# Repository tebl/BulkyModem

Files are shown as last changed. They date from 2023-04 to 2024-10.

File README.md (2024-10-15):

# BulkyModem
Back in the old days I, like many others, had a modem. Wasn't quite as old that it used an acoustic coupler, but certainly old enough that it still made exciting clicks when connecting up to things. It also made a lot of horrible shrieking noises when it finally got to talk to an actual computer, if someone else was to pick up the phone while you were using it - you'd usually get to hear a bit of swearing before enjoying the task of doing it all over again. The *BulkyModem* doesn't even hope to do all of those things, but it does allow me to have a go at dialing into a *BBS* from the comforts of my old PCs again. It doesn't do any of that over an analog phone line, because: A) Those no longer exist, and B) We're living in the far distant future, and we now have Wi-Fi!

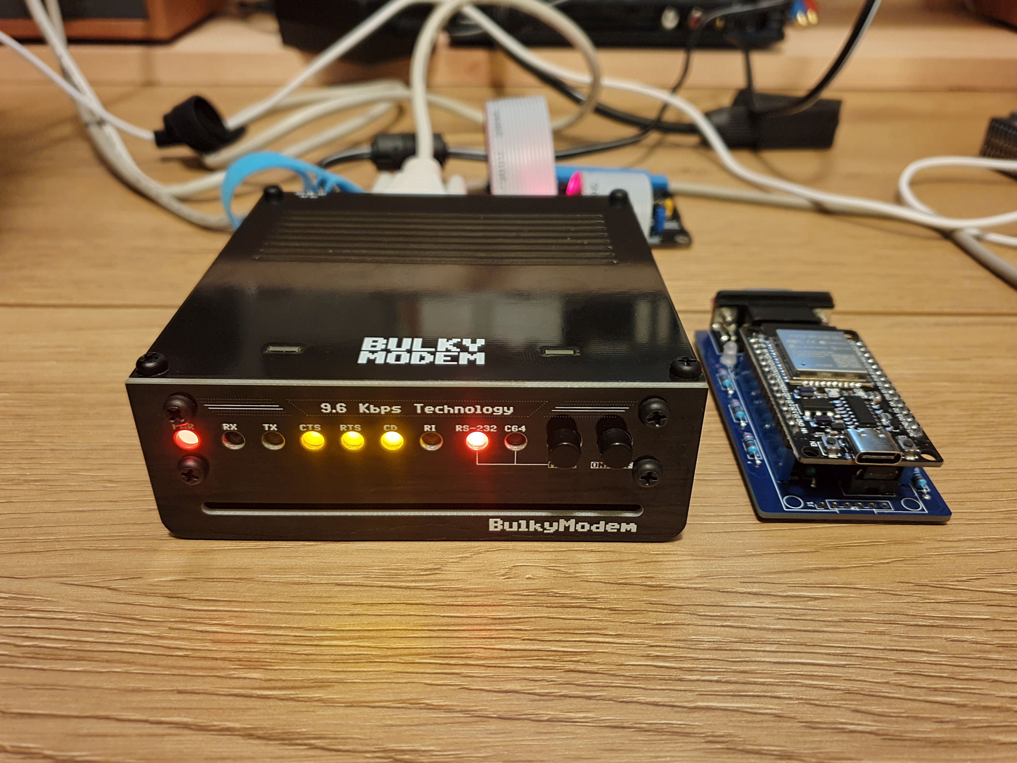
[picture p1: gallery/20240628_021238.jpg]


While there are many options for modems out there that already do the same thing, even quite cool ones that are still being hand-assembled and sold as *Retro WiFi modems* in just about every corner of the world. Or, so I assume anyway. The reason being that if you can find a suitably aged *nerd* tinkering away on their old computer, then they might have been part of the golden age of communication. The other earlier golden age, the one we were talking about before the World Wide Web was unleashed upon the world. Anyway, if you find one of those then there's probably a modem already in their workshop, or possibly in the mail somewhere. So where does my little project fit into all of this? Not sure, but I sure wanted to build one. And the solution I came up with, temporarily fits a very specific spot on my desk.

Where does this one differentiate from the rest of the options then? For that I need to say a bit about my goals when developing it. First off, I wanted to merge old technology with the new - that's not a shocker to anyone who has seen any of my other projects. The second is where this might start becoming of interesting to you, it's the part where I didn't want to build a modem that would only ever work over either *RS-232* - or - attached to a *Commodore 64/128 User Port*. Instead of forcing you to choose, I put a *mode*-button on the front that rewires things between the two modes. Technically that still requires a choice, but did I mention that it was a button? And it's implemented in *hardware*! 

'That's madness', I clearly hear you shouting at the screen. Possibly scaring a cat while you were doing so. Well, it certainly is!

Which is probably the reason for why I started this project all the way back when these retro modems were  still considered a *new* thing, it just took me a while. Mostly because I couldn't get all of it working at the same time. It was never really supposed to work while connected to two different systems at the same time, that would be a whole different bag of crazy - I just wanted the *mode*-button to work as previously advertised. And two years later it mostly does. Turns out that juggling chronic fatigue, *RS-232* signal names and a screaming toddler at the same time, also means that you're bound to strike out quite a few times. My last stumbling block was that I had one ESP8266 development boards that worked perfectly, and five that mostly did nothing. After three revisions I ended up with five that worked with the addition of a simple diode, it was just that without it - I couldn't get anywhere without figuring out how to actually use an oscilloscope. The twist at the end was that the final board that didn't work at the end, wasn't a twist because the working one just kept working. The sixth was just broken from the start, a fact that seems to align with my batting average for cheap development boards.

As for going all the way in order to not require any changes to the firmware, I later added some *optional*. Some of those will require an update to the firmware, if I ever get around to making them. We'll well and truly burn that bridge if I ever get around to crossing it, but for now - just pretend that those don't exist! You didn't need them anyway.

For the project background, all of this started with an article: [Build your own 9600 Baud C64 WiFi Modem For $10](https://1200baud.wordpress.com/2017/03/04/build-your-own-9600-baud-c64-wifi-modem-for-20/). It goes through all of the steps for building a simple version of this with a specially prepared version of the [Zimodem](https://github.com/bozimmerman/Zimodem)-firmware that was made available when the article was written. For a new project that sounds more outdated than retro, I'm going with the shiny new version instead.

- [1> Modules](#1-modules)
  - [1.1> BulkyModem](#11-bulkymodem)
  - [1.3> BulkyModem-32](#13-bulkymodem-32)
  - [1.4> BulkyModem-32 (Mini RS-232)](#14-bulkymodem-32-mini-rs-232)
  - [1.5> BulkyModem Terminal](#15-bulkymodem-terminal)
- [2> Adapters](#2-adapters)
- [3> Acknowledgements](#3-acknowledgements)

# 1> Modules
For the technical details as well as information regarding the devices included in this specific GitHub-project, consult the table below to jump to that particular section. Note that in order to successfully use the *BulkyModem* or *BulkyModem-32* along with a Commodore 64, you will also need the *User Port*-adapter found within the [adapters](#2-adapters)-section.

| Module | Description |
| --- | --- |
| [BulkyModem](#11-bulkymodem) | *BulkyModem*-variant based on ESP8266.
| [BulkyModem-32](#13-bulkymodem-32) | *BulkyModem*-variant based on ESP32.
| [BulkyModem-32 (Mini RS-232)](#14-bulkymodem-32-mini-rs-232) | "Mini"-version of the BulkyModem-32 with an RS-232 interface.
| [BulkyModem Terminal](#15-bulkymodem-terminal) | An instant-on video terminal based on [VersaTerm](https://github.com/dhansel/VersaTerm)

## 1.1> BulkyModem
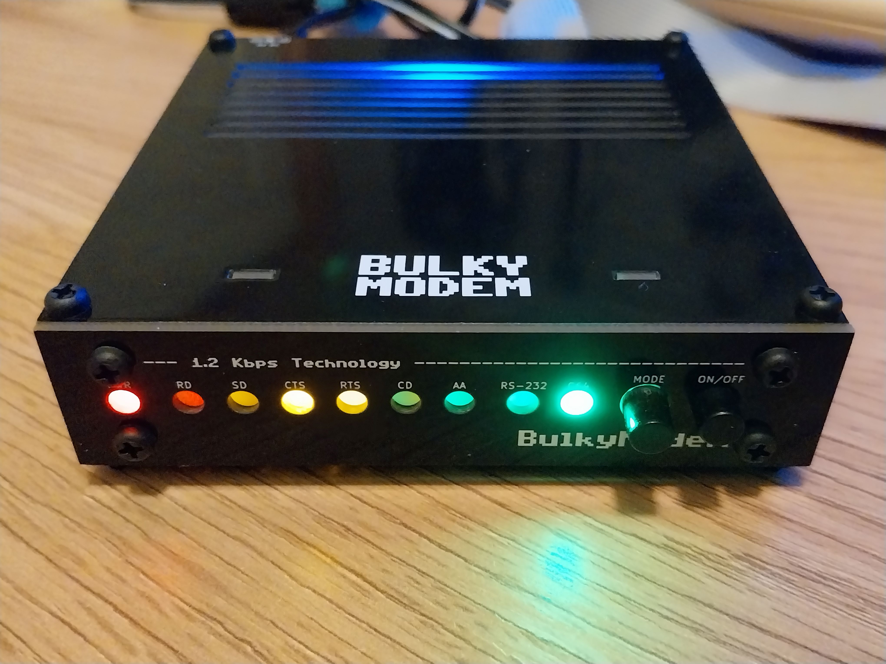
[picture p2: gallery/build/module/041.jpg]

**Status:** Completed

This is the main module of the project, if you came here looking to build an ESP8266-based retro modem then you've come to the right place. You have the option of going the cheaper route of just building things up on the basic module by itself, consisting only of the main module and nothing else. Alternatively, and this is probably the only reason to build a *BulkyModem* - and that's to build the whole thing as shown above. Note that the list below will include alternate versions of boards, so you need to decide which of them you'll need based on their description.

| Module | Required | Description | Documentation | Order |
| --- | --- | --- | --- | --- |
| [BulkyModem](https://github.com/tebl/BulkyModem/tree/main/BulkyModem%20Module) | Yes | Main module | [Documentation](https://github.com/tebl/BulkyModem/tree/main/BulkyModem%20Module), [BOM](https://github.com/tebl/BulkyModem/tree/main/BulkyModem%20Module/README.md#3-bom), [Setting it up](https://github.com/tebl/BulkyModem/blob/main/documentation/setting_it_up.md), [Getting started](https://github.com/tebl/BulkyModem/blob/main/documentation/getting_started.md) | [PCBWay](https://www.pcbway.com/project/shareproject/BulkyModem_e6d2ed59.html)
| [BulkyModem Panel](https://github.com/tebl/BulkyModem/tree/main/BulkyModem%20Module%20Panel) | Recommended | Adds a vertical surface for mounting switches and LEDs. | [Documentation](https://github.com/tebl/BulkyModem/tree/main/BulkyModem%20Module%20Panel), [BOM](https://github.com/tebl/BulkyModem/tree/main/BulkyModem%20Module%20Panel/README.md#3-bom) | [PCBWay](https://www.pcbway.com/project/shareproject/BulkyModem_Panel_a5862704.html)
| :repeat_one: [BulkyModem Panel B](https://github.com/tebl/BulkyModem/tree/main/BulkyModem%20Module%20Panel%20B) | Alternative | Similar to above, but uses an RGB LED as a power indicator. Lights up a different colour when in *standby*. | [Documentation](https://github.com/tebl/BulkyModem/tree/main/BulkyModem%20Module%20Panel%20B), [BOM](https://github.com/tebl/BulkyModem/tree/main/BulkyModem%20Module%20Panel%20B/README.md#3-bom) | PCBWay
| [BulkyModem Front faceplate (FP3)](https://github.com/tebl/BulkyModem/tree/main/faceplates/BulkyModem%20FP3) | Recommended | Decorative front panel, mounts on either of the front panels. Has a more futuristic design. | [Documentation](https://github.com/tebl/BulkyModem/tree/main/faceplates/BulkyModem%20FP3) | [PCBWay](https://www.pcbway.com/project/shareproject/BulkyModem_Faceplate_FP3_e1a3cebd.html)
| :repeat_one: [BulkyModem Front faceplate (FP2)](https://github.com/tebl/BulkyModem/tree/main/faceplates/BulkyModem%20FP2) | Alternative | Decorative front panel, mounts on either of the front panels. Has a more minimalistic design. | [Documentation](https://github.com/tebl/BulkyModem/tree/main/faceplates/BulkyModem%20FP2) | PCBWay
| :repeat_one: [BulkyModem Front faceplate (FP1)](https://github.com/tebl/BulkyModem/tree/main/faceplates/BulkyModem%20FP1) | Alternative | Decorative front panel, mounts on either of the front panels. Shorter version (same as shown above). | [Documentation](https://github.com/tebl/BulkyModem/tree/main/faceplates/BulkyModem%20FP1) | [PCBWay](https://www.pcbway.com/project/shareproject/BulkyModem_Faceplate_FP1_738ec333.html)
| [BulkyModem Top/bottom faceplate (FA1)](https://github.com/tebl/BulkyModem/tree/main/faceplates/BulkyModem%20FA1) | Recommended | Decorative faceplate used on the top of the device, can also be used on the bottom in combination with front faceplate [FP2](https://github.com/tebl/BulkyModem/tree/main/faceplates/BulkyModem%20FP2)/[FP3](https://github.com/tebl/BulkyModem/tree/main/faceplates/BulkyModem%20FP3). | [Documentation](https://github.com/tebl/BulkyModem/tree/main/faceplates/BulkyModem%20FA1) | [PCBWay](https://www.pcbway.com/project/shareproject/BulkyModem_Faceplate_FA1_2696aeda.html)

**NB!** Make sure to follow the links for each of the modules, especially when you're looking into ordering the parts needed to complete the device that you want to build. Those modules are listed with their own link to a BOM, or at least what I would call one. Also keep in mind that to use this with a Commodore 64, you need the *User Port*-adapter that's found in the [adapters](#2-adapters)-section.

## 1.3> BulkyModem-32
BulkyModem
**Status:** Working, documentation missing

The *BulkyModem-32* is a variant of the modem based on the ESP32, offering some additional features when compared to the [BulkyModem](#11-bulkymodem) that was based on the older and more limited ESP8266. More specifically you'll have access to several additional commands and protocols when using this variant, it also includes an SD-card slot so that you can transfer files between the computer and the modem.

For building one of these things you have the option of going the cheaper route of just using the main PCB, leaving you with the main module and nothing else. Alternatively, and this is probably the only reason why you'd want to build a *BulkyModem* - and that's to go for the whole thing as shown above. Note that there will be alternate versions of some of these boards, so you'll need to decide which of them you want based on their description.

| Module | Required | Description | Documentation | Order |
| --- | --- | --- | --- | --- |
| [BulkyModem-32](https://github.com/tebl/BulkyModem/tree/main/BulkyModem-32%20Module) | Yes | Main module | [Documentation](https://github.com/tebl/BulkyModem/tree/main/BulkyModem-32%20Module), [BOM](https://github.com/tebl/BulkyModem/tree/main/BulkyModem-32%20Module/README.md#3-bom), [Setting it up](https://github.com/tebl/BulkyModem/blob/main/documentation/setting_it_up.md), [Getting started](https://github.com/tebl/BulkyModem/blob/main/documentation/getting_started.md) | PCBWay
| [BulkyModem Panel](https://github.com/tebl/BulkyModem/tree/main/BulkyModem%20Module%20Panel) | Recommended | Adds a vertical surface for mounting switches and LEDs. | [Documentation](https://github.com/tebl/BulkyModem/tree/main/BulkyModem%20Module%20Panel), [BOM](https://github.com/tebl/BulkyModem/tree/main/BulkyModem%20Module%20Panel/README.md#3-bom) | [PCBWay](https://www.pcbway.com/project/shareproject/BulkyModem_Panel_a5862704.html)
| :repeat_one: [BulkyModem Panel B](https://github.com/tebl/BulkyModem/tree/main/BulkyModem%20Module%20Panel%20B) | Alternative | Similar to above, but uses an RGB LED as a power indicator. Lights up a different colour when in *standby*. | [Documentation](https://github.com/tebl/BulkyModem/tree/main/BulkyModem%20Module%20Panel%20B), [BOM](https://github.com/tebl/BulkyModem/tree/main/BulkyModem%20Module%20Panel%20B/README.md#3-bom) | PCBWay
| [BulkyModem Front faceplate (FP3)](https://github.com/tebl/BulkyModem/tree/main/faceplates/BulkyModem%20FP3) | Recommended | Decorative front panel, mounts on either of the front panels. Has a more futuristic design. | [Documentation](https://github.com/tebl/BulkyModem/tree/main/faceplates/BulkyModem%20FP3) | [PCBWay](https://www.pcbway.com/project/shareproject/BulkyModem_Faceplate_FP3_e1a3cebd.html)
| :repeat_one: [BulkyModem Front faceplate (FP2)](https://github.com/tebl/BulkyModem/tree/main/faceplates/BulkyModem%20FP2) | Alternative | Decorative front panel, mounts on either of the front panels. Has a more minimalistic design. | [Documentation](https://github.com/tebl/BulkyModem/tree/main/faceplates/BulkyModem%20FP2) | PCBWay
| [BulkyModem Top/bottom faceplate (FB1)](https://github.com/tebl/BulkyModem/tree/main/faceplates/BulkyModem%20FB1) | Recommended | Decorative faceplate used on the top of the device, can also be used on the bottom in combination with front faceplate [FP2](https://github.com/tebl/BulkyModem/tree/main/faceplates/BulkyModem%20FP2)/[FP3](https://github.com/tebl/BulkyModem/tree/main/faceplates/BulkyModem%20FP3). | [Documentation](https://github.com/tebl/BulkyModem/tree/main/faceplates/BulkyModem%20FB1) | PCBWay

**NB!** Make sure to follow the links for each of the modules, especially when you're looking into ordering the parts needed to complete the device that you want to build. Those modules are listed with their own link to a BOM, or at least what I would call one. Also keep in mind that to use this with a Commodore 64, you need the *User Port*-adapter that's found in the [adapters](#2-adapters)-section.

## 1.4> BulkyModem-32 (Mini RS-232)
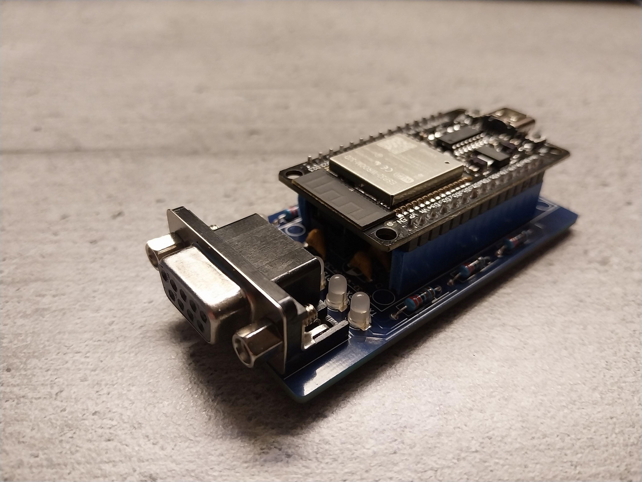
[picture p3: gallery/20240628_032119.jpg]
BulkyModem-32 (Mini RS-232)

**Status:** Completed

Working on the ESP-32 version of the BulkyModem, that's the one called BulkyModem-32, I had quite a few questions of how some of the features were meant to function. So in order to start development in a more sensible place than what I'm known for, I set out to make a smaller "Mini"-version with the core functionality before trying to add anything else to it. The ESP32-version has more functionality available to it in the Zimodem-firmware, that you'll have available to you when hooking it up to your vintage computers over RS-232. The connection is a 5-wire setup, using RTS/CTS as hardware flow control.

| Module | Required | Description | Documentation | Order |
| --- | --- | --- | --- | --- |
| [BulkyModem-32 (Mini RS-232)](https://github.com/tebl/BulkyModem/tree/main/BulkyModem-32%20Mini) | Yes | Main module | [Documentation](https://github.com/tebl/BulkyModem/tree/main/BulkyModem-32%20Mini), [BOM](https://github.com/tebl/BulkyModem/tree/main/BulkyModem-32%20Mini/README.md#3-bom), [Setting it up](https://github.com/tebl/BulkyModem/blob/main/documentation/setting_it_up_mini_rs232.md), [Getting started](https://github.com/tebl/BulkyModem/blob/main/documentation/getting_started.md) | [PCBWay](https://www.pcbway.com/project/shareproject/BulkyModem_32_Mini_RS_232_e6ccfb60.html)

## 1.5> BulkyModem Terminal
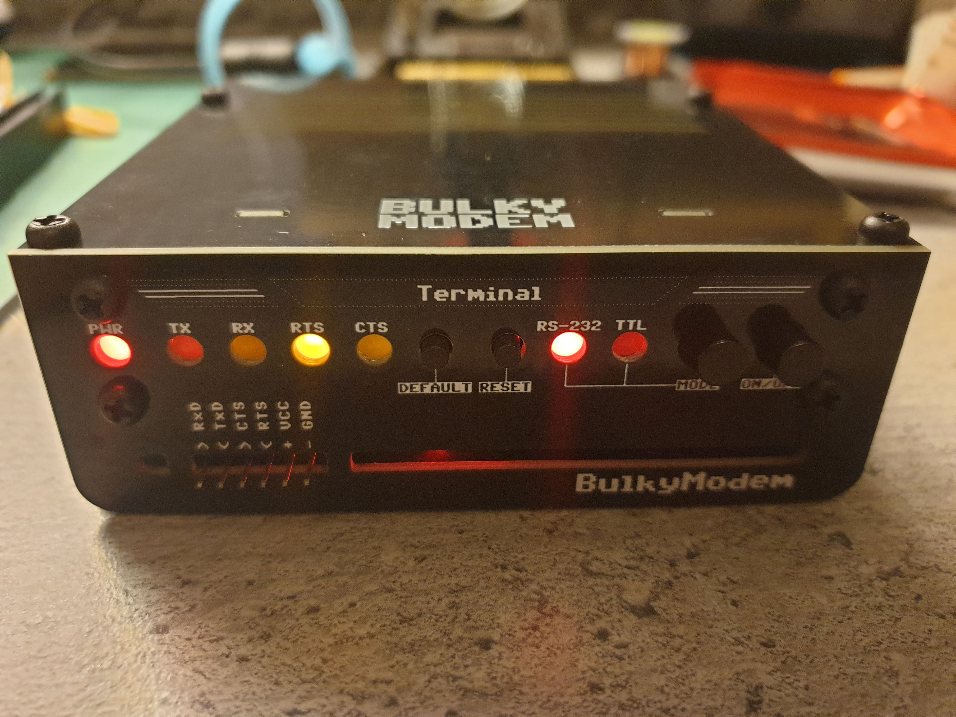
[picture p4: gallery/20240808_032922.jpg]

**Status:** Working, documentation missing

Building a modem comes with its own set of rewards, and in terms of *RS-232* these are what we will define as being *Data Communications Equipment (DCE)*. The other end, normally what we would think of as a computer, is instead labelled as *Data Terminal Equipment (DTE)*. With *RS-232* we have different wires serving different purposes, so one would have different names on each of these two ends - quite possibly being the reason why this kind of information naturally slides off my brain like water off a duck's back. So naturally I wanted to climb that mountain anyway.

So what does it do then? The idea is that instead of having your homebrew computer such as RC2014, RC6502 and similar living inside a terminal emulator program such as PuTTy or Tera Term on your regular computer, you have something that can do the same except without the distractions of the modern computer. Kind of like the original great devices such as the actual DEC VT101, used to hook up to and talk to early mainframes. For sure, I could have used better examples than what mostly amounts to a bunch of computers hooked up to each other, but I was really looking for something that wasn't just a modem. The point is that you hook up your VGA-monitor, your favorite PS/2 keyboard and then you're free to communicate over serial without notifications, updates and all that. Even if you just put a modem on the end, just so that you could chat on a *BBS*.

How did I manage to do all this? I didn't. What I did was discover that someone had already made one, they did it with everyone's favorite new microcontroller - Raspberry Pi Pico - and dubbed it [VersaTerm](https://github.com/dhansel/VersaTerm). What I did was remove a few features in order to make one that would look really pretty, as well as fit with the overall design of the *BulkyModem*. If you want the whole thing, check out the original project. You'll need to go there in order to grab the firmware to build mine anyway, so you might as well check it out before deciding.

For the build you have the option of going the cheaper route of just building things up on the basic module by itself, consisting only of the main module and nothing else. Alternatively, and this is probably the only reason to build a *BulkyModem Terminal* in the first place, and that's to build the whole thing as shown above. There will be alternate versions of some of the board designs, so you need to decide on which one of them you'll need based on their description below.

| Module | Required | Description | Documentation | Order |
| --- | --- | --- | --- | --- |
| [BulkyModem Terminal](https://github.com/tebl/BulkyModem/tree/main/BulkyModem%20Terminal) | Yes | Main module | [Documentation](https://github.com/tebl/BulkyModem/tree/main/BulkyModem%20Terminal), [BOM](https://github.com/tebl/BulkyModem/tree/main/BulkyModem%20Terminal/README.md#3-bom) | PCBWay
| [BulkyModem Terminal Panel](https://github.com/tebl/BulkyModem/tree/main/BulkyModem%20Terminal%20Panel) | Recommended | Adds a vertical surface for mounting switches and LEDs. | [Documentation](https://github.com/tebl/BulkyModem/tree/main/BulkyModem%20Terminal%20Panel), [BOM](https://github.com/tebl/BulkyModem/tree/main/BulkyModem%20Terminal%20Panel/README.md#3-bom) | PCBWay
| [BulkyModem Terminal Front faceplate (FP3)](https://github.com/tebl/BulkyModem/tree/main/faceplates/BulkyModem%20Terminal%20FP3) | Recommended | Decorative front panel, mounts on either of the front panels. Has a more futuristic design. | [Documentation](https://github.com/tebl/BulkyModem/tree/main/faceplates/BulkyModem%20Terminal%20FP3) | PCBWay
| [BulkyModem Terminal Top/bottom faceplate (FA1)](https://github.com/tebl/BulkyModem/tree/main/faceplates/BulkyModem%20Terminal%20FA1) | Recommended | Decorative faceplate used on the top of the device, can also be used on the bottom in combination with front faceplate [Terminal FP3](https://github.com/tebl/BulkyModem/tree/main/faceplates/BulkyModem%20Terminal%20FP3). | [Documentation](https://github.com/tebl/BulkyModem/tree/main/faceplates/BulkyModem%20Terminal%20FA1) | PCBWay

# 2> Adapters
Separate from the main modules are several adapters, designed for use with the *BulkyModem*, or *BulkyModem-32*, in combination with various systems. The repository also includes a folder for [schematics](https://github.com/tebl/BulkyModem/tree/main/documentation/schematic) in PDF-format, these will be needed in order to track down any faults you encounter when building up and testing any of the adapters.

| Module | Required | Description | Documentation | Order |
| --- | --- | --- | --- | --- |
| [Commodore 64/128 UserPort](https://github.com/tebl/BulkyModem/tree/main/BulkyModem%20UserPort%20Adapter) | Recommended | Used to connect with Commodore 64/128 over the User Port | [Documentation](https://github.com/tebl/BulkyModem/tree/main/BulkyModem%20UserPort%20Adapter), [BOM](https://github.com/tebl/BulkyModem/tree/main/BulkyModem%20UserPort%20Adapter#3-bom) | [PCBWay](https://www.pcbway.com/project/shareproject/BulkyModem_Commodore_64_128_UserPort_Adapter_a84c7ef6.html)

**NB!** The repository may contain pieces of modules and adapters not explicitly listed here, if they're not listed then they're a work in progress. Some might be functional, others might blow up something or I simply haven't remembered to update the documentation.

# 3> Acknowledgements
Everything comes from something, in particular when it comes to most of my electronics projects. I mainly build things I would like to own, often doing a re-spin in order to fit my own preferences for style over function. The hardest parts of the designs will already have been provided for by people more knowledgeable in things, at least at a scale that I can't hope to match. As mentioned in the introduction, all of this was originated in an article - [Build your own 9600 Baud C64 WiFi Modem For $10](https://1200baud.wordpress.com/2017/03/04/build-your-own-9600-baud-c64-wifi-modem-for-20/). 

The beating heart at the core of almost all of it, is the [Zimodem](https://github.com/bozimmerman/Zimodem)-firmware that runs on an ESP8266/ESP-32. On the C64-side it does have the ability to run at speeds up to 9600 baud which is something that could be met a bit sniggering today, while people at the time would be looking for the butterfly nets. You see, the C64 didn't have an ACIA. There was apparently supposed to be one, but it was removed in order to save on costs. The favored alternative choice then was to attempt to emulate its function, on a computer limited to running at roughly 1 Mhz. In the end your options for modems was the expensive option at 300 baud, followed up by the ridiculously expensive option running at a blistering 1200 baud. The computer actually communicating at 9600 baud in spite of all commonly accepted limitations, is mind-blowing in its execution. For all the details of what ended up being described as *UP9600*, was initially covered in the article [UP9600: How to Bit-Bang 9600 Baud RS-232 on the C64](https://www.pagetable.com/?p=1656). Even if you don't need all that in order to use it, the article is an interesting feat of engineering. Also, it is one of the only sources that I could find that actually describes how serial on the Commodore 64 actually worked, both now and back then.

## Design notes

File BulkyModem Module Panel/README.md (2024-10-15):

# BulkyModem Module Panel
This is a front-facing panel for controlling the original *BulkyModem*, alternatively the functionally similar *BulkyModem-32*. The difference between the two being the type of MCU used in its design, but as for a front panel - this is compatible with both. The installation of such a panel will be covered within the documentation for each of those two designs, but the assembly of the panel itself will be covered herein.

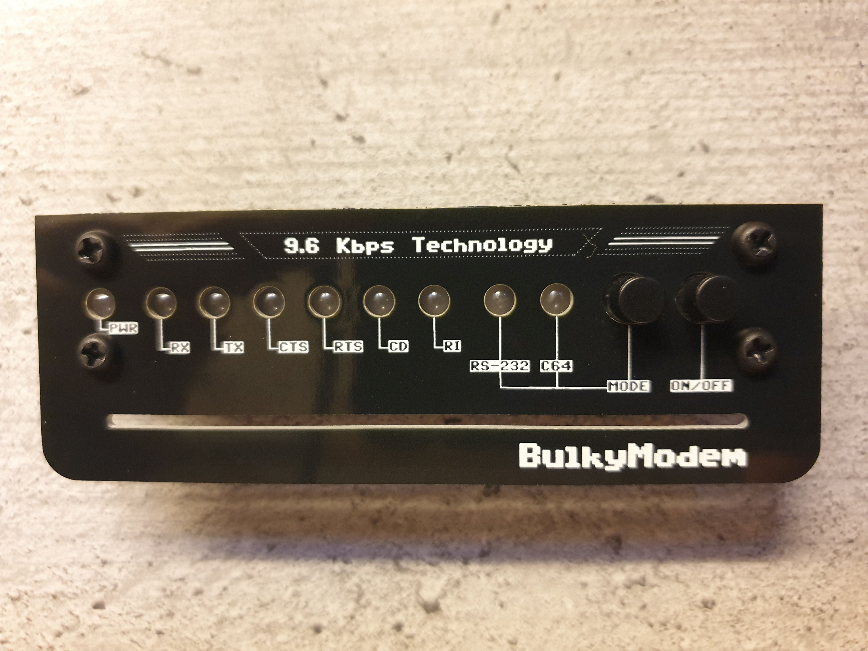
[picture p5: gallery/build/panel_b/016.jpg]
BulkyModem


A front panel is an optional feature and you could quite possibly build a functional design without it, but I feel that it makes the system a lot more enjoyable to use. Along the way I've also developed a second [B-variant](https://github.com/tebl/BulkyModem/tree/main/BulkyModem%20Module%20Panel%20B) of the panel with its primary difference being the use of an RGB LED in place of the power LED, changing the colour when it is on standby. I do, however, recommend that you stick with this version of it. 

- [1> Building the device](#1-building-the-device)
  - [1.1> Soldering it together](#11-soldering-it-together)
- [2> Schematic](#2-schematic)
- [3> BOM](#3-bom)

# 1> Building the device
Building a device such as this assumes you have at least minor experience soldering things together, recommended is that you at the very least have access to a soldering station with adjustable temperature. If currently available, you should probably start with 60/40 rosin core solder as the lead-free alternatives tends to be a bit harder to work with.

With requirements for basic equipment sorted, we need to talk a bit about what you want to achieve while building this project. The reason I ask is that while you can build a functional *BulkyModem* or *BulkyModem-32* using the main PCB by themselves, you're here because you've been looking into building a more complete version of it. That includes a front panel module as well as additional faceplates that would go on the top, bottom and the front of it. That sounds like a lot, but it's worth it. I promise! 

Now that you've arrived at *concepts of a plan* for what you want to build, we can get started on one of the more expensive step in any build process - shopping! For reference, the most expensive step is probably setting your desk and/or house on fire (don't drink and solder). Anyway, when ready to continue with the whole shopping thing that you've heard so much about - head on over to the [BOM](#3-bom)-section. There you'll find information on the kind of components that you'll need.

While I would have liked to give you specific part numbers for "reputable" electronic part suppliers, I can't afford to shop there personally. So what I do, is to make due with what I can find on sites such as eBay, AliExpress or any other future site that will inevitably seem to sell the same, and quite possibly identical set of cheap Chinese components. The downside for you is that I can't link to a part directly and expect it to stay listed tomorrow, so you'll need to consider their descriptions as *suggested search terms* and not *part numbers* in any accurate sense of the definition.

## 1.1> Soldering it together
The construction of this unit should be fairly straight-forward, just take your time in order to make sure everything goes into place - more or less straight. I usually recommend starting by having a good look at the PCBs, try to figure out where all of the listed components should go and in which orientation. All of this should be clearly marked on the silkscreen, but I'll try to cover most of the questionable bits as we get to them.

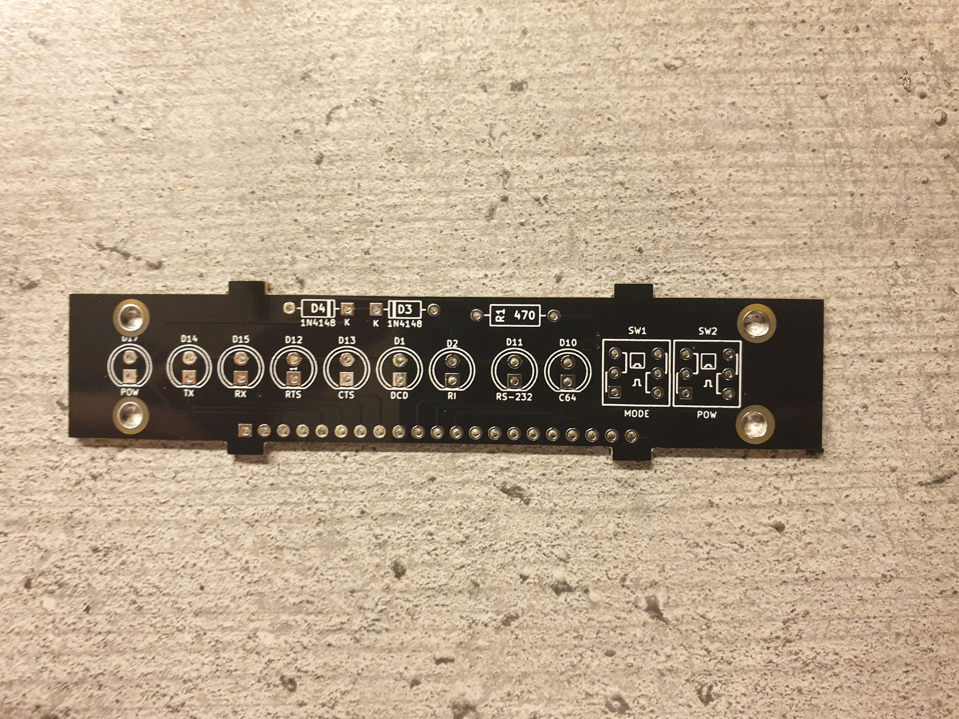
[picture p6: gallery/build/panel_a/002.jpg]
Build 001


**NB!** These pictures were taken when building an earlier revision of the PCB, revision C has the top row of components removed (which also explains why they're missing from the BOM). Sorry about that.

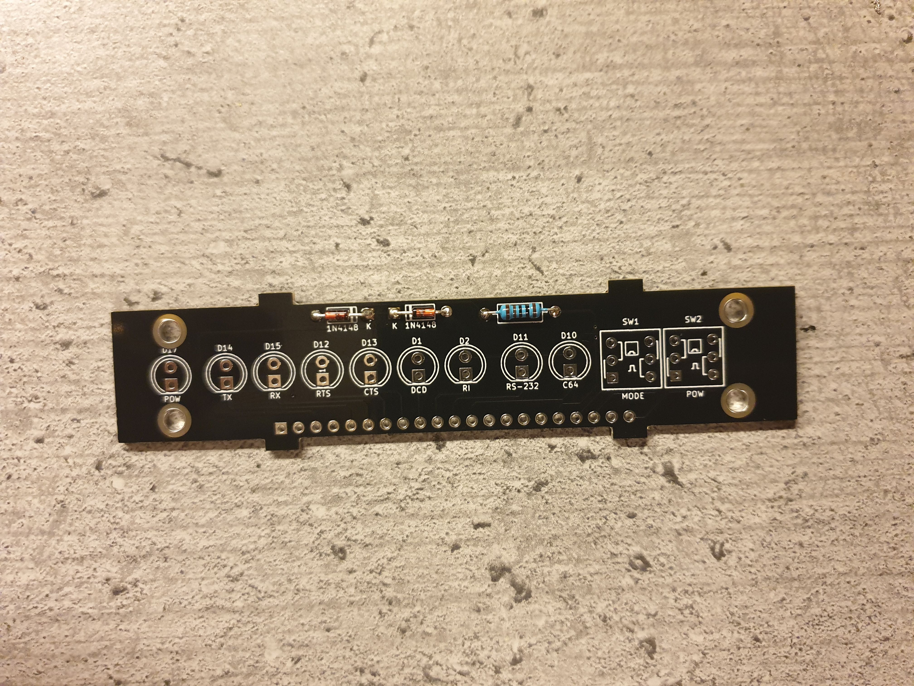
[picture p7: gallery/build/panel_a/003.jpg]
Build 003


Ignoring the two diodes and single resistor that I've already apologized to you for showing you. They're no longer on your PCB, and so you can't install them. Easiest step *ever*!

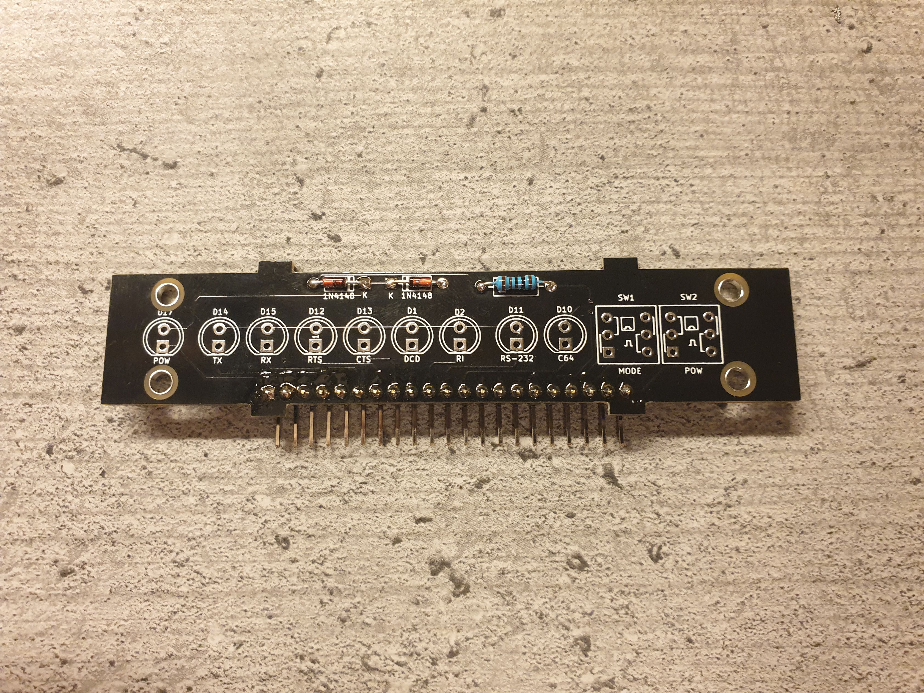
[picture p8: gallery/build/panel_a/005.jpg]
Build 005


The first thing you actually get to install is the some right-angle pin headers, and while you're probably an expert at installing such things - the important bit, is to notice is that we need install it on the reverse-side of the PCB! As for the alignment we have a need for it to sit flush against the PCB, so if possible - start by soldering in the opposing corners. Then reheat and push the plastic body of it flush against the board. Just as an FYI; maybe not touch the same piece of metal as that will heat up quite significantly.

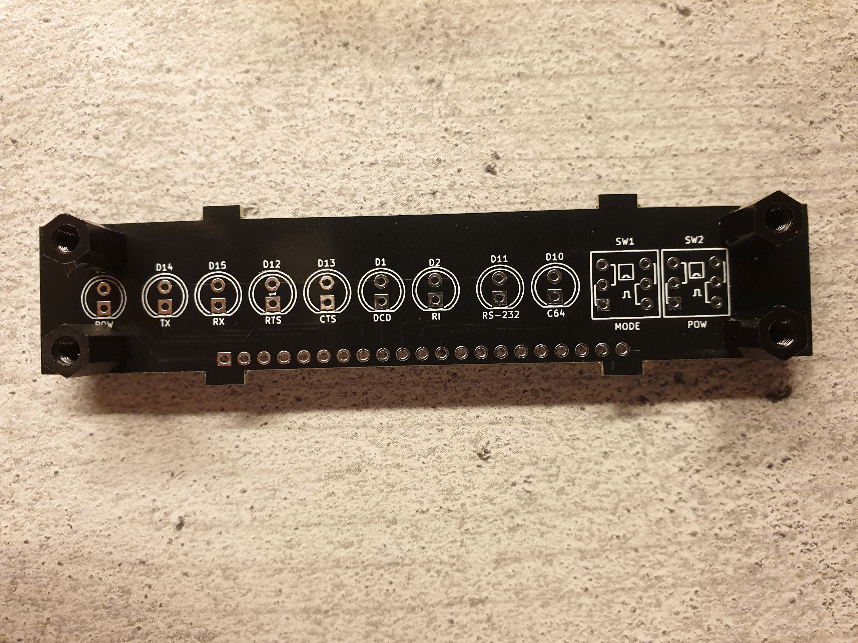
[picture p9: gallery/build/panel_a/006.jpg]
Build 006


As for my next trick, I'm showing you how to install 10mm hex standoffs to each of the four corners (illustrated using a similar, but not exactly the same PCB as shown earlier). The hex shape needs to be rotated so that a flat edge lines up with the left and right edges of the PCB, the reason for this will become evident when we finally attempt to install it onto the main module.

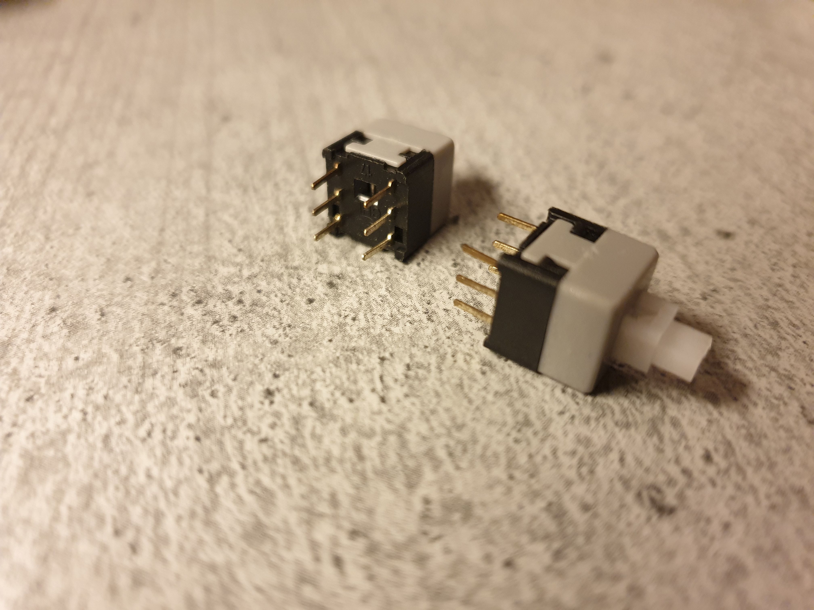
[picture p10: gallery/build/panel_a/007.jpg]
Build 007

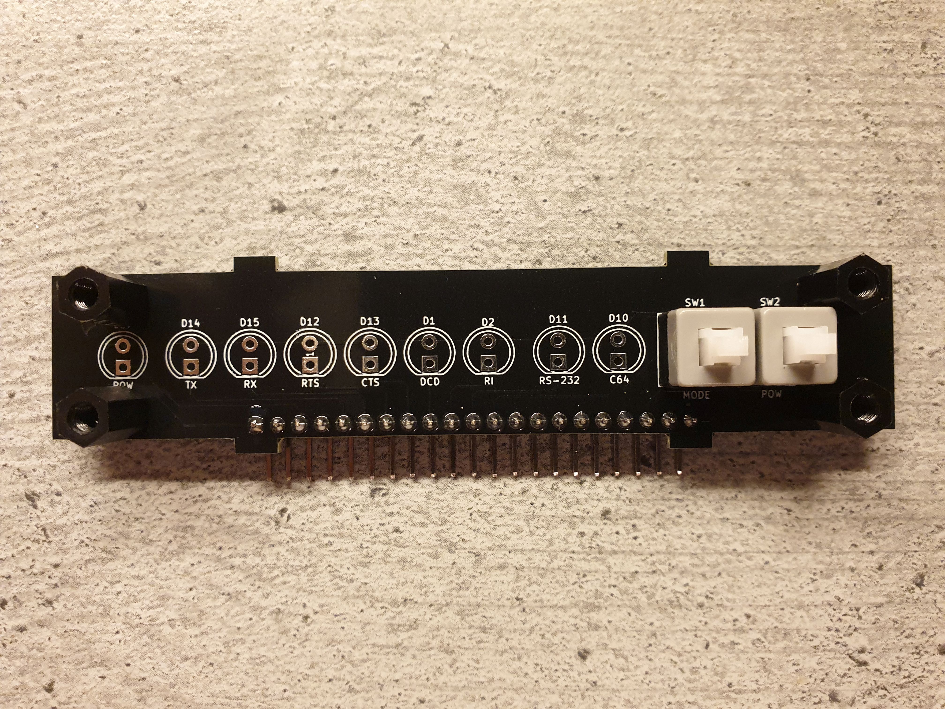
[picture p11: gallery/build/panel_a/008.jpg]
Build 008


The latching switches used should be as shown, in particular you should make sure that the colour of them match up. Seemingly identical switches with a blue base has shown up in my workshop from time to time, but they have a different pinout and won't work with this board design. Looking at the underside of it, you should notice that there's a rectangular hole that's further towards one side of it - this is the same rectangle that's marked on the PCB. While the pictures don't include it, I recommend both picking up and then installing the  black keycaps onto them. Actually doing that might take a bit of force, but they'll usually go on without too much of a fight. As for this step you shouldn't solder anything, just insert them into the correct orientation.

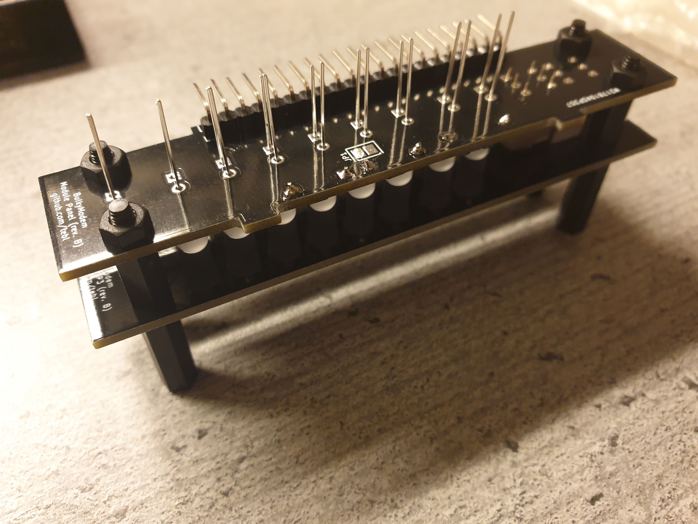
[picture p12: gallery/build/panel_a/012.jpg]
Build 012


The front panel includes a significant amount of indicator LEDs, and like the switches you should only loosely insert them into place without soldering. While each leg of an LED has a name, I always forget which is which - so I'll just tell you to push the longer one into the round pads at the top. As is evident by the markings on the PCB, one side should also have a slightly flattened edge. Said edge might be bit hard to actually see on some of the extremely cheap LEDs I've seen floating around, so don't look too hard for it if you've been shopping at the same places that I have. With everything still threatening to fall out at any given moment, add your chosen front faceplate onto the top of it all. Fix temporarily into place using some leftover standoffs.

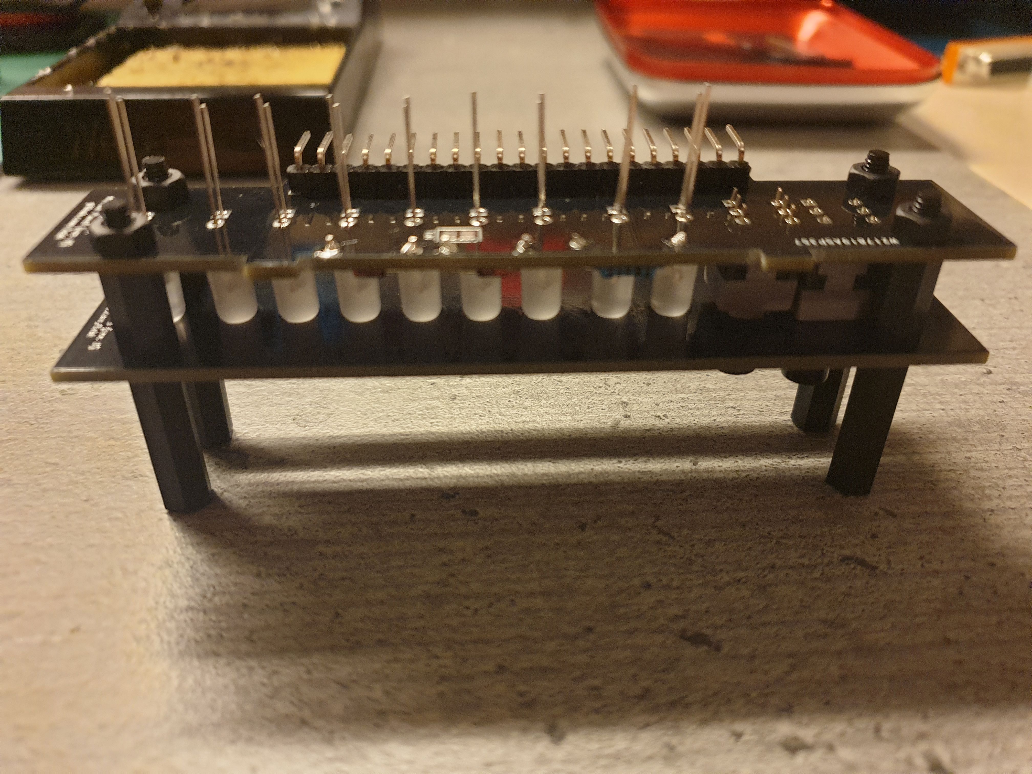
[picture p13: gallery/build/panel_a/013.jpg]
Build 013


At this point, most of the LEDs should fall into their corresponding cutouts on the front faceplate, at which point you should be able to solder in one leg of each of them at a time. I prefer to reheat them and immediately press down on the other pin, that way I'm certain that each will end up sitting flush against the cutouts before soldering the rest. As for the switches you will need to press against it from the top, or actually the bottom from this angle, so that it also stays flush. The usage of the black keycaps mentioned earlier will ensure that they end up sitting in their correct position, but if needed: solder one pin, ensure that the switch can move freely, and then soldering remaining pins.

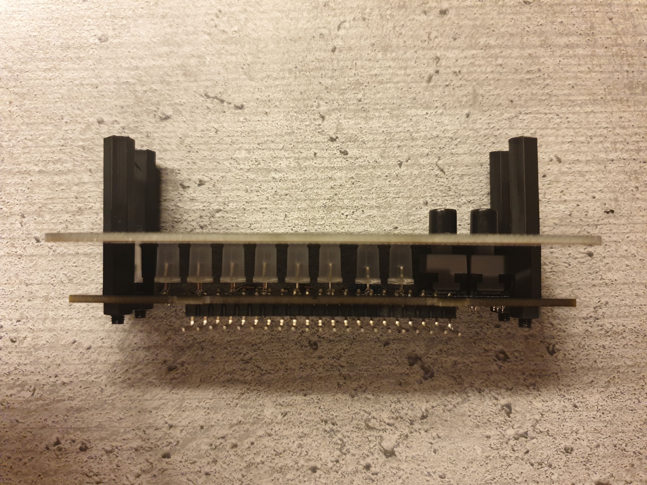
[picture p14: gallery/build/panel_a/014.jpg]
Build 014

Build 016

As for the remaining tasks, I've just cut off the excess from the LED pins before replacing all temporary standoffs with screws. As for this part of the assembly, I think that just about wraps it up. The actual installation of the module will be covered in the relevant part of the document for assembling either the [BulkyModem](https://github.com/tebl/BulkyModem/tree/main/BulkyModem%20Module), or alternatively the [BulkyModem-32](https://github.com/tebl/BulkyModem/tree/main/BulkyModem-32%20Module).

# 2> Schematic
The supplied KiCad files should be sufficient as both a schematic and as a  starting point for ordering PCBs. Most if not all fabrication companies will expect Gerber-files, these are generated from KiCAD though you will be able to bypass this step by using PCBway shared projects. As for the schematic, one has been provided for you in [PDF-format](https://github.com/tebl/BulkyModem/tree/main/documentation/schematic) - an important source of information when things inevitably fail to work as advertised.

# 3> BOM
Most parts should be easy to get a hold of from your favourite local electronic component shop, but given that I don't have access to such shops where I live so everything was based on whatever I could get cheapest from eBay/AliExpress (free shipping, but plan on waiting 3-4 weeks for delivery).

| Reference | Item | Count | Order  |
| --- | --- | ----- | --- |
| Panel PCB | Fabricate using Gerber files | 1 | [PCBWay](https://www.pcbway.com/project/shareproject/BulkyModem_Panel_a5862704.html)
| D1,D2,D10-D15,D17 *1  | 5mm LEDs | 9 |
| J1 | Breakable right-angle pin header | 1 |
| SW1,SW2 | 6pin 8.5mm x 8.5mm latching switch (including keycap) | 2 |
| Mounting *2 | Nylon M3 hex standoffs 10mm (M-F) | 4 |
| Mounting *2 | Nylon M3x6mm nylon screws | 4 |
| Mounting *2 | Nylon M3x6mm nylon nuts | 4 |

1) I highly recommend using frosted LEDs, but if you can only find clear ones then you could always frost them a bit yourself using sandpaper or some sort of polishing tool. Personally I prefer using two sets of colours, one for POW/RS-232/C64 and another for the rest. Do note that the corresponding resistor on the main unit must be sized accordingly to differences in colour, or just plain preferences.
2) These are available in the form of kits usually advertised *M3 nylon standoff kit* which should contain most of what you'd need. I do however recommend that you pick up extra M-F standoffs of lengths 10mm and 20mm, as quite a lot of them will be used when building more than one complete module.

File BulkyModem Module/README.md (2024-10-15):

# BulkyModem Module
This it it! This is the project that defined this repository! Confusingly having the same name, in a repository that to this date includes several other devices that do the same thing subtly different ways. As all of them, it's a modem for vintage computers. And if you want more details about what this is really about, check out the [root of this repository](https://github.com/tebl/BulkyModem) before continuing.

BulkyModem
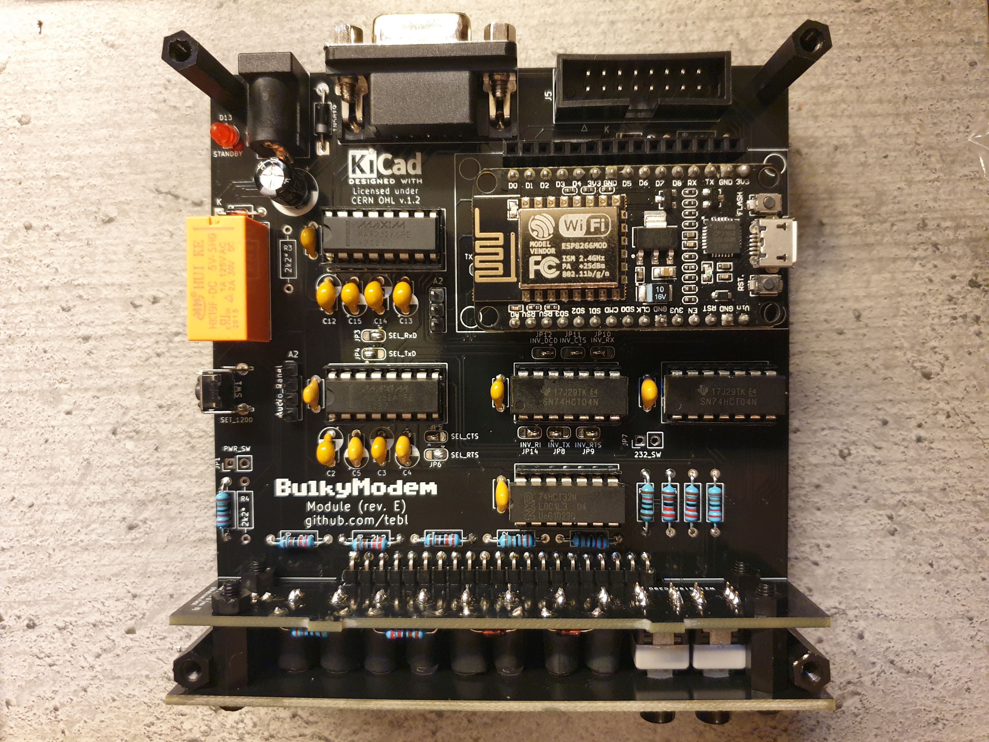
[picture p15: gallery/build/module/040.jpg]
Naked BulkyModem


The *BulkyModem* is based on [Zimodem](https://github.com/bozimmerman/Zimodem), a device that is commonly built in one of two variants: one more general communications device that communicates over RS-232, the second one is a device that connects directly to the *User Port* on a Commodore 64. I don't know about you, but if you were to take a hard look at the things in my basement then you'd find more vintage computers than what my wife probably think that I have (fiercely protected by a rabid dog, claymores etc). Long story short; I have several that fit into either category. So I didn't want to choose one, when I could simply ~~walk into Mordor~~ make one that would be able to work with either. In the hardest way possible by doing it in hardware, at least compared to just forking my own version of the firmware (that would never be able to keep up to date). At its core is your local garden-variety of ESP8266 development boards, sold in all the regular affordable prices as the NodeMCU version 2 or 3.

**NB!** There is also such a thing as the *BulkyModem-32*, where the "32" indicates that it is instead based on common ESP-32 development boards. It has the same features as this one, including a few *extra* ones though nothing that you'd miss if you weren't already aware of their existence. That variant comes with its own set of [documentation](https://github.com/tebl/BulkyModem/tree/main/BulkyModem-32%20Module), and while you're welcome to keep reading below this point - you'll need to read those when building it instead.

- [1> Building the device](#1-building-the-device)
  - [1.1> Soldering it together](#11-soldering-it-together)
  - [1.2> Putting up a front](#12-putting-up-a-front)
  - [1.3> Integrating circuitry](#13-integrating-circuitry)
  - [1.4> Keeping up with the Commodore](#14-keeping-up-with-the-commodore)
  - [1.5> Finishing touches](#15-finishing-touches)
- [2> Schematic](#2-schematic)
- [3> BOM](#3-bom)

# 1> Building the device
Building a device such as this assumes you have at least minor experience soldering things together, my recommendation is that you at the very least have access to a soldering station with a digital temperature adjustment. If such a thing can be considered commercially available where you live, then you should consider starting with 60/40 rosin core solder as the lead-free alternatives tends to be a bit harder to work with.

With requirements for basic equipment sorted, we need to talk a bit about what you want to achieve while building this project. The reason I ask is that while you can build a functional *BulkyModem* using this single PCB by itself, you can also choose to build the complete version of it - including front panels, faceplates and a whole lot of components intended to make it work and look the way I wanted it to. I won't be covering the task of building cheaper or custom versions of it in any great detail, mostly because the concept of the *BulkyModem* is that it shouldn't end up looking like a science experiment. Look into the ["Mini"-variants](https://github.com/tebl/BulkyModem/blob/main/README.md#1-modules) if you just want something that is smaller, or significantly cheaper.

Now that you know have *concepts of a plan* for what you want to build, we can get started on one of the more expensive steps in any build process - shopping! For reference, the most expensive step is probably setting your desk and/or house on fire. Don't be one of those guys! Anyway, when ready to perform the whole shopping thing - head on over to the [BOM](#3-bom)-section for some information on what kind of components that you'll need. While I would have liked to give you specific part numbers for "reputable" electronic part suppliers, I can't afford to shop there. So what I do is to make due with what I can find on sites such as eBay, AliExpress or any other similar sites that seem to sell the same, and quite possibly identical, set of cheap Chinese components. The downside is that I can't link to a part directly and expect it to stay listed tomorrow, so you'll need to consider the description listed more in the category of *suggested search terms* and not *part numbers* in any accurate sense of the definition.

**NB!** Note, however, that the component list found on this page only lists the components required for assembling the main PCB by itself. Those required by the [front panel](https://github.com/tebl/BulkyModem/blob/main/BulkyModem%20Module%20Panel/README.md#3-bom) and [Commodore 64 User Port Adapter](https://github.com/tebl/BulkyModem/blob/main/BulkyModem%20UserPort%20Adapter/README.md#3-bom) are not included in this list, so make sure to browse around.

## 1.1> Soldering it together
Soldering the device together should be a fairly straight-forward affair, just take your time and work your way through the described process before actually attempting to do so. There are some important components that absolutely need to be installed in their correct orientation, and from experience I can tell you that it is significantly easier to do it right in the first place, than it is to desolder and try again.

As mentioned in not so many words, there are options for living without a front panel by skipping out on components components that could be installed on this PCB for the cheaper option. Contrary to what one might first come to assume is that when you want to build the complete version of the *BulkyModem*, then you will want to leave out the positions for 3mm LEDs found at the bottom of your PCB.

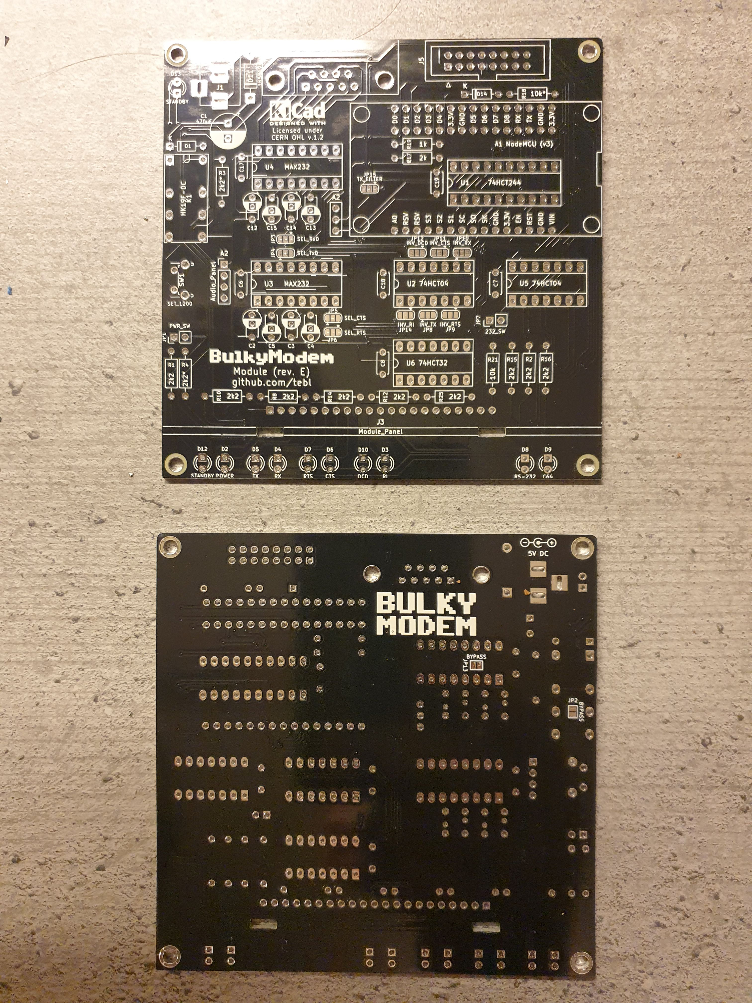
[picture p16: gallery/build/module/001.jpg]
Build 001


I usually recommend starting by having a good look at the PCBs, try to figure out where all of the listed components go and in which orientation they go in (all of this should be clearly marked on the silkscreen). I will usually try to install components in the order of their physical size, meaning that you'll have an easier time trying to keep everything from looking somewhat *wonky*. This is ultimately your board, your build and you want it perfect, don't you? If you said no, then go sit in the corner because I worked hard on creating this for myself and whoever wants to build one.

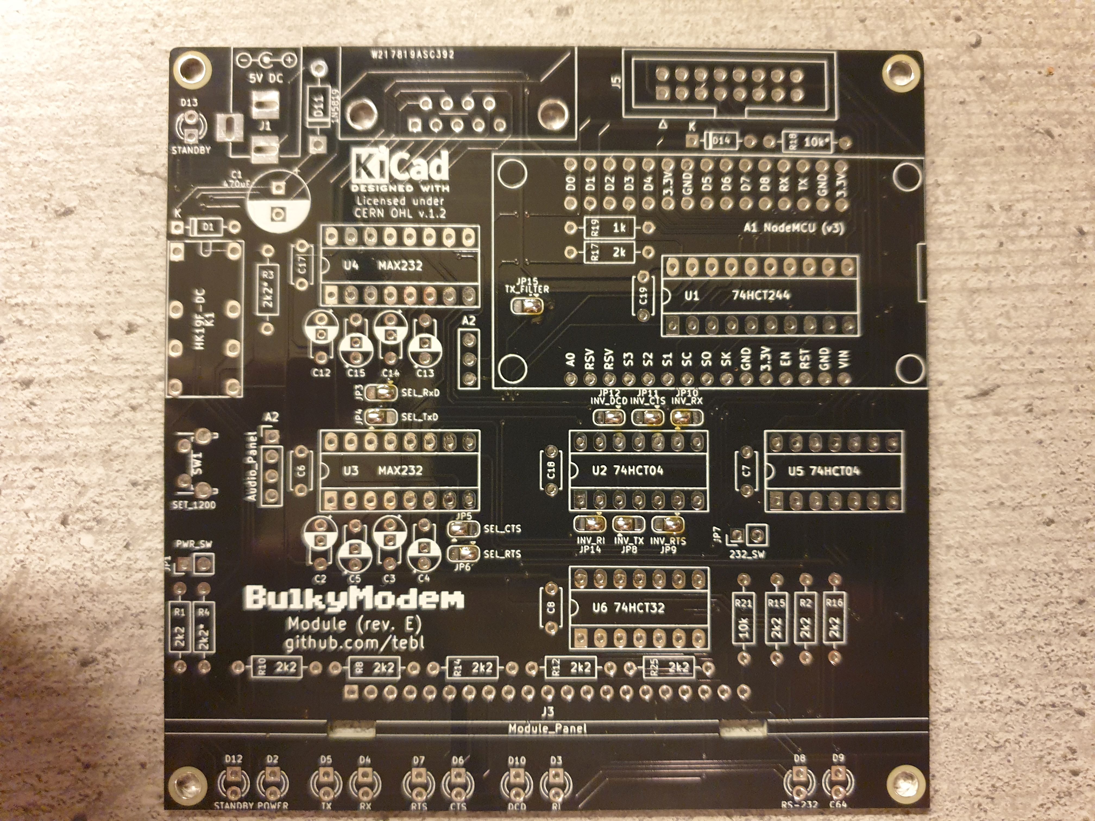
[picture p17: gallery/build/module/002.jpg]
Build 002


As for the first step we've actually not installed any components, we've simply taken the step of soldering all of the little solder bridges that are required in order to make it work. While there may be an actual reason for why they're still here, but I didn't want to do a whole revision of the design just to have them hardwired into place. Check out the schematic for what could be considered significantly more informative (the little triangle denotes pin 1), at least beyond explicitly telling you to set them **exactly** like the picture above. While the pads themselves are quite small, they're usually harder to short than you might expect. Just add solder to it then keep dabbing it with your iron until they look right. Measure with a multimeter if you're unsure about the quality of your handiwork.

**NB!** There's a solder bridge on the reverse-side of the PCB, directly below U4. This need to be linked, **only** if you don't intend on installing a chip into the socket. Likewise, a similar solder bridge for bypassing the relay at *K1* also exists though I couldn't possibly imagine not taking the opportunity to install a relay. Because relays are cool!

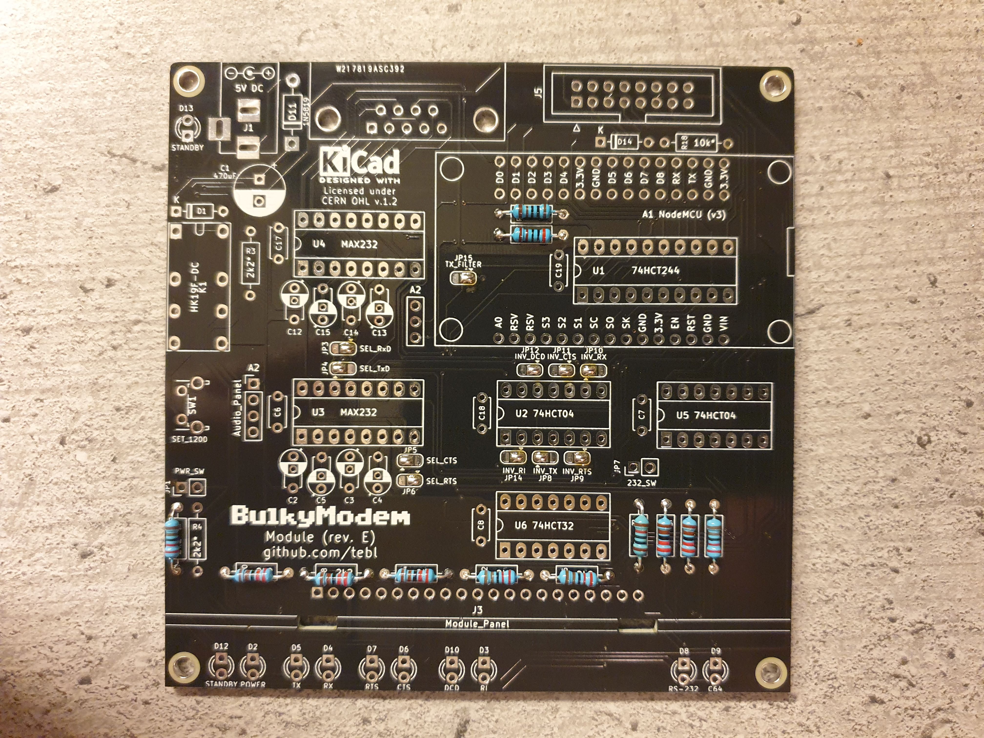
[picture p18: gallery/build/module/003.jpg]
Build 003


Here we've started by soldering all of the resistors, ensuring that we're using the correct values in each position. I also forgot one of them, just mentioning that in case you're confused by the apparent cognitive dissonance. R18 isn't an accident, and should not be installed. Considering that you will need to size the value of the resistor going to each of the LEDs, installed either here or on a front panel - then you'll need to do a bit of [math](https://ledcalculator.net/). This is mostly due to the colour and design of the LEDs, but to keep things manageable - all of them will be marked 2k2 and later revisions of the PCB also includes a description of what they are used for. If it just has a value, then install that value. 

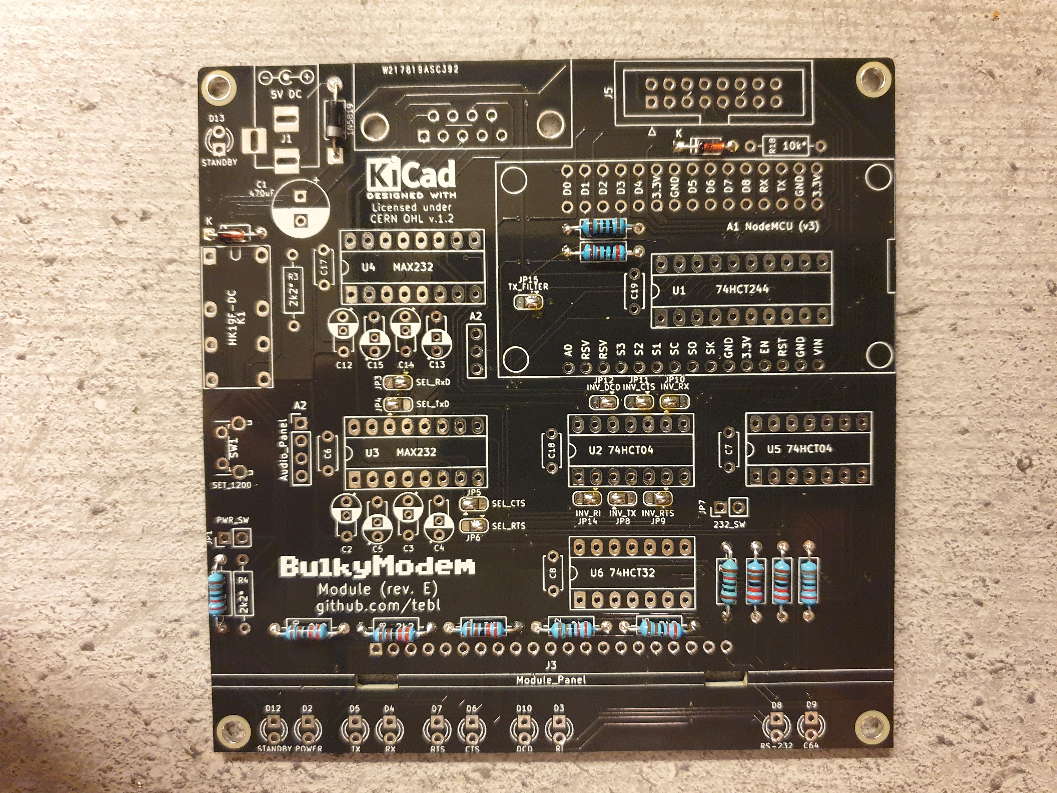
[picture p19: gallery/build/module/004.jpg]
Build 004


Next step is to add a couple of 1N4148 small signal diodes, making sure that the black band of the components matches up with the corresponding markings on your PCB. In the power section there's also a 1N5819 Schottky diode, it looks a bit different though the installation method is the same except that the band on this one is silver or grey. None of it will work if you put those in the wrong way.

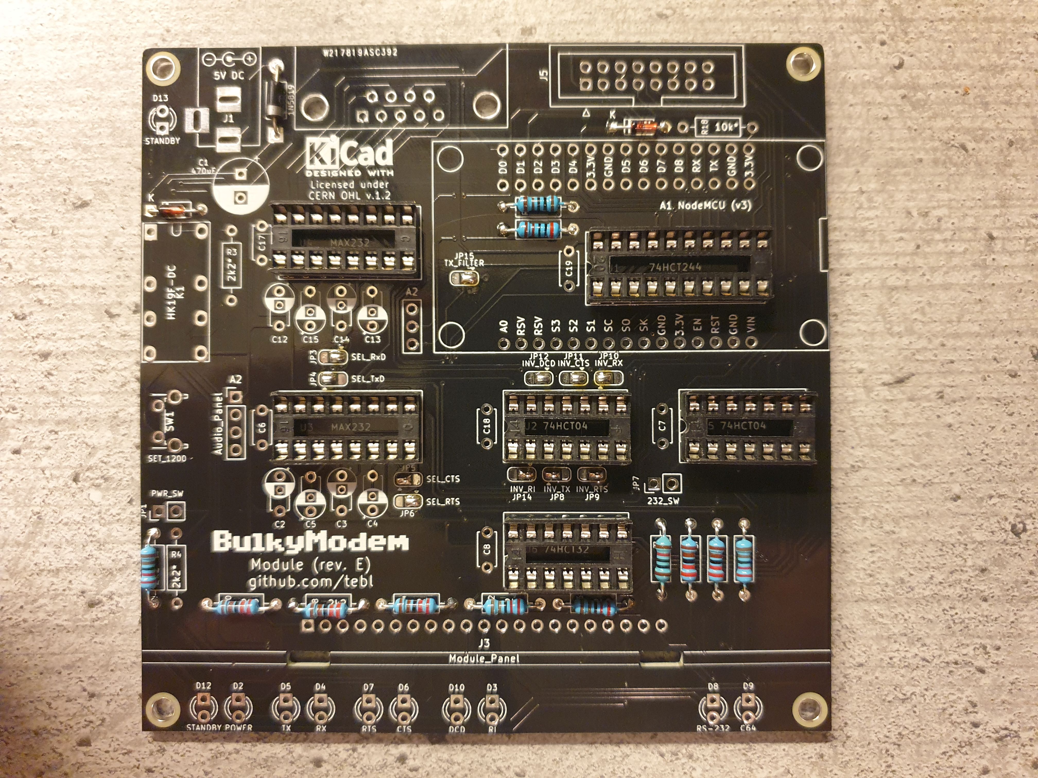
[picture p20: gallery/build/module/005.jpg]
Build 005


Sockets should be installed for the ICs needed for the completed unit. While you could possibly manage without them, they're cheap and you could probably afford to not be quite as *cheap*.  To install I usually solder opposing corners into place, then reheat and push flush against the board before soldering the remaining pins. Note the indent that would indicate *pin 1*, the silkscreen on your PCB should have something similar on that you need to match it up to.

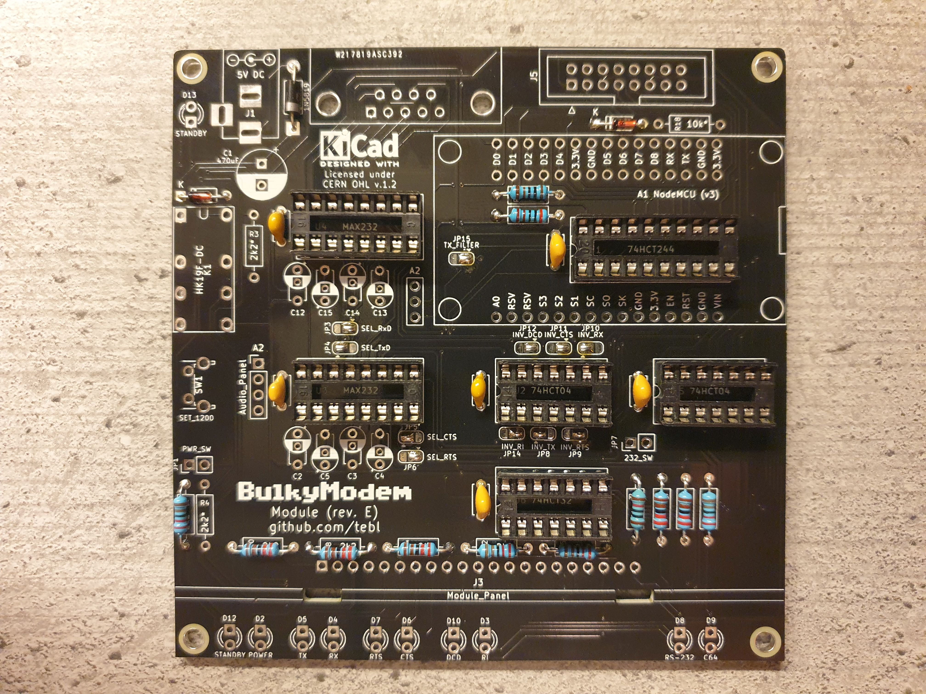
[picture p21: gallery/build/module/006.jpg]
Build 006


We've also gone ahead and installed our non-polarized capacitors, these have a 5mm pin spacing and could be the old type of ceramic disc capacitors. Or the funky yellow monolithic capacitors as shown, mostly because I prefer the way they look - and the blue ones are on the more expensive side of things (not that I know of any relevant difference between them).

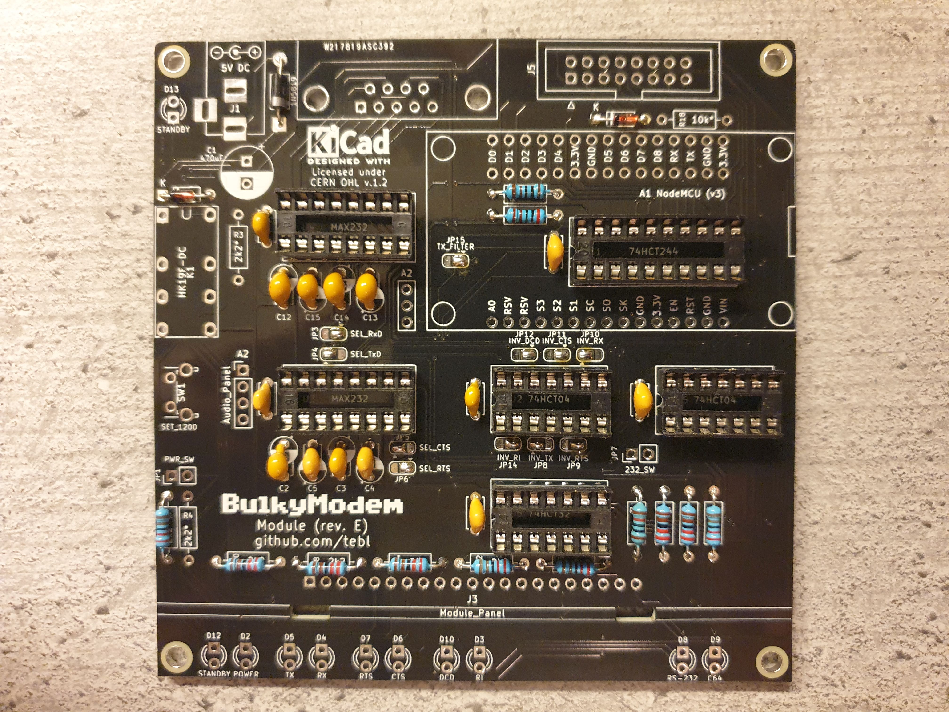
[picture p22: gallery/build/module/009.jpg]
Build 009


The next step *might* involve a whole lot of the same, populating the four spots below both U3 and U4. If the chips that you've bought to populate those sockets, is the recommended MAX232**A** variant of the chips then these are the same components. If on the other hand, you've received the older *MAX232* (no letter behind name) or the cheaper MAX232**C** variants then you will need to install polarized electrolytic capacitors. There are provisions for both options, but the combination **need** to match up with one another. Polarized means that it should only be installed in the correct orientation, the standard is that you need to match up the stripe on the casing with that of the filled-in white area of your PCB.

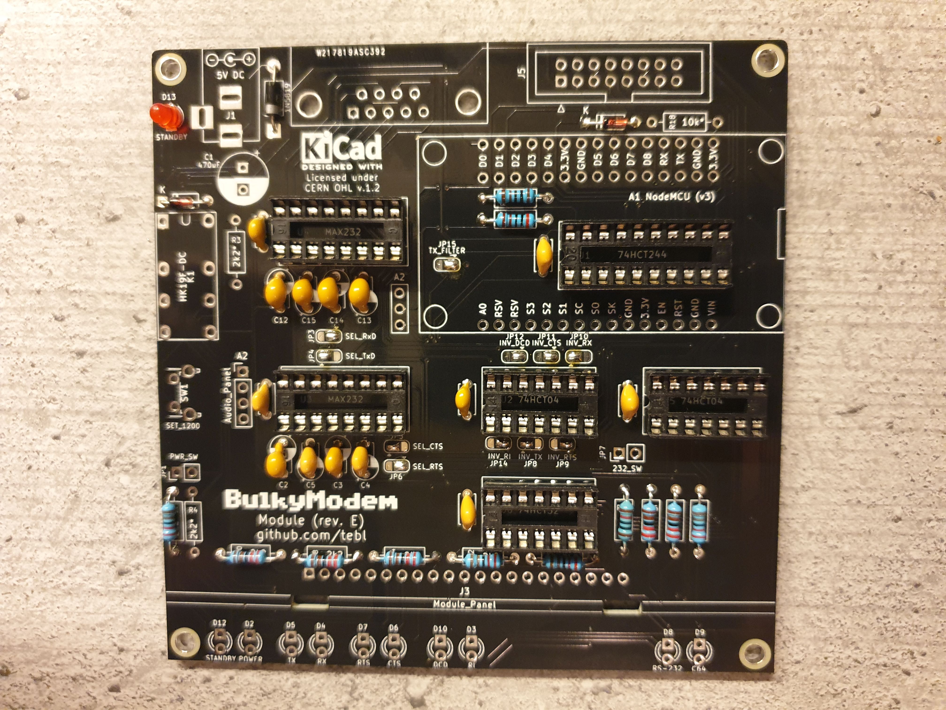
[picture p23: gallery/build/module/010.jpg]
Build 010


At this point I've gone ahead and installed the single LED that I want on the completed unit, as for how it is installed - the longer component lead goes into the round hole and not the square one. If you just had a flashback to some time ago, you either have small kids or an impressive memory! Speaking of memory, I've mentioned earlier that when installing a front panel you don't want to install any LEDs towards the bottom of your PCB.

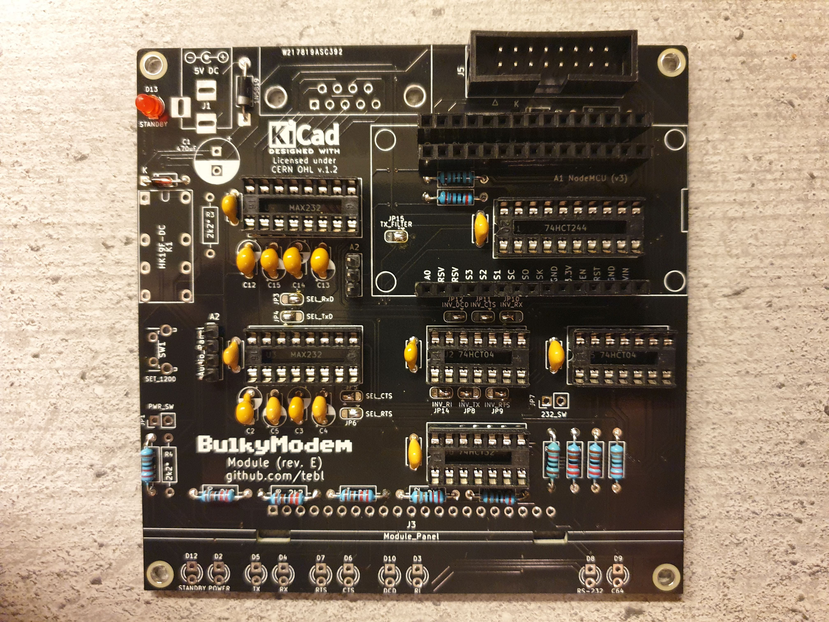
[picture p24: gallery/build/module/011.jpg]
Build 011

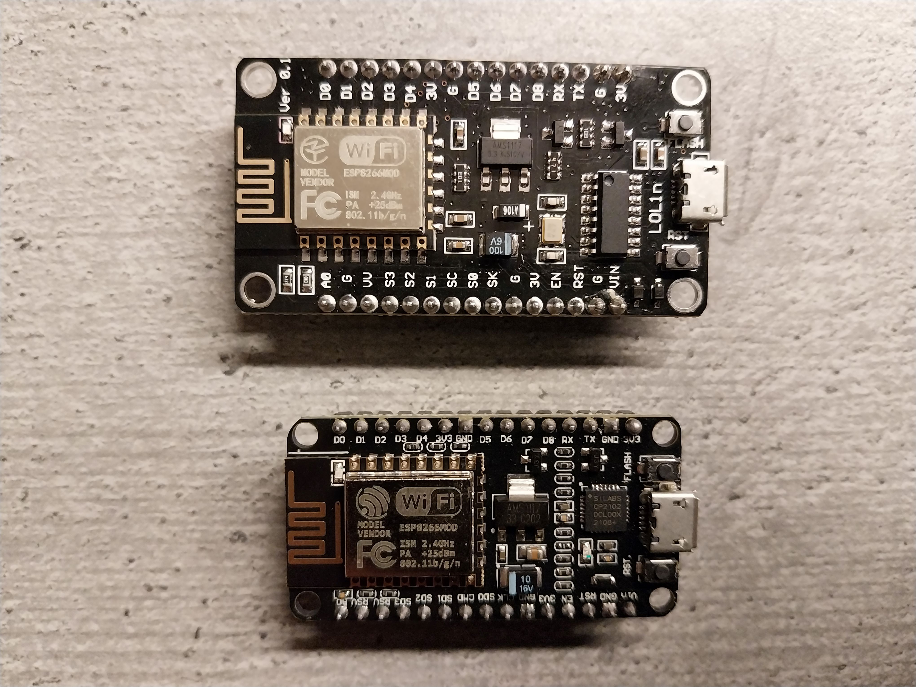
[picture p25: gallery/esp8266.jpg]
NodeMCU-versions


Then we just need to add some pin headers, mainly those in the upper-right quadrant. As for the female pin headers used for the NodeMCU footprint, we're installing three rows of them to account for the physical differences between commonly available versions of it. While they're somewhat unofficially being referenced to as version 2 and 3, one is physically larger than the other. If you can't find 15-pin female header pins, just find some longer ones and cut them down to size with some judicial application of your pliers. Might look a bit rough, but noone will know unless you explicitly tell people that you're *doing* it. The IDC-socket at the top could be replaced by using standard pin-headers, but it it's there to make it harder for someone to insert the cable the wrong way around.

**NB!** If your development boards don't come with male pin-headers already soldered onto them, use a sacrificial extra PCB to hold the pins straight when soldering them into place. A cheap breadboard is also an option that people seem to recommend, but doing it my way ensures that they're always aligned perfectly!

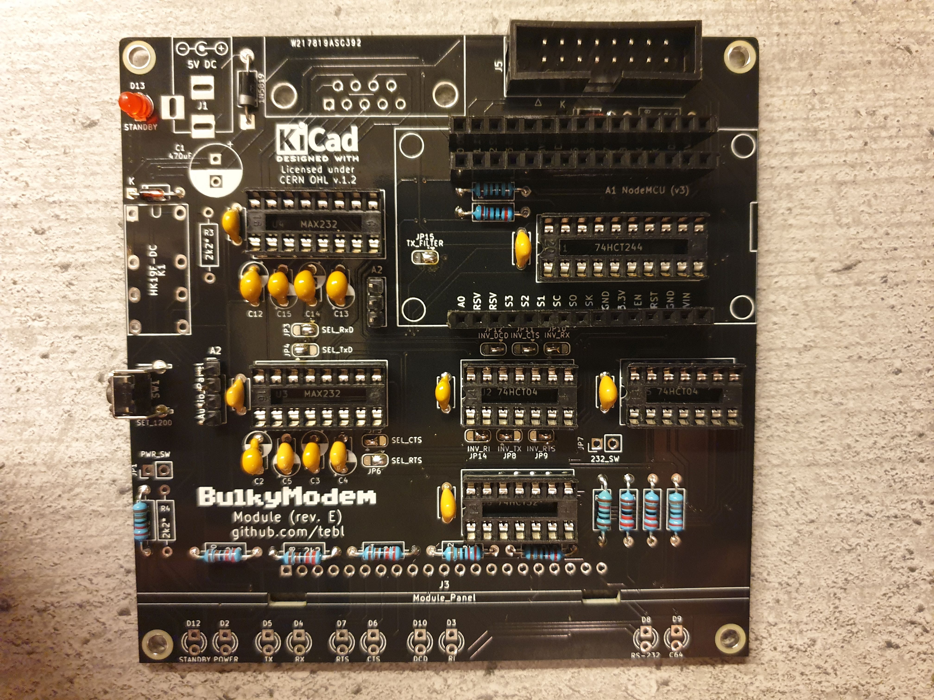
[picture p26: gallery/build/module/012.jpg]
Build 012


The right-angle switch added is mostly just duplicating one of the switches found on your development board, so feel free to skip it until I've found out what I was supposed to use it for. For the most part though, it's just a button that's easier to access once the top cover has been installed.

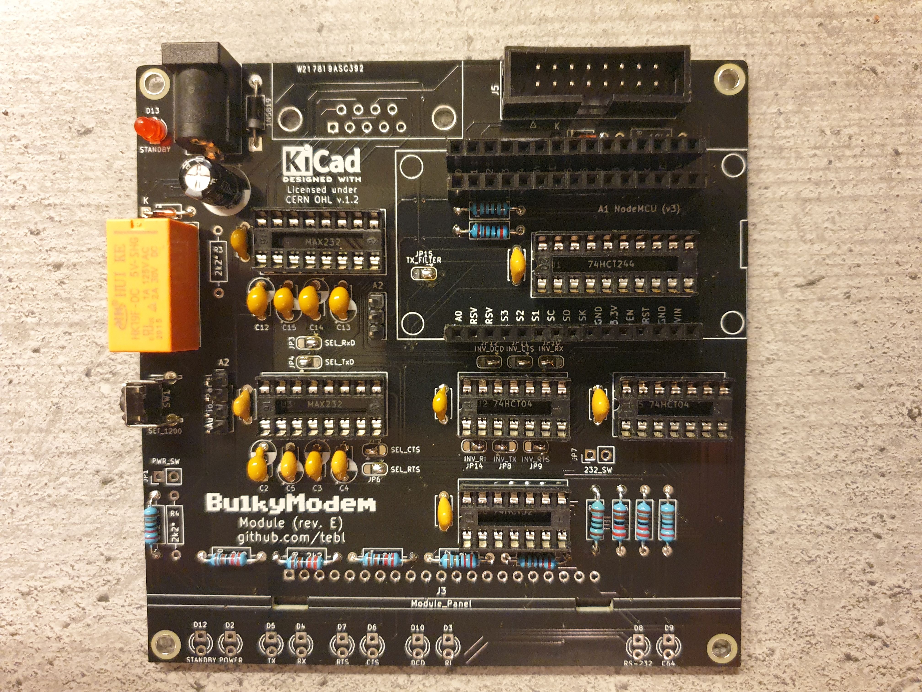
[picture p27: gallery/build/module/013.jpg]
Build 013


Skipping ahead we've started tinkering with the power section again, mostly by adding the common DC barrel connector (5.5mm x 2.1mm). These are quite notorious for going in crooked so make sure to only solder one pin to get started, then reheat and adjust until perfectly satisfied with your results before soldering in the remaining pins. We've already discussed installing a polarized capacitor, but: white stripe, white area, for mostly no boom! The HK19F-relay (5v variant should be used) has roughly the same indentation as found on the ICs, so you should easily identify the correct orientation. These are notorious for being stuffed into a plastic bag, jammed into an envelope, and then finally being stomped upon with a steel-toed boot - so expect to spend just a little bit of time straightening its legs. 

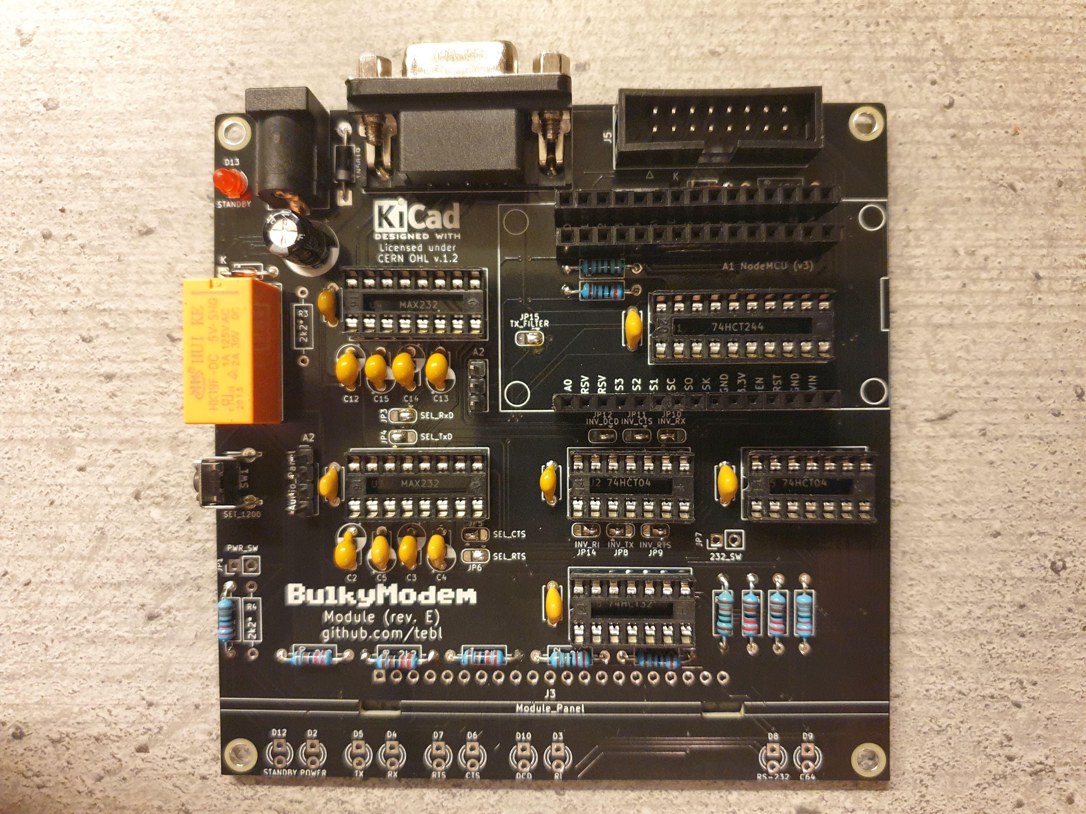
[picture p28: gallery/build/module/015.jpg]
Build 015


The *RS-232* side of things requires what's usually labelled as a female right-angle DB9-connector. Say that three times in front of the bathroom mirror in order to have anyone currently living with you, start questioning your sanity. As for the connector itself, this board was designed to fit the component found on sale from Chinese component vendors (most likely a cloned or rebadged version of the RND-branded connectors). As this is specifically the *DCE*-side of a RS-232 communication setup, then the connector should be the female variety for compatibility with *most* vintage computers.

## 1.2> Putting up a front
While actually constructing a suitable front panel is covered in its own entirely separate set of [documentation](https://github.com/tebl/BulkyModem/tree/main/BulkyModem%20Module%20Panel), we should probably cover the process of actually installing it here. However, before we can do all that we need to introduce one of my most used components over the previous decade. Probably resistors now that I actually think about it, but this is the decade of not letting alternative *facts* get in the way of good old-fashioned lies; the component I'm supposed to say something about, is the nylon "hex" standoffs found in each of the corners as shown below. 

Build 016

For such an innocuous component that should be easy to plop into place, just inserting some nuts on the bottom and be done with it - right? Not so fast there, buddy! You see, I engineered it so that the two at the front needs to be carefully aligned in order to allow the installation of the front panel somewhere beyond this point. It has six sides, and we need to ensure that it is oriented so that it is flush with the left and right outside edges of the PCB. It'll make sense later, I promise!

Build 020

And through the magic of a text-based time-jump we've skipped the [assembly of the front panel](https://github.com/tebl/BulkyModem/tree/main/BulkyModem%20Module%20Panel). What's currently available on our desk at this point in time, should for the most part appear as can be seen above (ignore faceplate differences as those are mainly just styling). As for the trick with the alignment of the "hex" standoffs as described, both here and when assembling the front panel means that the front panel can slide into place without anything getting in our way. If this still don't make sense, look at the picture below in order to observe how the two should - **eventually** - manage to fit together.

Build 021

**NB!** While I've just told you to look at this completed assembly, don't forge ahead by soldering anything into place. Not just yet at least!

Build 022

With the front panel slid into place, the PCBs should slot together quite nicely, and there shouldn't be much of a gap between the two. If you do however find that there's a significant gap, then the likely culprit might be in the production of the PCBs themselves. Not that they're poor, because the fact that we can get a set of PCBs for as low as $2 is simply awe-inspiring - there's simply a limit on how sharp a 90 degree angle can be created when the thing creating the angle is a spinning drill-bit. If this is something you're encountering, then take use a metal file on the corners of the little tabs on the front panel PCB. There are no tracks there so you won't mess anything up, but maybe leave the power tools out of the equation. With that covered, just plop the top cover into place with some temporary standoffs (because they're easy to add and remove by hand). 

Build 023

Flipping the whole thing over onto its back, we can finally start soldering again. If you've had your soldering iron on for the entire time that you've spent reading my meanderings, then I'm sorry... please accept this free repository full of retro goodness as a way to make it up to you for the apparent loss of power efficiency! With all of my recent ramblings about alignment and so on, you might be worried when doing all of this, but that's exactly the reason why we've already taken precautions to ensure that this won't be an issue by temporarily installing the top faceplate.

Build 024

And with that, the last of the soldering have been concluded! Any accidental shorts will only show up once you've turned it off, that's just how *The Matrix* has been coded (that's a joke for anyone old/young enough to remember the 90s).

## 1.3> Integrating circuitry
As for adding integrated circuits, mainly just chips of the non-starchy kind, its just a matter of matching up the indentation with that of the sockets that we've hopefully installed sometime earlier. Probably yesterday, but that's just guesswork. A pin straightener will make things easier though a pair of pliers will help you achieve the same thing, just without the same level of visual flair.

Build 025

And that's all of them installed in their current place. While the chips should be easy to get hold of, the plague of our current no-consequence shopping experience is that a lot of it will be reclaimed or counterfeit chips that will have had a new label printed onto the top of it. Giving inadequately paid people the benefit of doubt, is that the parts will have been roughly sorted into seemingly identical buckets before applying said label. Sometimes that means that completely incompatible technologies have been labelled identically, and we're left to guess why a circuit doesn't work as advertised. If you received a bag of 10, then half of those are more than likely trash. The rest are still a good deal, you just need to swap between them until you find a combination that works (nothing that's considered working should get more than luke-warm to the touch).

Build 026

As for the brains of the operation, who knows what kind of software have previously been written to it? Probably what we insufferable Arduino-addicts refer to as a "blink"-sketch, but you never know until you actually plug it in. So before you plug it in, make sure to get the applicable [Zimodem](https://github.com/bozimmerman/Zimodem)-firmware onto it before actually plugging it in like shown above. As doing that is a whole other adventure by itself, I've put together my own guide on how anyone with a very particular set of interests can go about actually [setting it up](https://github.com/tebl/BulkyModem/blob/main/documentation/setting_it_up.md). Do that. Then plug it in. Just *don't* do it with any kind of accidental pin-offsets.

## 1.4> Keeping up with the Commodore
Keeping up with the Commodore 64, albeit dragging it kicking and screaming into requirements of the current century requires a suitable adapter. Specifically the one included with this project, helpfully documented with its own entirely different set of [documentation](https://github.com/tebl/BulkyModem/tree/main/BulkyModem%20UserPort%20Adapter) describing its assembly process. It connects to the main body of the *BulkyModem* using commonly available cables, usually labelled as a *16-pin IDC cable* - quite possibly with the word *JTAG* there as well (for some reason). This is what it looks like when in use:

User Port Adapter

Why is this needed? As the modem is an independently powered device from that of the Commodore 64, we effectively have what can electrically be considered as separate power domains with a cable connecting the two. Except... any connected signal is also a source of power. Leading to somewhat scary issues, such as when a data signal from your C64s crusty old CIA-chip starts attempting to power up the modem - or vice versa. The classic solution to this problem is to only enable communications when both sides can be considered suitably alive, so that's what we're doing here in what's probably a very 1970s way.

## 1.5> Finishing touches
BulkyModem

As for finishing touches, it's can be summed up as taking steps towards attaching the top faceplate. Again. But this time you're using *proper* screws. As for where you should go from here, the exciting world of the BBSes is probably one of them. For something more specific, see:

- [Setting it up](https://github.com/tebl/BulkyModem/blob/main/documentation/setting_it_up.md)
- [Getting started](https://github.com/tebl/BulkyModem/blob/main/documentation/getting_started.md)

# 2> Schematic
The supplied KiCad files should be sufficient as both a schematic and as a  starting point for ordering PCBs. Most if not all fabrication companies will expect Gerber-files, these are generated from KiCAD though you will be able to bypass this step by using PCBway shared projects. As for the schematic, one has been provided for you in [PDF-format](https://github.com/tebl/BulkyModem/tree/main/documentation/schematic) - an important source of information when things inevitably fail to work as advertised.

# 3> BOM
Most parts should be easy to get a hold of from your favourite local electronic component shop, but given that I don't have access to such shops where I live so everything used is whatever I could get cheapest from eBay/AliExpress ( sometimes free shipping, but plan on waiting 3-4 weeks for delivery). While there are options for building a slightly cheaper version of the *BulkyModem* by forgoing some parts as you see fit based on analyzing the relevant circuit, I'm mostly going to assume that you're looking at this page in order to build the complete version of the *BulkyModem* - because that's the point of it in the first place. Components listed in parenthesis can be considered duplicates of those found on the front panel, but when in doubt I've added descriptions where relevant.

**NB!** Note, however, that the following table only includes components required for assembling the main PCB by itself. Those required by the [front panel](https://github.com/tebl/BulkyModem/blob/main/BulkyModem%20Module%20Panel/README.md#3-bom) and [Commodore 64 User Port Adapter](https://github.com/tebl/BulkyModem/blob/main/BulkyModem%20UserPort%20Adapter/README.md#3-bom) are not included in this list, so make sure to browse around.  

| Reference | Item | Count | Order  |
| --- | --- | ----- | --- |
| Faceplate PCB | Fabricate using Gerber files | 1 | [PCBWay](https://www.pcbway.com/project/shareproject/BulkyModem_e6d2ed59.html)
| A1 | ESP8266 development board | 1 |
| C1 | 470uF electrolytic capacitor (3.5mm pin spacing) | 1 |
| C2-C5,C12-C15 *1 | 100nF capacitor (5mm pin spacing, or 1uF electrolytic (2mm pin spacing) | 8 |
| C6-C8,C17-C19	 | 100nF capacitor (5mm pin spacing) | 6 |
| D1,D14 | 1N4148N small signal diode (DO-35) | 2 |
| D3-D10 *2 | 3mm LED | (8)|
| D11			 | 1N5819 Schottky diode (DO-41) | 1 |
| J1 | 2.1mm x 5.5mm barrel plug | 1 |
| J2 | Right-angle female DB9 connector (PCB mount) | 1 |
| J5 | 2x8 pin, 2.54mm IDC male box header connector | 1 |
| JP1,JP7 *3 | 1x2 straight pin header, with jumper cap | (2)|
| K1 | HK19F-DC 5V-relay | 1 |
| R1-R4,R8,R10-R12,R14-R16,R25 *4  | 2k2 (2200) ohm resistor | 11 |
| R17 | 2k ohm resistor | 1 |
| R19 | 1k ohm resistor | 1 |
| R21 | 10k ohm resistor | 1 |
| SW1 | 6x6x5mm right-angle momentary button | (1)|
| U1 | 74HCT244 (DIP-20) | 1 |
| U2,U5 | 74HCT04 (DIP-14) | 2 |
| U3 | MAX232 (DIP-16), preferably MAX232A | 1 |
| U4 *5 | MAX232 (DIP-16), preferably MAX232A | (1)|
| U6 | 74HCT32 (DIP-14) | 1 |
| Mounting *6 | Nylon M3 hex standoffs 20mm (M-F) | 4 |
| Mounting *6 | Nylon M3x6mm nylon screws | 4 |
| Mounting *6 | Nylon M3x6mm nylon nuts | 4 |

1) You need to install 1uF electrolytic capacitors in these positions if you're using one of the cheaper MAX232-variants, most likely marked MAX232**C** or without any letters at all. If you have one that's marked MAX232**A**, then you need to install 100nF capacitors here instead. If there are more letters listed in the name, just look at the first one and ignore the rest.
2) These are indicator LEDs, you can skip the installation of these if either don't want them - or - you're building the BulkyModem with a front panel. Also see *4 for correct sizing of associated resistors.
3) These are mostly only needed when you're not installing a front panel, if you were planning on installing the board into some other case then this is also a reasonable place to connect latching switches.
4) Indicator LEDs, regardless of whether you're installed them here or on the front panel, you'll need a suitably sized resistor in order to avoid blinding yourself and/or causing the LED itself to quickly burn out. Different types, in particular the colour it produces greatly affects the value required. If you're somehow feeling lucky by this point, go for a 1k for a dyed LED (you can tell the colour by looking at it in the bag) or the 2k2 suggested for anything else. Then swap out until you feel happy with your life choices.
5) The second MAX232-chip at U4 can be skipped if you do not need the signals provided by it - DCD (Data Carrier Detect) and RI (Ring Indicator). This is simply a cost-cutting measure as the chips themselves are now considered obsolete, doing so will require that you link the *BYPASS* pads on the back of the PCB.
6) These are available in the form of kits usually advertised *M3 nylon standoff kit* which should contain most of what you'd need. I do however recommend that you pick up extra M-F standoffs of lengths 10mm and 20mm, as quite a lot of them will be used when building more than one module. Add some screws and nuts while you're at it.

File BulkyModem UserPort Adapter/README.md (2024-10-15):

# BulkyModem C64/128 UserPort Adapter
This is an adapter for connecting up the *BulkyModem*, alternatively the functionally similar *BulkyModem-32*, up to everyone's favorite 8-bit system that's not the NES. Commodore 64! The answer is Commodore 64! Got that? Yes, it's also compatible with the Commodore 128 if that's what you were thinking about. It currently looks like this:

BulkyModem Adapter

You plug the adapter into the *User Port* on your computer, then it hooks up to your *BulkyModem* using commonly available *2x8 pin IDC cable* that's regularly sold on the regular sites. As for why you need an adapter, it started out as a straight up adapter with no active components on it though I soon discovered that you generally don't want independently powered devices connected in this way. It'll work like it should, but the second you power off either of the devices, then the other will start backfeeding power to it through the data lines. Ouch! So I did the a 70s fix by adding line buffers, and then only enabling them once both sides have been properly powered up.

**NB!** Note, however, that with a Commodore 128 you will not be able to utilize UP9600-wiring for speeds above 1200 baud. That's a limitation of the machine in combination with this specific communication method, and not the adapter itself. See [Getting started](https://github.com/tebl/BulkyModem/blob/main/documentation/getting_started_c64.md#21-up9600) guide for the Commodore 64/128, in particular, for more information. 

- [1> Building the adapter](#1-building-the-adapter)
  - [1.1> Soldering it together](#11-soldering-it-together)
  - [1.2> Testing it out](#12-testing-it-out)
- [2> Schematic](#2-schematic)
- [3> BOM](#3-bom)

# 1> Building the adapter
Building an adapter such as this assumes you have at least minor experience soldering things together, but it is recommended that you at the very least have access to a soldering station with adjustable temperature. If it's legally available where you live, consider using 60/40 rosin core solder as the lead-free alternatives tends to be a bit harder to work with.

Now that you've arrived at *concepts of a plan* for what you want to build, we can get started on one of the more expensive steps in any build process - shopping! For reference, the most expensive step is probably setting your desk and/or house on fire so don't drink and solder. Anyway, when ready to continue with the whole shopping thing that you've heard so much about - head on over to the [BOM](#3-bom)-section. There you'll find *mostly* accurate information on the kind of components that you'll need.

While I would have liked to give you specific part numbers for "reputable" electronic part suppliers, I can't afford to shop there personally. So what I do, is to make due with what I can find on sites such as eBay, AliExpress or any other future site that will inevitably seem to sell the same, and quite possibly identical set of cheap Chinese components. It keeps cost to a minimum, but the downside is that I can't link to a part directly and expect it to stay listed tomorrow. For that reason you'll need to consider their descriptions as mere *suggested search terms* and not *part numbers* in any accurate sense of the definition.

## 1.1> Soldering it together
Soldering the device together should be a fairly straight-forward affair, just take your time and work your way through the described process before actually attempting to do so. There are some important components that absolutely need to be installed in their correct orientation, and from experience I can tell you that it is significantly easier to do it right in the first place, than it is to try and desolder something before trying again.

Build 002

I usually recommend starting the process by having a good look at the PCBs, try to figure out where all of the listed components should go and in which orientation they go in. I will usually try to install components in the order of their physical size, meaning that you'll have an easier time in order to keep everything from looking somewhat *wonky*. Anyway, this is ultimately your board, your build and you want it perfect, don't you? If you said no, then go sit in the corner because I worked hard on creating this. Mainly for myself, but it's also here for whoever wants to build one later.

Build 003

First step though, is to install resistors. While most of them should be installed with the values as specified, the ones marked 2k2 (2200) Ohm may need some adjustment based on the type of LEDs that you'll be installing later. If you have a modern clear LED you'll want a higher value, if you have the cheaper dyed ones then you want something lower. There are [online calculators](https://ledcalculator.net/#p=3&v=1.8&c=20&n=1&o=w) that will tell you what you need, or you can *roll that dice* and hope for a comfortable result.

Build 004

The next step is diodes, and there are a couple of types that have been installed at this point. The first type to deal with is the two *1N5819 Schottky* diodes at the far right, these have a black body and a silver stripe that needs to be matched up in the orientation as indicated by the white band on the illustration (these "point" towards each other).

The others are *1N4731A Zener* (alternatively *1N4730A*) diodes, these work a bit different from how we mortal Arduino-tinkerers think of diodes - they were defined to "break" down beyond a certain voltage. Not *"break down"* as in broken, it means that they will start conducting in the other direction above it. This effect is used by the circuit so that we can reliably detect the presence of power from the *BulkyModem* as well as ensuring that the Commodore 64/128 is sufficiently powered on. Is that a good way of doing things? I don't know, it's my first time trying to use the component in a circuit.

Build 005

Sockets should be installed for the single IC needed to build the adapter. While you could possibly manage without using a socket, they're cheap and you could probably afford not to be quite as cheap. To install I usually solder opposing corners into place, then reheat and push flush against the board before soldering the remaining pins. Note the indent that would indicate pin 1, the silkscreen on your PCB should have something similar on it that you will need to match it up to.

Build 006

As for my next component of choice, I went with the 100nF capacitor next to the IC. While I did add some provision for an electrolytic at *C2*, in the end I chose not to install it. As for the LEDs that we've in part discussed at some point in the past, mostly in relation to the resistors limiting their brightness. As for their installation, one of their legs will be longer than the other - and that's the one to put into the round pad. I know that the function of each leg implies a more exact name for them, I'm not going to put something I can't even remember myself. Cathode? Anode? One of those two. Just pick the longer one.

Build 007
Build 008

Two transistors are needed, both are *2N3904 NPN transistors*. The kind I'm using has straight legs. but my PCB takes the wider kind with bent legs because those are easier to install. I could try and buy those from somewhere that sells them, or I could keep buying the significantly cheaper ones and just bend the outer legs slightly outwards before showing them into place. They tend to rotate slightly, but should work nonetheless. What you do, however, need to make sure is that they go in the right way. For that you need to observe that it has a flat side with the label printed on it, that needs to be matched with the flat side on the PCB. Put them in the wrong around for a tiny one-time-use smoke machine that will never do any of the things that you want them to.

Build 009

I've gone ahead and added the straight pin headers for the *UP9600-enable* jumpers. Use some blu-tac to avoid burning your fingers, but if you don't have some around you *could* try to hold onto the pin you're not soldering and get that in straight. The latter method is mostly guaranteed to burn your fingers, but at least you were "sufficiently" warned. The IDC-socket at the top could be substituted by standard pin headers if you need to, but I like using them in order to avoid accidentally plugging in the cable the wrong way around.

Build 010

The next one is a standard 805 card edge-connector, they come in a couple of variants - one that has a thin pin intended for inserting into a PCB, the other has wider pins suitable for soldering onto wires. Both will work though I prefer the latter as the pins seem somewhat stronger. What we need to do in order to install it, however, is to not start soldering things right away - instead we need to break out that secret stash of M3 screws and nuts that you've been hiding. Preferably I'd tell you to use those made out of nylon as you can easily cut a screw down to size, at least without digging out a hacksaw and quite possibly look in the garage for a table vice.

Anyway, what we need to do is to cut two screws down to size so that they fit through the blue connector  without bottoming out in the cutouts found on your PCB. Said cutout should fit the flat edge of a nylon M3-nut, so just put one in there and start screwing things up. Somewhat tightly as it is nylon after all, try again if that's what you've just done.

With the screws mostly holding the connector into place, the pins themselves will float somewhat above the PCB-surface on both sides. What I like to do at this point, is to take a small flat-edged screwdriver and press it down on the middle of the pin so that it bends down and the end of it *mostly* touches the solder pads. I say "mostly" because it's never perfectly flat, it's just the best I can manage. Solder one of the pins, check against the alignment of the same on the other side of the PCB to see if you need to adjust things slightly. When happy with your choice of hobbies, do the opposing edge in the same manner before soldering all the remaining pins on both sides.

Build 011

The final step is just to insert the single IC, it has an indent on it shat should match the one found on the socket we've already installed at a previous point in this guide. As for the jumpers I've just put them on there so that I don't loose them, in this position they are only sitting on a single pin.

## 1.2> Testing it out
The jumpers mentioned earlier are for using *UP9600*-mode on a Commodore 64 with software that explicitly supports it, some even require that you configure this mode without it connected at the time. As for on a Commodore 128 this mode is not supported at all, so should either remove them entirely or leave them in the horizontal position as shown earlier.  For more information about UP9600, see [Getting started](https://github.com/tebl/BulkyModem/blob/main/documentation/getting_started_c64.md#21-up9600) guide for the Commodore 64/128.

As for testing out the adapter, I advise that you first test it with only the *BulkyModem*, alternatively *BulkyModem-32*, connected to it. If something is going to blow up, better that it do so when not connected to vintage and quite possibly precious hardware. The LED marked *PWR* should light up, but without the Commodore 64 present and powered up - the *EN* LED should not turn on.

Build 015

Plugging it into a Commodore 64/128 may take some considerable force, the connector is brand new and may have been 40 years since you last encountered a new one. With the cable and everything in place you should not be able to comfortably insert it upside down, but in case you need me to paint you a picture - there's one above. If you find it hard to remove again later, don't pull on the components themselves. Instead you should either grab the sides firmly, or put a loop of cable into the holes on it - and pull on that.

**NB!** Never plug or unplug anything with power running to it, even if it is just on the other side of the cable. Vintage hardware may have survived things quite a lot of things 40 years ago, but they were new back then - now they're not.

# 2> Schematic
The supplied KiCad files should be sufficient as both a schematic and as a  starting point for ordering PCBs. Most if not all fabrication companies will expect Gerber-files, these are generated from KiCAD though you will be able to bypass this step by using PCBway shared projects. As for the schematic, one has been provided for you in [PDF-format](https://github.com/tebl/BulkyModem/tree/main/documentation/schematic) - an important source of information when things inevitably fail to work as advertised.

# 3> BOM
Most parts should be easy to get a hold of from your favorite local electronic component shop, but given that I don't have access to such shops where I live so everything was based on whatever I could get cheapest from eBay/AliExpress (free shipping, but plan on waiting 3-4 weeks for delivery).

| Reference | Item | Count | Order  |
| --- | --- | ----- | --- |
| Panel PCB | Fabricate using Gerber files | 1 | [PCBWay](https://www.pcbway.com/project/shareproject/BulkyModem_Commodore_64_128_UserPort_Adapter_a84c7ef6.html)
| C1 | 100nF capacitor (5mm pin spacing, or 1uF electrolytic (2mm pin spacing) | 1 |
| C2 | Not needed. | 0 |
| D1,D4 | 1N4731A Zener diode (DO-41) | 2 |
| D2,D3 *1 | 3mm LED | 1 |
| D5,D6			 | 1N5819 Schottky diode (DO-41) | 2 |
| J1 | 2x12 pin, 3.96mm 805 series card edge connector | 1 |
| J3 | 2x8 pin, 2.54mm IDC male box header connector | 1 |
| JP1,JP2 | 1x2 pin, 2.54mm straight pin header (with jumper cap) | 2 |
| Q1,Q2 | 2N3904 NPN transistor (TO-92) | 2 |
| R1,R4,R6 | 10k ohm resistor | 3 |
| R2,R5 | 1k ohm resistor | 2 |
| R3,R7 *1 | 2k2 (2200) ohm resistor | 2 |
| U1 | 74HCT244 (DIP-20) | 1 |
| Mounting *2 | M3x15mm nylon screws (or longer, cut to size) | 2 |
| Mounting *2 | M3 nylon nuts | 2 |

1) I highly recommend using frosted LEDs, but if you can only find clear ones then you could always frost them a bit yourself using sandpaper or some sort of polishing tool. Do note that some resistors need to be adjusted based on type of LED used. For a modern LED the suggested value may work, but you may need to adjust for the colour. For anything ancient, or extremely cheap, you may need a lower value. 
2) These are often sold in kits, but you usually also find bags of each on the usual sites. Nylon is strong enough for my purposes while easy enough to cut down to a suitable size.

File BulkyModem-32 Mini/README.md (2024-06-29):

# BulkyModem-32 (Mini RS-232)
While doing the full ESP8266-based version of BulkyModem, I did get to wondering about what I was missing out on by not using an ESP32. I tried reading the documentation, and then the source code - and in the end I just built this in order to see what it does. Somehow that seemed like the easier solution.

Mini RS-232 in use

- [1> Building the device](#1-building-the-device)
  - [1.1> SD-card](#11-sd-card)
- [2> Schematic](#2-schematic)
- [3> BOM](#3-bom)

# 1> Building the device
Building the device should be a straight-forward affair, you just solder the meager selection of components into place. Pay attention to keep the alignment of the parts somewhat straight, then you should be good. This documentation was written with a board that looks like the following in mind, but note that the github-repository may contain changes that have yet to be tested (therefore, it is recommend that PCBs are ordered using PCBWay links listed in the BOM).

Bare boards

Components should be installed in the order of their physical height, but beyond the choice of a specific variant of the MAX232-chip used there's not all that much that can go wrong beyond making things harder for yourself to put it together. While cheaper variants such as the old *MAX232* (no letter) and the MAX232**C** requires electrolytic capacitors (polarized), I recommend using a MAX232**A** as that simply uses ceramic 100nF capacitors instead. There are provisions for both options, but the combination need to match up with another. There are also two diodes, these have a stripe that needs to be matched correctly to the markings.

ESP32 development board

Most components will be hidden under the 30-pin variants of the ESP32 that we'll be using, the ones I'm using in the pictures was listed on marketing sites as *ESP32 development board / ESP32-WROOM-32D*. The module itself needs to be lifted above the rest of the components by using female pin headers, then we can insert the module on top of that. I recommend soldering a pin on each side, then check if the alignment is suitable to actually get the module in there before soldering the rest.

The LEDs can be any colour of your choice as long as you adjust the resistors used with them, for that reason each footprint will have a text describing what they are connected to. The suggested value is just a starting point for a modern bright LED, but for the older type with a coloured plastic body - you need to pick something else. Usually a value from 330 ohm up to 1k ohm may be more suitable. Check out [LED Series Resistor Calculator](https://www.digikey.com/en/resources/conversion-calculators/conversion-calculator-led-series-resistor) if you need to find the "correct" value, fill in 5v and something like 10mA as a starting point - forward voltage will normally be dictated by the LED colour used.

Completed unit

I recommend installing the sketch onto the ESP-32 while it is disconnected from the rest of the unit, but beyond that I'm not going to go into programming it here - for that information, see the [setting it up](https://github.com/tebl/BulkyModem/blob/main/documentation/setting_it_up_mini_rs232.md) guide.

## 1.1> SD-card
The ESP32-based devices such as the *BulkyModem-32 (Mini RS-232)* include some additional features not found on those based on the ESP8266, among them is the ability to use SD-cards with the modem. While I won't even attempt to pretend to understand what everything found within Zimodem should be used for, an SD-card seems to be an attractive expansion that can be added onto it via the header at the bottom (marked *J1*). The pin order was matched to a widely available module for use with *ESP32*, two of them are shown in the picture below.

SD-module
Installed module

Given that I wanted the *BulkyModem-32 (Mini RS-232)* to be somewhat "mini", at least compared to the full device, there probably isn't an ideal way of installing it. You can have it installed using wires, soldered directly above or even below the main board - you just need to ensure that the pads with the square is matched up with another. Installing it above the board requires that the ICs are installed without sockets, the module will then be pointed towards the inside of the device and we'll need to unplug the ESP32 to replace the memory card. Other options means having it pointing to the outside, or stuck to the underside with something in between to avoid shorting. Essentially, pick something you're comfortable living with.

With an SD-card installed you'll have access to another set up tools, including the ability to have the ESP32 retrieve files over http or ftp (unfortunately, no SSL support) and store them to the card. Files can be transferred between the modem and your vintage system using the XMODEM-protocol. The following commands should be all you need to get started using it:
```
at+shell
OK
/> help
```

# 2> Schematic
The supplied KiCad files should be sufficient as both a schematic and as a  starting point for ordering PCBs (basically you could just zip the contents of the export folder and upload that on a fabrication site), the schematic is also available in [PDF-format](https://github.com/tebl/BulkyModem/tree/main/documentation/schematic) and this is what you'll need to print and work your way through when things fail to work as expected.

# 3> BOM
Most parts should be easy to get a hold of from your favourite local electronic component shop, but given that I don't have access to such shops where I live so everything was based on whatever I could get cheapest from eBay/AliExpress (free shipping, but plan on waiting 3-4 weeks for delivery). As I expect that most will build this adapter solely for MIDI-output, the values required for the MIDI input have been listed in parenthesis.

| Reference | Item | Count | Order  |
| ---| --- | ----- | --- |
| Faceplate PCB  | Fabricate using Gerber files | 1 | [PCBWay](https://www.pcbway.com/project/shareproject/BulkyModem_32_Mini_RS_232_e6ccfb60.html)
| A1 | ESP32-WROOM-32D development board, 30-pin | 1 |
| | 15-pin female pin header | 2 |
| C1,C8 | 100nF (104) ceramic capacitor (5mm) | 2 |
| C2-C5 *1 | 1uF electrolytic capacitor (2mm pin spacing), or 100nF ceramic | 4 |
| D1-D5 | 3mm LED | 5 |
| D14,D15 | 1N4148N small signal diode (DO-35) | 2 |
| J1 *2 | Micro Mini SD Storage Expansion Board Mini | (1)|
| J2 | Female DB9, panel mount connector | 1 |
| R1-R4,R6 *3 | 2k2 ohm resistor | 5 |
| R5,R18 | 10k ohm resistor | 2 |
| U3 *1 | MAX232 (DIP-16), preferably MAX232A | 1 |
| U6 | 74HCT32 (DIP-14) | 1 |

1) You need to install 1uF electrolytic capacitors here if you're using one of the cheaper MAX232-variants, usually marked MAX232**C** or without any letters at all. If you have one that's marked MAX232**A**, then you should install 100nF capacitors here instead - this is also the recommended configuration. If there are more letters than those on the chip, just look at the first one.
2) This is more or less the magical search string that got what I wanted on AliExpress, check the section on [building](#11-sd-card) it for pictures of what it actually looks like. Anything else and you would probably need to figure out how to wire it correctly, see [schematic](#2-schematic) for pin names.
3) The correct values to install here depends on the specific LED you're installing on D1-D5, the suggested value is intended for the more modern kind of bright LEDs. If the plastic already has a colour you need something lower, possibly 330 to 1k depending on the colour.

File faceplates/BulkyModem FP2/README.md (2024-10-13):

# BulkyModem FP2
This is a faceplate, an inherently optional part of any build as it does not actually contain any active components. This faceplate mounts on the **front** of the device, and compared to the other options available, it is the longer version [^1]. It is compatible with the following main projects:
- [BulkyModem](https://github.com/tebl/BulkyModem/tree/main/BulkyModem%20Module)
- [BulkyModem-32](https://github.com/tebl/BulkyModem/tree/main/BulkyModem-32%20Module)

It currently looks like this:
Preview

[^1]: This means that it extends below the main PCB when installed, any faceplates installed on the **bottom** of device will be covered up by it. [Faceplate FP1](https://github.com/tebl/BulkyModem/tree/main/faceplates/BulkyModem%20FP1) is the shorter version of it.

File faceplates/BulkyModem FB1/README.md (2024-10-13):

# BulkyModem FB1
This is a faceplate, an inherently optional part of any build as it does not actually contain any active components. While it is my goal to keep these in a fairly universal format for the *BulkyModem* in general, getting everything redesigned to fit the same physical layout may not happen unless I find a fault that warrants a revisit. As for this specific design, it can **also** be used as the bottom part of the device, meaning two pieces are used when building the complete device. The following list includes a list of compatible projects, with compatible front faceplates listed directly below it:
- [BulkyModem-32](https://github.com/tebl/BulkyModem/tree/main/BulkyModem-32%20Module)
  - [BulkyModem FP2](https://github.com/tebl/BulkyModem/tree/main/faceplates/BulkyModem%20FP2)
  - [BulkyModem FP3](https://github.com/tebl/BulkyModem/tree/main/faceplates/BulkyModem%20FP3)
- [BulkyModem Terminal](https://github.com/tebl/BulkyModem/tree/main/BulkyModem%20Terminal) [^1]
  - [BulkyModem Terminal FP3](https://github.com/tebl/BulkyModem/tree/main/faceplates/BulkyModem%20Terminal%20FP3)

It currently looks like this:
Preview
Preview

[^1]: There are some markings on the underside of the PCB, but I suggest that you either put a sticker over it or erease it using a suitable marker (reverse the PCB when installing). If this is not to your liking, there's also [BulkyModem Terminal FA1](https://github.com/tebl/BulkyModem/tree/main/faceplates/BulkyModem%20Terminal%20FA1) that have been specifically designed for the terminal.

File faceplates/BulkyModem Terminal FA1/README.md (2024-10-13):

# BulkyModem Terminal FA1
This is a faceplate, an inherently optional part of any build as it does not actually contain any active components. This faceplate mounts on the **top** or **bottom** of the device, and it is compatible with the following main projects:
- [BulkyModem Terminal](https://github.com/tebl/BulkyModem/tree/main/BulkyModem%20Terminal)

It currently looks like this:
Preview
Preview


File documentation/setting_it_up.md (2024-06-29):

# 1> Setting it up
The [documentation](https://github.com/tebl/BulkyModem/tree/main/BulkyModem%20Module) that comes with the main module mostly only deals with soldering the device together, the purpose of this document is instead focused on everything related to the firmware we want running on the ESP8266.

ESP8266

While many of the options out there for purchase has been based on the article [Build your own 9600 Baud C64 WiFi Modem For $10](https://1200baud.wordpress.com/2017/03/04/build-your-own-9600-baud-c64-wifi-modem-for-20/), leading you through the steps of flashing a specific version of the firmware that was made available at the time that specific article was written. I instead wanted to use something that was slightly more *current*, which is another way of saying that I couldn't get the other one to work that one time I tried it. For that reason I'll be going through the steps needed to install the latest version of the [Zimodem](https://github.com/bozimmerman/Zimodem)-firmware instead.

- [1> Setting it up](#1-setting-it-up)
  - [1.1> Installing Zimodem](#11-installing-zimodem)
  - [1.2> Initial setup](#12-initial-setup)
  - [1.3> Plugging it in](#13-plugging-it-in)
  - [1.4> Finishing up](#14-finishing-up)

## 1.1> Installing Zimodem
If you're familiar with building and installing sketches from the *Arduino IDE*, then that should make the instructions here feel very familiar though I do **caution** you to pay attention to the *details* along the way. There are some that will cause your build not to compile, or even fail to work even though the upload would *appear* to succeed - just not actually function!

Additional Boards Manager URLs

Your first step on the way is that you will need the older version of *Arduino IDE*, meaning what [Arduino](https://www.arduino.cc/en/software) now lists as *Legacy IDE (1.8.X)*. With the software living somewhere on your hard-drive, download the latest release of [Zimodem](https://github.com/bozimmerman/Zimodem) (under releases it will be listed as *"Source code (zip)"*) and extract it somewhere that you'll be able to find, rougly ten seconds from now. Open up the sketch named zimodem.ino, found in the zimodem directory. The ESP8266 we're using isn't a product created by Arduino, so we need to install additional things in order to use it. In order to find those things, we first need to add an "Additional Boards Manager URLs" under *File* &rarr; *Preferences*.

> http://arduino.esp8266.com/stable/package_esp8266com_index.json

Boards Manager

The previous step only defined somewhere that the software could look for board definitions, it won't actually install any of them. For that we need to head on over to *Tools* &rarr; *Board <selected board name>* &rarr; *Boards Manager...*. Search for *"esp8266"* and you should find the one shown above, but note that we **NEED** to install an older version of it. There are newer versions available, but I was never able to get any of them working beyond version **2.7.4**. I have no idea as to why this is still the case, but this isn't related to Zimodem as even basic blink sketches will have these issues. So... use the *selection version* dropbox to select the correct version.

Select board
Board settings

With the definitions in place, select the specific board by going to *Tools* &rarr; *Board <selected board name>* &rarr; *ESP8266 Boards (2.7.4)* &rarr; *Generic ESP8266 Module*. The next step is to setup your board settings, and while I have no idea what most of that means - the settings above are the ones that worked for me. Just start at the top and work your way down.

Hit compile and watch everything assemble itself before your eyes. If something fails, doublecheck all of the steps covered so far. Connect up your ESP8266 to your computer via a USB-cable, ideally it should not be plugged into the *BulkyModem* during this step - mostly because you never know what kind of sketch was put on it the last time you were playing around with it. Select the relevant serial port from *Tools* &rarr; *Port*, normally you would only have one show up here (check *Device Manager* in case you have more and want to figure out which is which, alternatively just pull one and see which one disappeared).

When uploading the sketch to your ESP8266 there is an extra step you probably aren't familiar with if you've only used standard Arduino-modules, we need to put the module into a specific mode so that it knows that we're uploading something to it. The correct procedure as far as I've understood it is to press and keep holding *FLASH*, momentarily push *RST* - only then can you click upload in the *Arduino IDE*.

Keep holding that button until you see that it starts writing changes to the flash. It will take quite a bit of time, even appearing to freeze for up to 20 seconds while clearing the entire flash contents. Keeping the *Aduino IDE* open, continue on to the next section in order to start talking to the modem software.

## 1.2> Initial setup
As mentioned in the previous chapter, we now need to start communicating with the modem software. While you can probably complete these steps using the procedures listed in the getting started guide for [modern systems](https://github.com/tebl/BulkyModem/blob/main/documentation/getting_started_modern.md), just don't go plugging it into a vintage system to see *if* something that's not quite so easily replaceable blows up. Since I've already forced you to use *Arduino IDE*, might as well complete the initial setup using its *Serial Monitor*.

Serial Monitor

If you're not familiar with it, it's the top right icon that looks like a magnifying glass. The modem itself needs some very specific settings in order to work - ensure that the first dropdown is set to *newline* and baud rate is set to *1200*. Hit the *RST* button on the module and you should get some information about the modem software that we installed along with any stored network settings. Commands are entered into the box at the top, hitting *enter* to send them.

```
C64Net WiFi Firmware v3.7.1
sdk=2.2.2-dev(38a443e) chipid=1458270 cpu@80
totsize=4096k ssize=379k fsize=1907k speed=40m
INITIALIZED
READY.
```

It may take some getting used to, but it is very intuitive when you get into it. The first command you need to send is *"at+config"*, it should repeat the command sent and reply with *OK* similar to the following. If at this point the ESP8266 appears to crash and give you a stack trace instead of anything sensible, then you probably used the wrong version of the board definitions as described in the previous section.

```
at+config
OK
 
Main Menu
[HOST] name: 
[WIFI] connection: Not connected
[FLOW] control: DISABLED
[ECHO] keystrokes: ON
[BBS] host: DISABLED
[PRINT] spec: 
[PETSCII] translation: OFF
[ADD] new phonebook entry
 
Enter command or entry or ENTER to exit: wifi

WiFi Networks:
[1] WiFi AP (-84)*

Enter number to connect, or ENTER: 1

Enter your WiFi Password: Test12345
```

This gives you a listing of the relevant options, the following command is the part that is capitalized. So in order to configure *WiFi* you would send "*wifi*", then - once it responds with list of seen wireless networks you point one out using the digit in front of it. Note that the ESP8266 only supports 2.4 Ghz wireless networks, so those are the only ones that you'd see. Just follow the prompts and it should make sense.

The *BulkyModem* uses flow control, and so from the configuration menu (*at+config* in case you already forgot) we would use the command *FLOW* and set it to *"rtscts"*. Except we can't do that here because the module itself can't use those signals, and if you were to enter it you would only lock yourself out until it is reset again. So don't do that yet. Instead just hit *enter* to exit out of the menu, send *y* to save your network details. For the rest you need to connect it up using something that supports the RTS/CTS. Ideally a [modern systems](https://github.com/tebl/BulkyModem/blob/main/documentation/getting_started_modern.md) connected to the modem via a suitable *USB to RS-232*-adapter.

## 1.3> Plugging it in
Your *BulkyModem* can be powered up using any good quality 5V DC center positive PSU with a 2.1mm x 5.5mm barrel connector, but note that while a USB-cable going to the ESP8266 may work - you won't get the joy of using the ON/OFF button. 

MEAN WELL GST25B05-P1J

While I've been known to skimp on just about every component, I don't recommend going the cheap route when it comes to a good and reliable PSU - opting instead for "*reasonable*". The one I'm using is a *MEAN WELL GST25B05-P1J*, although I'm sure there are several suitable options available - it is one that I can recommend. At least as far as having worked for me.

## 1.4> Finishing up
Note however that before even considering plugging it up to any of your vintage computer equipment, you should try it out without anything else plugged into it - if it blows up, it's the only thing blowing up. If all goes well, then the next exciting step is the [getting started](https://github.com/tebl/BulkyModem/blob/main/documentation/getting_started.md) guide. While there is somewhat limited excitement to be had hooking it up to a modern system via an RS-232 adapter, it's where I recommend starting before even considering hooking things up to a vintage system. All that and more in the aforementioned [getting started](https://github.com/tebl/BulkyModem/blob/main/documentation/getting_started.md)-guide.

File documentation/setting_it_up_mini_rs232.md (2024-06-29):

# 1> Setting it up (Mini RS-232)
The [documentation](https://github.com/tebl/BulkyModem/tree/main/BulkyModem-32%20Mini) that comes with the main module, mainly only deals with the process of soldering the device together. The purpose of this document is instead to focused on everything related to the firmware we want running on our ESP-32, [Zimodem](https://github.com/bozimmerman/Zimodem).

ESP-32

- [1> Setting it up](#1-setting-it-up)
  - [1.1> Installing Zimodem](#11-installing-zimodem)
  - [1.2> Initial setup](#12-initial-setup)
  - [1.3> Plugging it in](#13-plugging-it-in)
  - [1.4> Finishing up](#14-finishing-up)

## 1.1> Installing Zimodem
If you're familiar with building and installing sketches from the *Arduino IDE*, then that should make the instructions here feel very familiar though I do **caution** you to pay attention to the *details* along the way. As the software is actively being developed there will be changes that would inevitably cause this guide to go out of date, so try to observe the thinking behind the tasks rather than expecting everything to be completely identical.

For this guide I'm using the more modern *Arduino IDE*, as opposed to the *Legacy IDE* that are still required by the ESP8266-version of the hardware. I don't believe upgrading is necessary, but while chasing down some issues I ended up upgrading and so the instructions are for the new one instead. Though everything has been shuffled around between the generations of the interface, most should still be recognizable to people familiar with either.

Boards Manager

As we'll be using an ESP-32, we need to add the board definitions that are needed for this project. To do that we need to head on over to *Tools* &rarr; *Board: <selected board name>* &rarr; *Boards Manager...*. Search for **"esp32 espressif systems"**, and the only listed is the one we need. Do however note that we **NEED** an older version of it in order to ensure that everything's working properly, use the dropbox to select the correct version - which is currently **2.0.7**.

Select board

Select the specific board by going to *Tools* &rarr; *Board <selected board name>* &rarr; *esp32* &rarr; *ESP32 Dev Module*. After selecting it you need to ensure that your board settings are correct, and while I have no idea what most of it actually means - the settings that are also shown in the previous pictures, are the ones that have worked for me. Just start at the top and work your way down the list.

The *BulkyModem-32 (Mini RS-232)* has been wired up for a 5-wire serial setup, meaning that we're using hardware-based flow control (RTS/CTS) in addition to TX, RX and a shared ground. You can configure this from the software itself using the command-line interface, but if you want to ensure that it is set up correctly from the start - you can search for the first line shown below (*"INCLUDE_PING true"*), and then add the two other lines directly below it.

```
# define INCLUDE_PING true
# undef DEFAULT_FCT
# define DEFAULT_FCT FCT_RTSCTS
```

With all of that out of the way, hit *Verify* and watch everything compile before your eyes. If something fails, doublecheck all of the steps covered so far. Connect up your ESP-32 to your computer via a USB-cable, ideally it should not be plugged into the *BulkyModem-32 (Mini RS-232)* during this step - mostly because you never know what kind of sketch was originally put on it. Usually it's a *blink*-sketch if it came fresh out of the package, but if it's something you've played around with earlier then it's always a good idea to play it safe. As far as I understand, the new *Arduino IDE* is supposed to be able to select the correct serial port for you, but if it doesn't work - then check it from *Tools* &rarr; *Port*.

If the process succeeded, hit upload and you should be good to go. At this point the Zimodem-firmware should be installed on your ESP-32, and you can insert it into the *BulkyModem-32 (Mini RS-232)*.

## 1.2> Initial setup
One key difference between Zimodem running on an ESP8266, and that of an ESP-32 is that the latter has two separate UARTS. While you can get some debugging information on the serial interface available, everything we would associate with using the Zimodem will only be available over RS-232.

Most of the steps needed will be covered in the *getting started*-guide for [modern systems](https://github.com/tebl/BulkyModem/blob/main/documentation/getting_started_modern.md). Mostly because I can't recommend simply plugging it into a vintage system to see *if* something that's *not-quite-so-easily-replaceable* blows up in your face. Going forward I'll be using [Tera Term](https://teratermproject.github.io/index-en.html) software, as well as an *RS-232 to USB*-adapter from a somewhat recognizable brand.

Startup screen

Starting it up, it will default to *TCP/IP* so change it over to *Serial* and ensure that your adapter is plugged in (not the ESP-32, in case you're powering it from the same computer). We won't be able to change any of the settings here for baud rate and flow control, for that we need to carry on with the defaults - for now.

Startup screen

Once into the main program, select *Setup* &rarr; *Serial port...* and you should get the screen shown above. The software will be running at **1200** baud by default, we'll also need to set up **RTS/CTS** if you've gone to step of altering the code as described earlier (use **none** if you didn't).

Startup screen

If you hit the physical *EN*-button on the ESP32-module, it should reboot and offer up a startup message such as the one shown above. You should now be able to type in commands and have it respond back to you, but before going through the initial setup we won't be doing very much with it. The first command you need to send is *"at+config"*, it should repeat the command sent and reply with *OK* similar to the following. 

```
at+config
OK
 
Main Menu
[HOST] name: 
[WIFI] connection: Not connected
[FLOW] control: DISABLED
[ECHO] keystrokes: ON
[BBS] host: DISABLED
[PRINT] spec: 
[PETSCII] translation: OFF
[ADD] new phonebook entry
 
Enter command or entry or ENTER to exit: wifi

WiFi Networks:
[1] WiFi AP (-84)*

Enter number to connect, or ENTER: 1

Enter your WiFi Password: Test12345
```

This gives you a listing of the relevant options, the following command is the part that is capitalized. So in order to configure *WiFi* you would send **wifi**, then - once it responds with list of seen wireless networks you point one out using the digit in front of it. Note that the ESP8266 only supports 2.4 Ghz wireless networks, so those are the only ones that you'd see. Just follow the prompts and it should start to make sense.

The *BulkyModem-32 (Mini RS-232)* uses hardware flow control, and so from the configuration menu (*at+config* in case you already forgot) - we can use the command **flow** in order and enter the response **rtscts** to set it correctly. After doing that we just need to hit *enter* to exit out of the menu, sending *y* to save your network details when prompted. Remember to set *Tera Term* to also use the same value for flow control.

## 1.3> Plugging it in

Your *BulkyModem-32 (Mini RS-232)* will be powered using a USB-cable connected up to your ESP32. Actual power draw should be quite low, so just about any reasonable quality USB-based power supply will work. For the *RS-232*-side of it, you'll most likely be using a standard serial cable (DB9-male to female).

**NB!** Dealing with vintage computers, don't go plugging and unplugging things while either of them is powered. It should be *OK*, in the same way it was *OK* back in the days any of the equipment were considered current. Except that all of these things are now ancient, and not quite as easily replaced...

## 1.4> Finishing up
If all goes well, and you're ready to [re]start exploring BBS-es you can follow along with the [getting started](https://github.com/tebl/BulkyModem/blob/main/documentation/getting_started.md) guide. While there is somewhat limited excitement to be had hooking it up to a modern system via an *RS-232 to USB*-adapter, it's where I recommend starting before moving onto vintage systems. All that and more in the aforementioned [getting started](https://github.com/tebl/BulkyModem/blob/main/documentation/getting_started.md)-guide.

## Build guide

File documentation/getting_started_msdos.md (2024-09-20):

# 1> Introduction
This section of the documentation deals with how to get started with a specific system or program related to the use of the *BulkyModem*. While it may in many cases be relevant for use with any similar modem, there may be differences encountered. This document assumes that you have already read the main document on [getting started](https://github.com/tebl/BulkyModem/blob/main/documentation/getting_started.md) as some terms may previously have been defined there.

- [1> Getting started](https://github.com/tebl/BulkyModem/blob/main/documentation/getting_started.md)
- [2> MS-DOS](#2-ms-dos)
  - [2.1> Kermit](#21-kermit)
    - [2.1.1> Higher baud rates](#211-higher-baud-rates)
    - [2.1.2> Terminal type](#212-terminal-type)

# 2> MS-DOS
OK, so technically MS-DOS isn't a vintage system by itself, it's an operating system. The vintage system we're talking about, is mostly those that were advertised as *IBM PCs and compatibles*. While many - including me - would simply refer to it as *DOS* (*Disk Operating System*), that's inherently a bit messy in a project that touches on vintage systems that have systems that would also be described as a *DOS*. Most of them will have similarities as most of them were created at a time when *CP/M* had already defined what would have been expected from the system, including *MS-DOS* - just know that they're not the same. Did you need to know that? Probably not. 

I'm not going to go into great detail here as there are plenty of resources available online, but not all programs are necessarily easy to get started with so I'll at least try to offer some hints for some of them.

[Kermit](#21-kermit) for MS-DOS is supported on computers running versions all the way down to 2.0, meaning that it should even be able to run on original XT-class computers. If you want a definite answer instead of "should", send me an *IBM 5150* and I'll find out for you. As an original IBM-product, no expenses were spared on your behalf - so you should have a proper *ACIA* on at least one of your expansion cards. The smaller DE-9 connector that we're familiar with on more modern systems, relatively speaking, didn't exist at that point in time - so expect to use a DB-25 to DE-9 adapter if you're going that far back in time.

**NB!** DE-9 connectors are more commonly known as DB-9 connectors, because if a DB-25 has 25 pins, then surely one with 9 pins would be called a DB-9? Apparently not.

## 2.1> Kermit
[Kermit](https://www.kermitproject.org/mskermit.html) for MS-DOS is a well-known communications package that supports a **lot** of options, and by a "lot" - I mean a metric ton of them. You don't need to know a great deal to get started using it, just know that it seems to be more geared towards being a professional terminal emulation suite as opposed to being something that you'd use to connect up to a *BBS* (*Bulletin Board System*). So why am I recommending it then? Well... It's available, and it's been open-sourced so it seemed a likely candidate to get started with. The one I've been using on my vintage systems is version 3.14, simply because I had originally assumed that the newest version would be listed at the top.

The first step is to set some starting details regarding how it is connected to the system, as is common with the *BulkyModem* we'll set it up with 1200 baud, 8n1 and hardware flow control (RTS/CTS). I have it connected to COM2, so change that if you're using something else. The easiest way to ensure that all of this is set up when starting the software, is by editing the file *MSCUSTOM.INI* and changing the relevant sections. Note that these are commands as recognized by *kermit*, so these can be used interactively as well.

```
set modem hayes
set port 2
set speed 1200
set flow rts/cts
```

Start the program using the *kermit* command, and you'll encounter the *kermit* command-line that closely resembles does so don't be confused by its appearance. We're not actually connected to anything yet, for that you need to enter the command *connect* in order to switch over to the terminal view.

```
connect
```

At this point forward you're communicating over RS-232, so turn on the modem if you've not already done so. As long as the settings are correct, you should see the Zimodem-firmware print its own welcome text to the terminal. If you find that you need to get back to change any of the settings, hit ALT+X to get back to the command-mode for *kermit*. If you need to change to a speed that's a bit faster than this, see [higher baud rates](#211-higher-baud-rates) before continuing.

At this point you should be talking to the modem, and the *AT* command should result in an *OK* response on your terminal:
```
AT
```

To end with something more specific, here's the command for dialling a specific BBS (replace address details as needed):

```
ATD"cottonwoodbbs.dyndns.org:6502"
```

### 2.1.1> Higher baud rates
As mentioned initially, the recommended baud rate setting for *BulkyModem* should be kept to the default setting of *1200*. That doesn't necessarily mean that you are limited to this. First off we need to tell the modem to switch to something else, I'm using 9600 baud as an example going forward. First off we need to ensure that we are connected to the modem, and not still in *kermit*s command-line mode. Issuing the following command should be returned by an *OK*-message from the modem:

```
AT
```

Well aware that we're talking to the modem, we can tell *it* to switch speeds to 9600 using the following command:

```
ATB9600
```

At this point the modem switches speeds, but our terminal software doesn't know this - and neither does it understand the *OK* message that it received in return. This might be displayed as garbage on the screen, or nothing at all - that's a limitation of serial as it was back then, and as it is now. To update the terminal, hit ALT+X to get back to *kermit*s command-line and these commands to change speeds and return to talking to the modem:

```
set speed 9600

connect
```

At this point, both ends should be communicating as 9600 baud. Both the modem and computer should be able to talk at even faster rates than that, but it's a place to start.

### 2.1.2> Terminal type
Kermit is a powerful package, but it wasn't created with BBSes in mind - instead it was intended to replace hardware terminals such as the VT102 and so on. Generally the way you would interface with mainframes. That doesn't mean that it doesn't work, it just means that it might not be running in a mode that'd be able to display BBS graphics the way it was intended. While this certainly would vary depending on the places that you tell the modem to connect to, but the one that I've had the most luck with is named *ANSI*. You can switch to it while in command mode.

```
set term type ansi
```

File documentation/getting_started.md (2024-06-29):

# 1> Getting started
This documentation deals with how to get started with a specific system or program related to the use of the *BulkyModem*, but will in many cases also be relevant for just about any [Zimodem](https://github.com/bozimmerman/Zimodem)-based modems that you may already have. Many of the options out there will either be based on [Build your own 9600 Baud C64 WiFi Modem For $10](https://1200baud.wordpress.com/2017/03/04/build-your-own-9600-baud-c64-wifi-modem-for-20/), running an older version of the software that can be flashed onto the ESP8266 that it is based on. I did however want something that was slightly more current, and so I'm using the latest version of the previously mentioned Zimodem-firmware instead.

BulkyModem

However this isn't a history about the *BulkyModem*, it was supposed to be a guide on how to *get started* using it. For that we need to know a little bit about the ways it is different from other modems like it? The main difference you need to know about is that I didn't want to choose between building a modem for either a Commodore 64, or one that communicates over RS-232. For that reason it has a *mode*-button on the front of it, toggling it enables you to choose between the two interfaces. While you shouldn't go around trying to hook it up to two different machines at the same time, I wanted a modem that was capable of being moved from one computer to the next without needing to reprogram it or change the hardware itself in any way.

Which brings me to the modem itself, and while it is perfectly capable of supporting higher baud rates than the default of 1200 baud - I recommend that you keep it at that setting so that every system is able to talk to it after it starts up. Call it the *least common denominator* between the different systems if you will. When setting up your terminal we first set that up at 1200 baud as well, you can then choose to tell the modem to switch over to a higher baud rate and reconfigure your terminal to match. This way a fresh power-on will always start with something everybody understands.

This is by no means meant to be an exhaustive source of information for all things related to using modems on any vintage computer, the purpose is simply to provide you with some form of a starting point. I always recommend starting with the guide for a modern system on a newly built modem, mainly so that you don't blow up something that can't be replaced, at least not as easily as swiping a credit card. When you're suitably sure that everything works as it was supposed to, only then should you consider connecting it to a vintage system of your own choosing.

- 1> Getting started
    - [1.1> Modern system](https://github.com/tebl/BulkyModem/blob/main/documentation/getting_started_modern.md)
    - [1.2> Commodore 64](https://github.com/tebl/BulkyModem/blob/main/documentation/getting_started_c64.md)
    - [1.3> MS-DOS](https://github.com/tebl/BulkyModem/blob/main/documentation/getting_started_msdos.md)

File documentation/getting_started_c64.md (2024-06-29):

# 1> Introduction
This section of the documentation deals with how to get started with a specific system or program related to the use of the *BulkyModem*. While it may in many cases be relevant for use with any similar modem, there may be differences encountered. This document assumes that you have already read the main document on [getting started](https://github.com/tebl/BulkyModem/blob/main/documentation/getting_started.md) as some terms may have been defined there.

- [1> Getting started](https://github.com/tebl/BulkyModem/blob/main/documentation/getting_started.md)
- [2> Commodore 64](#2-commodore-64)
  - [2.1> UP9600](#21-up9600) 

# 2> Commodore 64
I'm not very familiar with using modems on the C64, mainly as I've never owned one while phone lines were still hooked up to regular houses. So instead of bragging about how I surfed BBS-es back in the day good old days, my experiences on this front are limited to having used them from the comfort of a standard beige IBM-clone. Until putting together the *BulkyModem*, so what follows is more a description of the steps I took in order to have fun with it on a *Commodore 64* in *the year of our lord 2024*!

> I wrote that last part in order to make things sound *ancient*, please replace any offending part - mentally, while reading or in your own github branch in order to fit with your own belief, and/or lack thereof.

For that reason alone I can't really provide you with a list of suitable software for every use-case, I instead only recommend that you start with loading up a copy of [CCGMS Future](https://github.com/mist64/ccgmsterm) - it is one that I've been able to successfully use. If you're unsure about the various commands, check out the online [Documentation](https://github.com/mist64/ccgmsterm/blob/main/Documentation.md) for it.

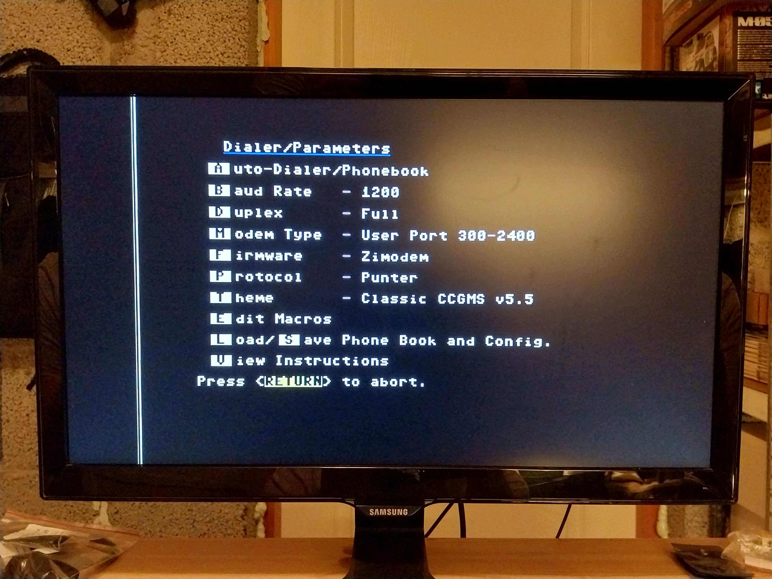
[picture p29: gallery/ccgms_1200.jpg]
CCGMS 1200 baud


Once the software loads hit the *F7*-key and ensure that modem type is set to *User Port 300-1200*, change baud rate option to 1200, set duplex to full and you should be good to go. Setting firmware to *Zimodem* is also an option though either setting seems to work from what I've tested. Hit *S* to save the configuration, then return to the main terminal screen. If you require more raw speed than what 1200 baud can provide, then see the next section on [UP9600](#21-up9600) for a way to increase it further.

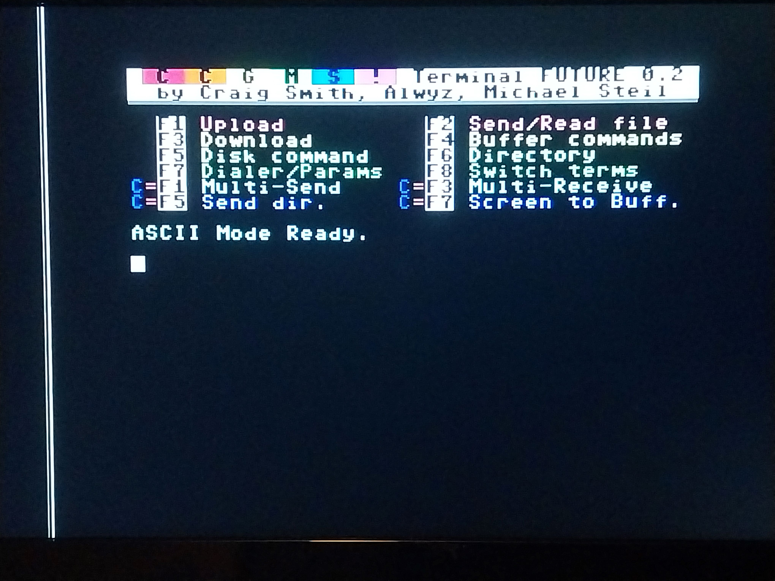
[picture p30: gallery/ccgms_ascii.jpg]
CCGMS ASCII


If for some reason you haven't completed the initial setup of your *BulkyModem*, mainly to configure your network settings as well as set flow control to match *BulkyModem* hardware - hit *F8*-key to toggle terminal type over to ASCII. This last bit is to avoid any confusion that would cause issues when attempting to enter your WiFi password, assuming that your password doesn't require any keys that your *Commodore 64* doesn't have. When finished, hit *F8* until you arrive back at the standard PETSCII-terminal. 

At this point you should be up and running with CCGMS Future, and from that point on I expect you'll want to dial your first BBS. I won't go into much more detail about the program as most other details will be shared between all systems, because after all; you're talking to a Hayes-modem (in an emulated *fashion* at least). For information about which commands the Zimodem understands, check out its main [README](https://github.com/bozimmerman/Zimodem) for that information.

To end with something specific, here's the command to dial a specific BBS (replace address details as needed):

```
ATD"cottonwoodbbs.dyndns.org:6502"
```

## 2.1> UP9600
Sometime in 1997, someone found out how to communicate with serial-attached devices at devices exceeding 1200-baud - all the way up to a blistering 9600 baud! This requires some changes to the way your *Commodore 64* communicates over serial, in fact it does so using some timers that had not previously been used on the machine - for all of the exciting details on how this is done, set the article [UP9600: How to Bit-Bang 9600 Baud RS-232 on the C64](https://www.pagetable.com/?p=1656).

> Note that this specific - albeit faster - mode of communication simply isn't possible on the Commodore 128. This is because of the timers that were previously unused on the Commodore 64, have now been put to use in order to implement "burst"-mode on the 128. While the hardware is only explicitly used when communicating with 1571 disk drives, it is there in the firmware and you will encounter problems due to it. As far as I know, even connecting a UP9600-enabled device to the computer will cause it to not start up properly. So if you have a 128, don't enable UP9600 - the modem itself will still work, just at the original 1200 baud. 

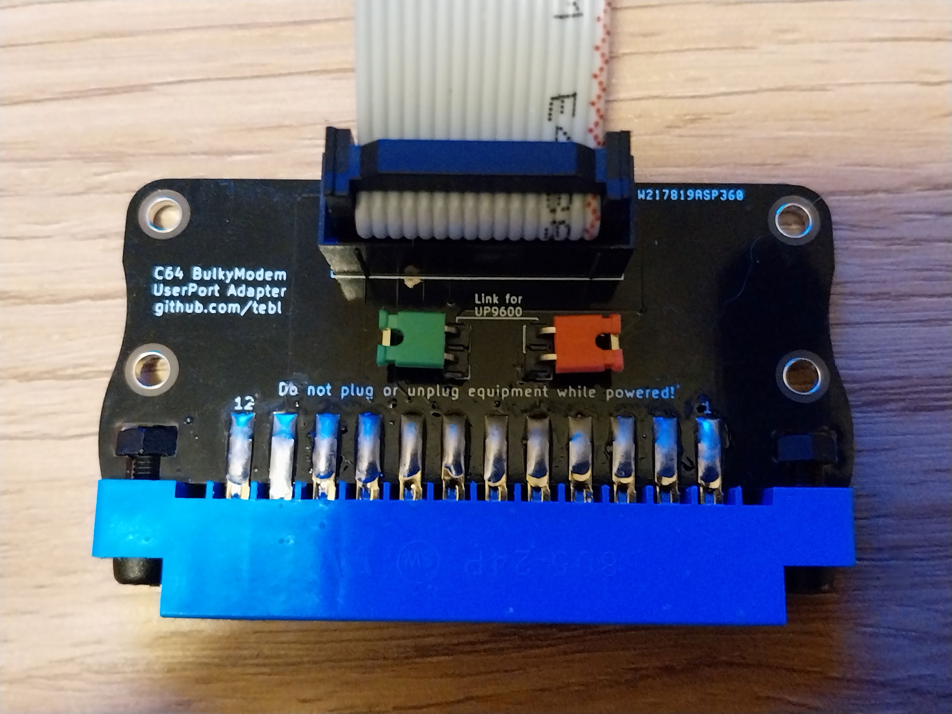
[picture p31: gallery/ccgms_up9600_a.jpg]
UP9600-jumpers


In order to enable this mode for use with on a *Commodore 64*, you first need to add the two jumpers on your *UserPort*-adapter (the jumpers are in a different place from what is shown). Note that this should only ever be attempted while your system is turned off, ideally you shouldn't be poking at it with your bare fingers either - especially if you've ever found yourself building up a charge while shuffling around in your house (static electricity and all that). This won't make the software magically update to match the changes you've made, for that you need to update your settings to match.

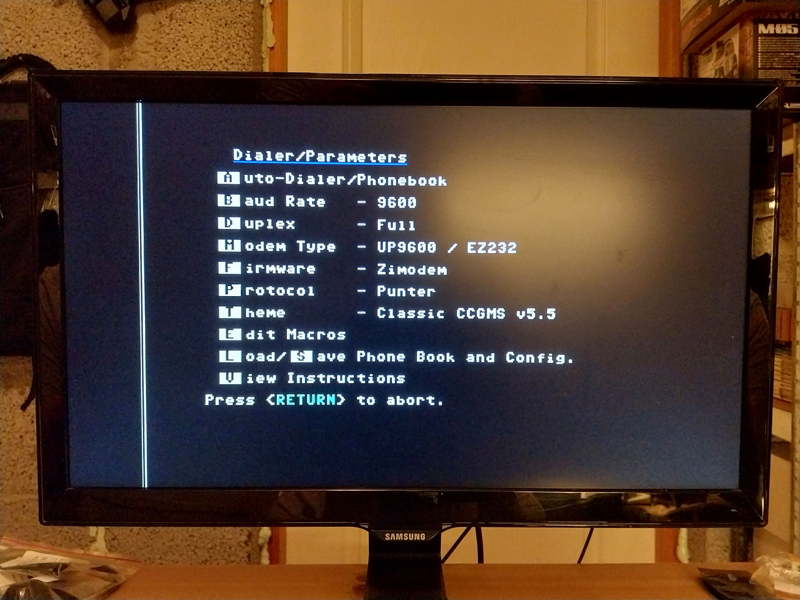
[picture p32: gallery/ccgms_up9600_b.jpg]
UP9600-settings


Which means that back in CCGMS you should still see it connected at 1200 baud, in order to increase the rate of transfer you can issue the command *atb9600* in order to tell your modem to switch over to 9600 baud. There'll be some weird characters in response on your terminal when doing so, this is because your terminal is no longer matches that of the new modem setting. To fix that you only have to press *F7*, and from there you set modem type to *UP9600 / EZ232*, set baud rate to 9600 and exit out again to have everything talking together again. This does sound quite a bit convoluted, but please consider that while you can issue commands to have a modem temporarily switch to a faster speed - you won't be able to send a command to a modem running at speeds faster that your computer can transmit!

```
ATB9600
```

One thing I would recommend is that you do **not** save changes on your modem after changing baud rate, that's the *at&w* command by the way. It might sound like a painful way to do things, especially since you'd need to do this every step the modem is powered on. That is however the way it was done back in the day. The reason for this requirement is that while you can happily issue new commands to have a modem temporarily switch to a faster speed, the other direction might not be quite as easy. It's surprisingly hard to tell a device to slow down, especially if it's already running at speeds faster than what your vintage computer is capable of communicating at.

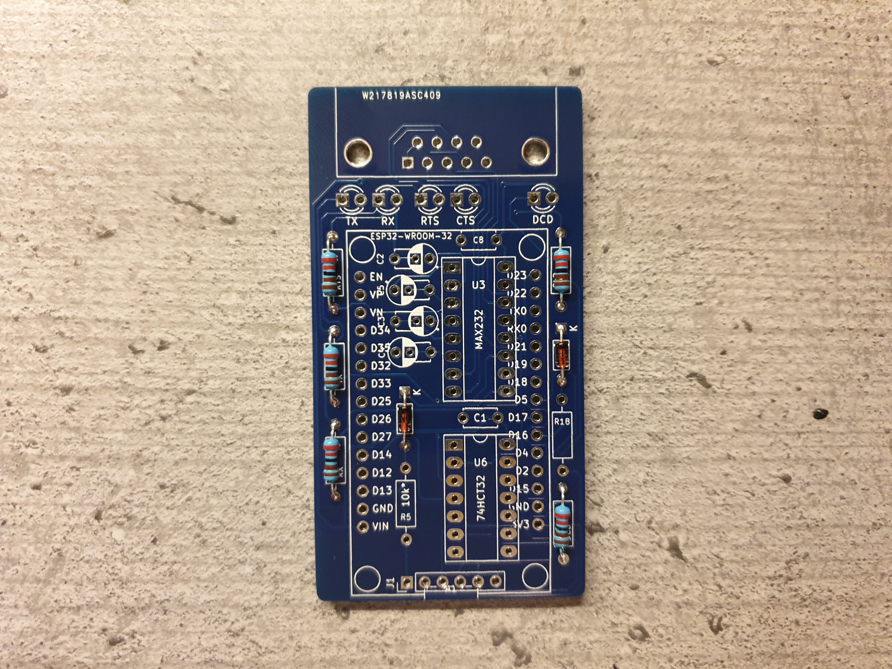
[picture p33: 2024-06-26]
gallery/build/mini32_rs232/004.jpg

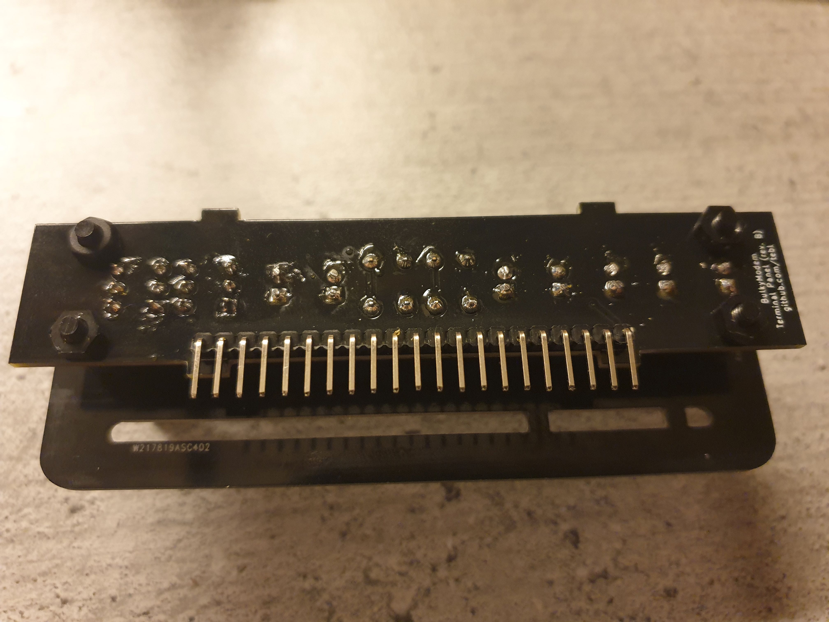
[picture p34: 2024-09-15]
gallery/build/terminal/panel_007.jpg

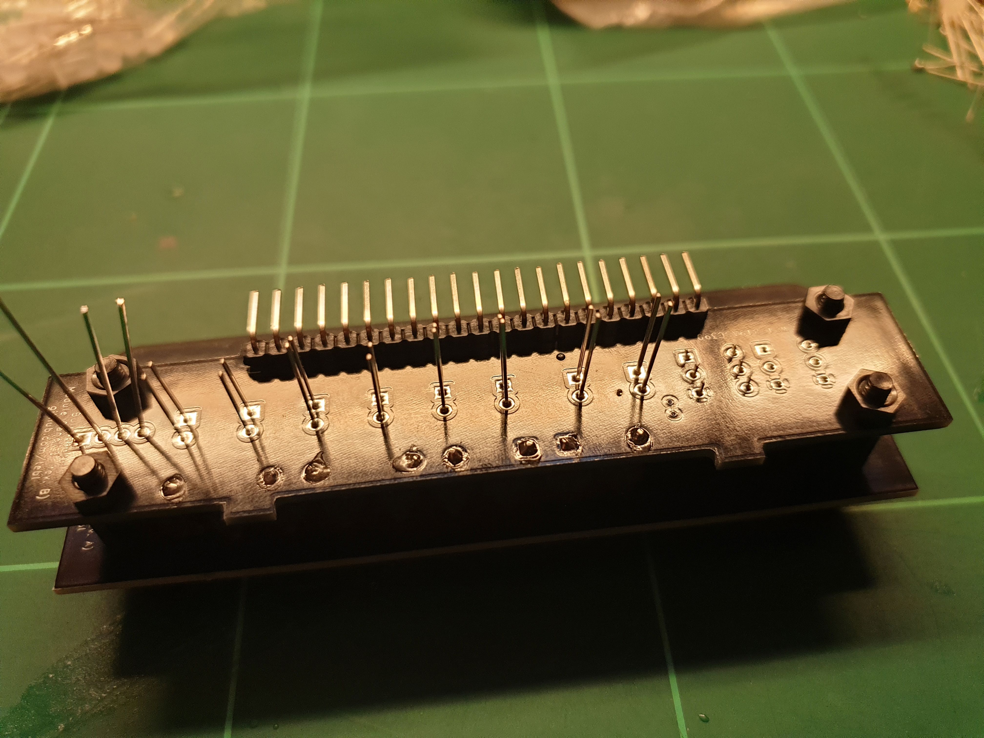
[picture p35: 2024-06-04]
gallery/build/panel_b/013.jpg

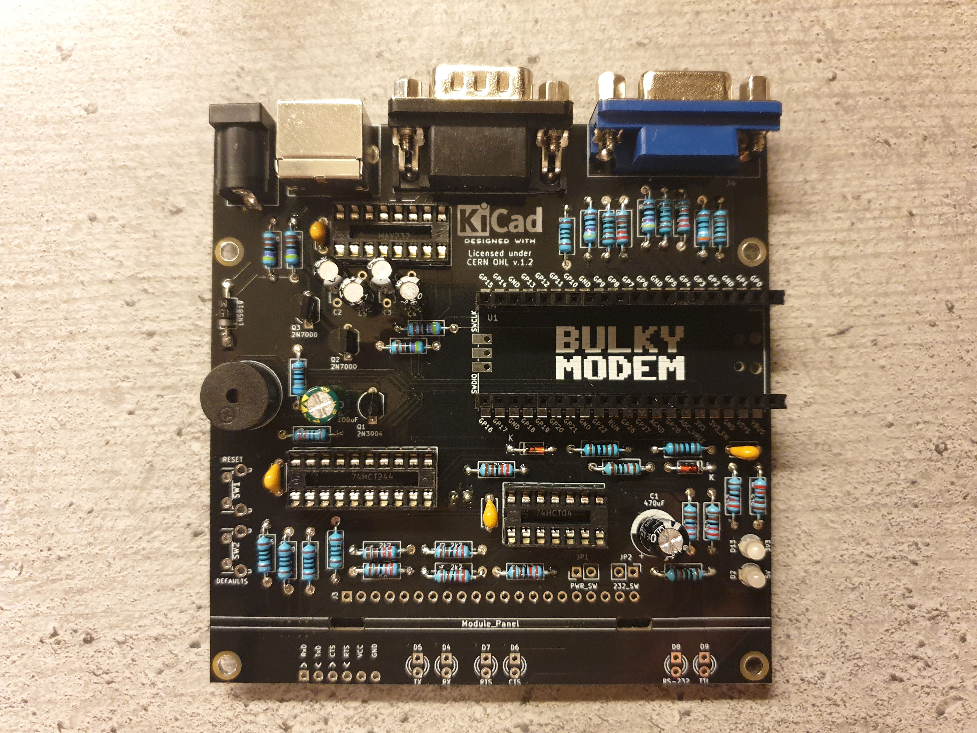
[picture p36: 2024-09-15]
gallery/build/terminal/025.jpg

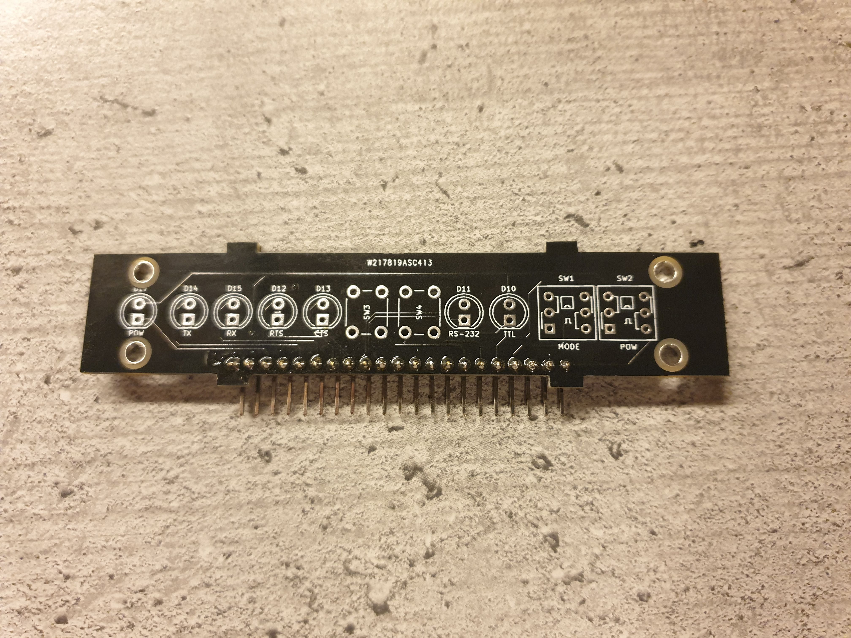
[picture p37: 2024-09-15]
gallery/build/terminal/panel_003.jpg

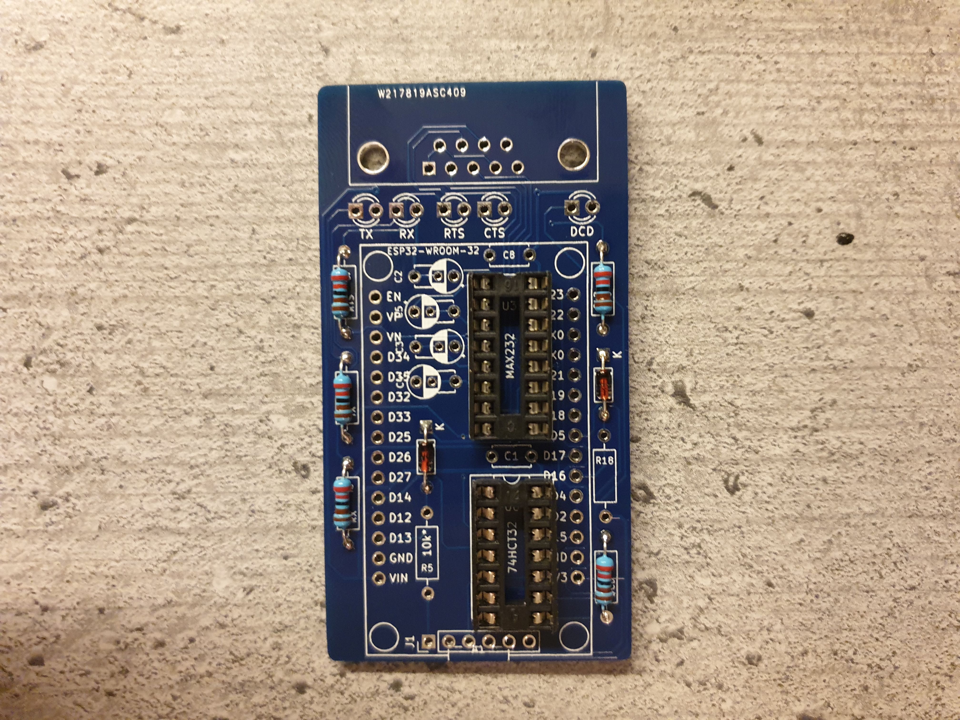
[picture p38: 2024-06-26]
gallery/build/mini32_rs232/005.jpg

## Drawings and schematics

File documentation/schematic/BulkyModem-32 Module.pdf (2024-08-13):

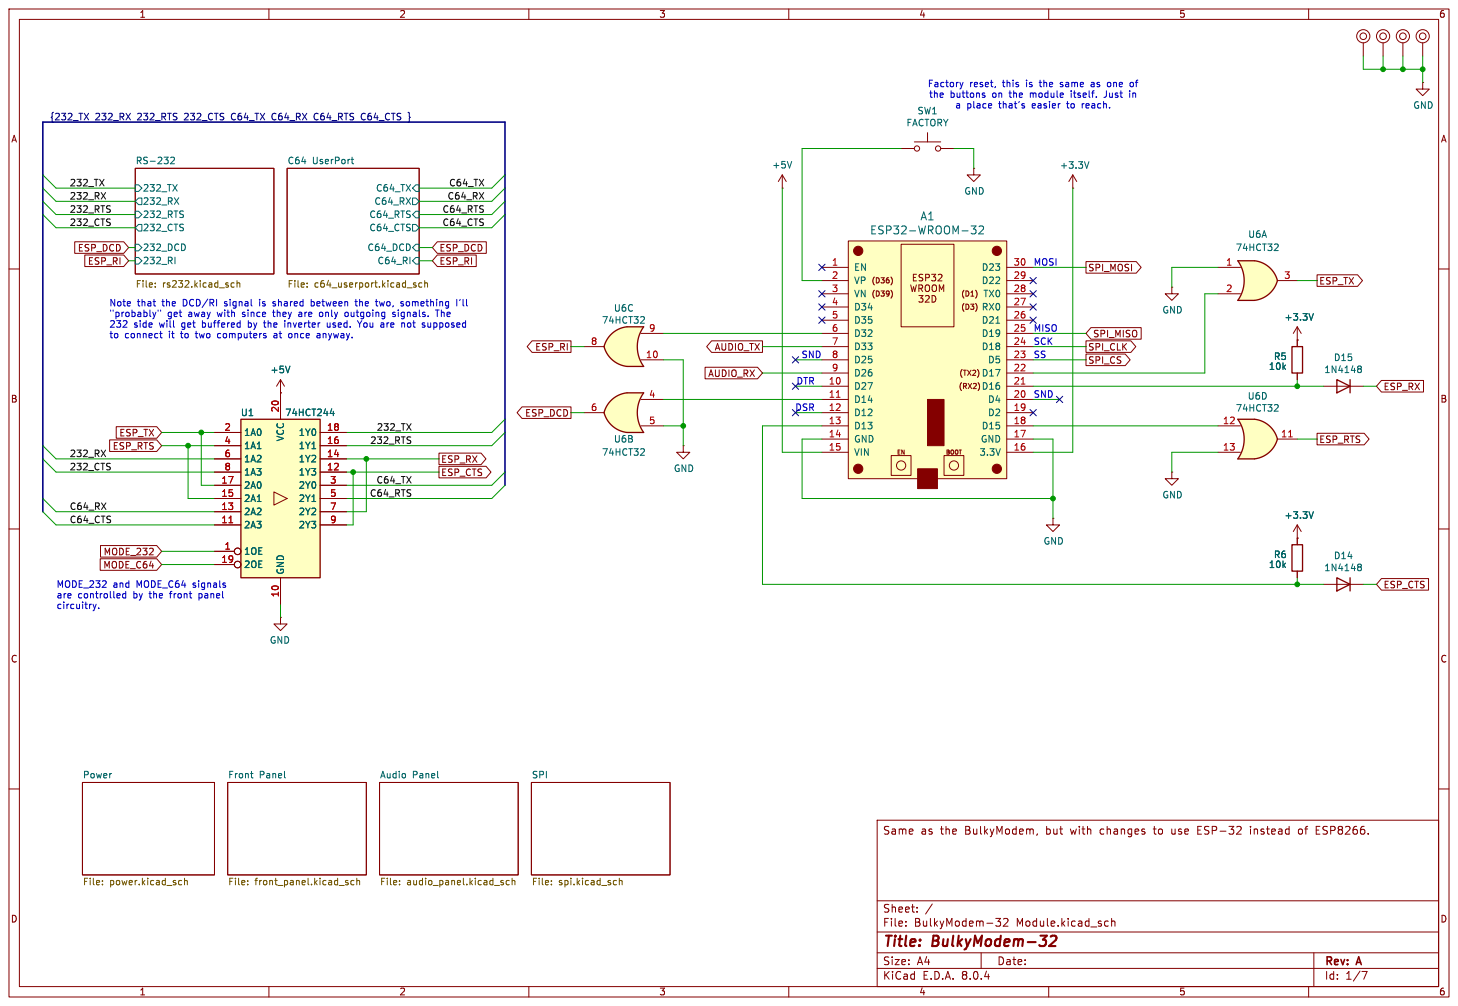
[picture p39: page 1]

Factory reset, this is the same as one of
a place that's easier to reach. SSMISO

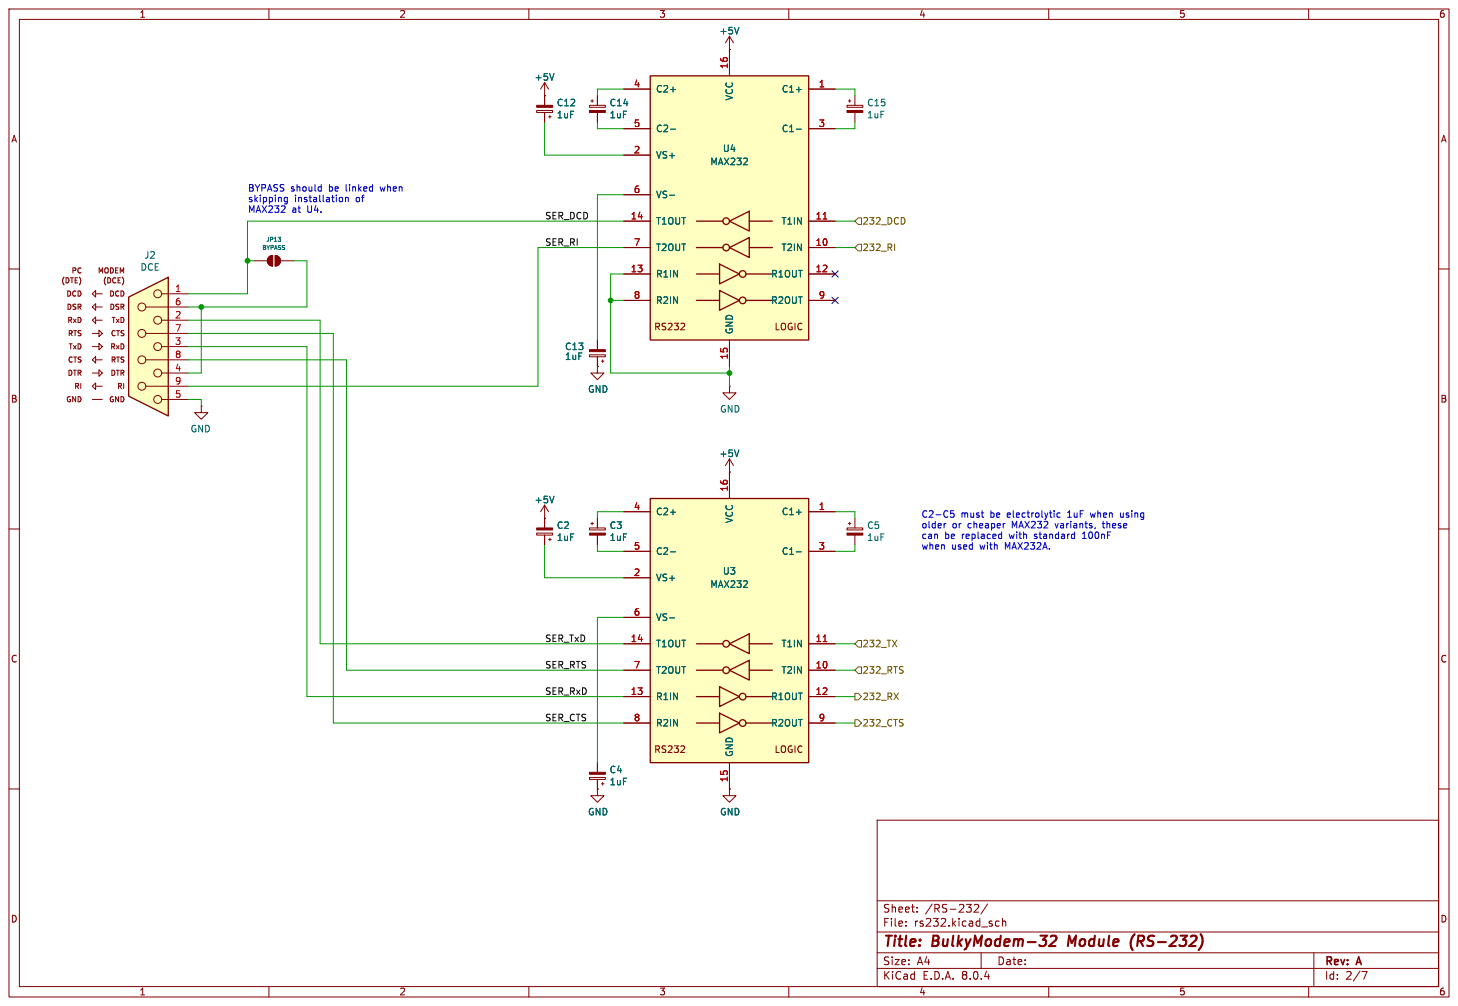
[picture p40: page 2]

BYPASS should be linked when

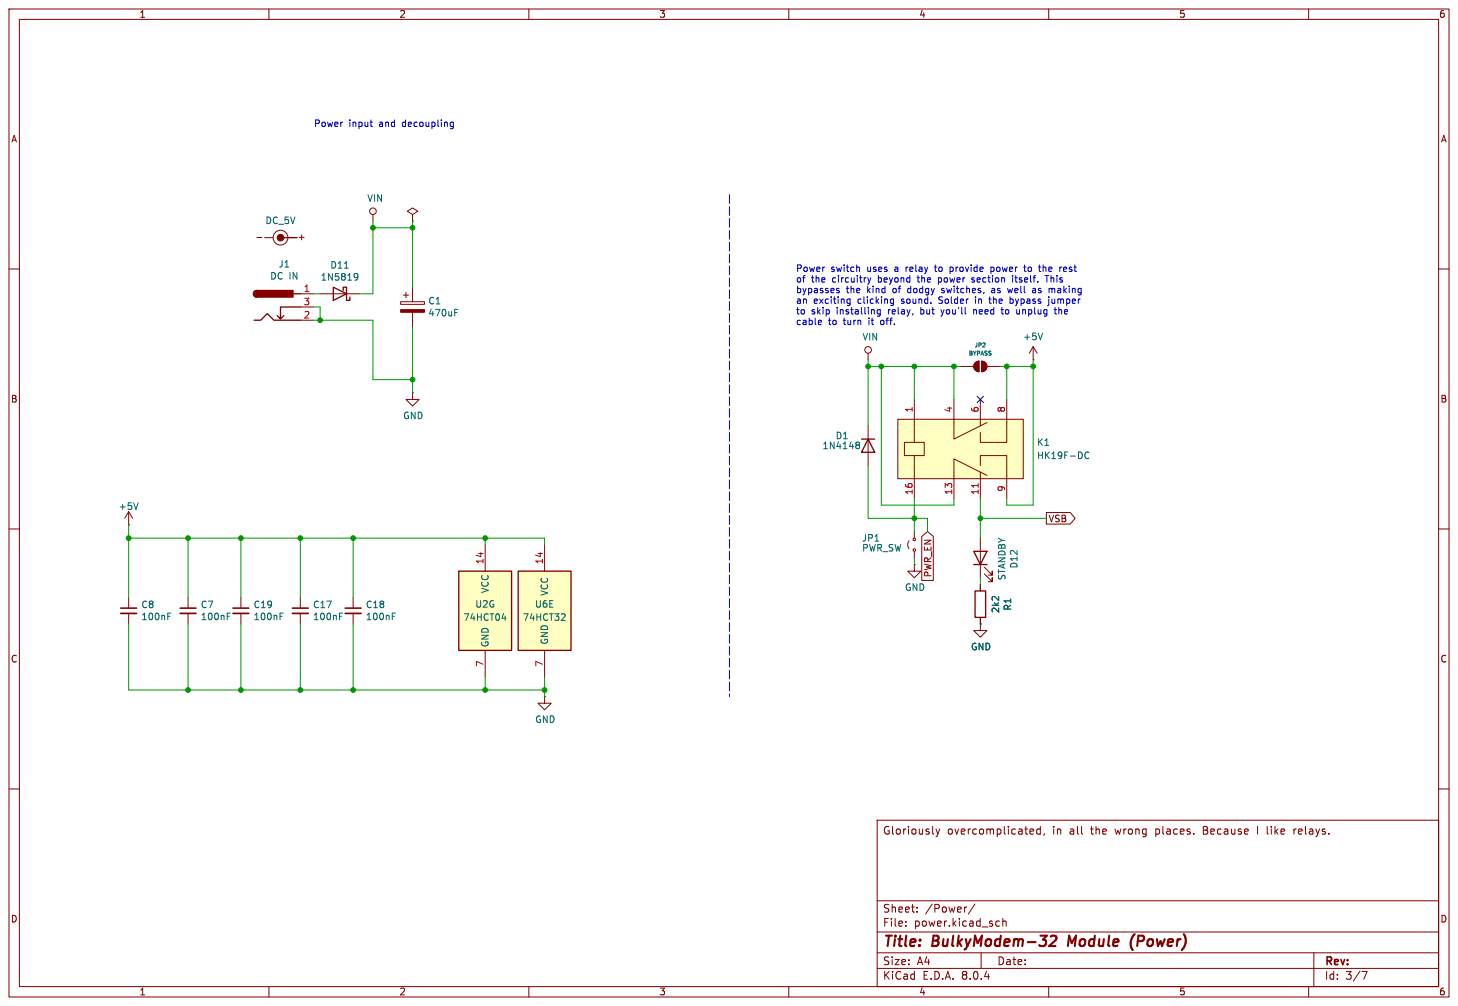
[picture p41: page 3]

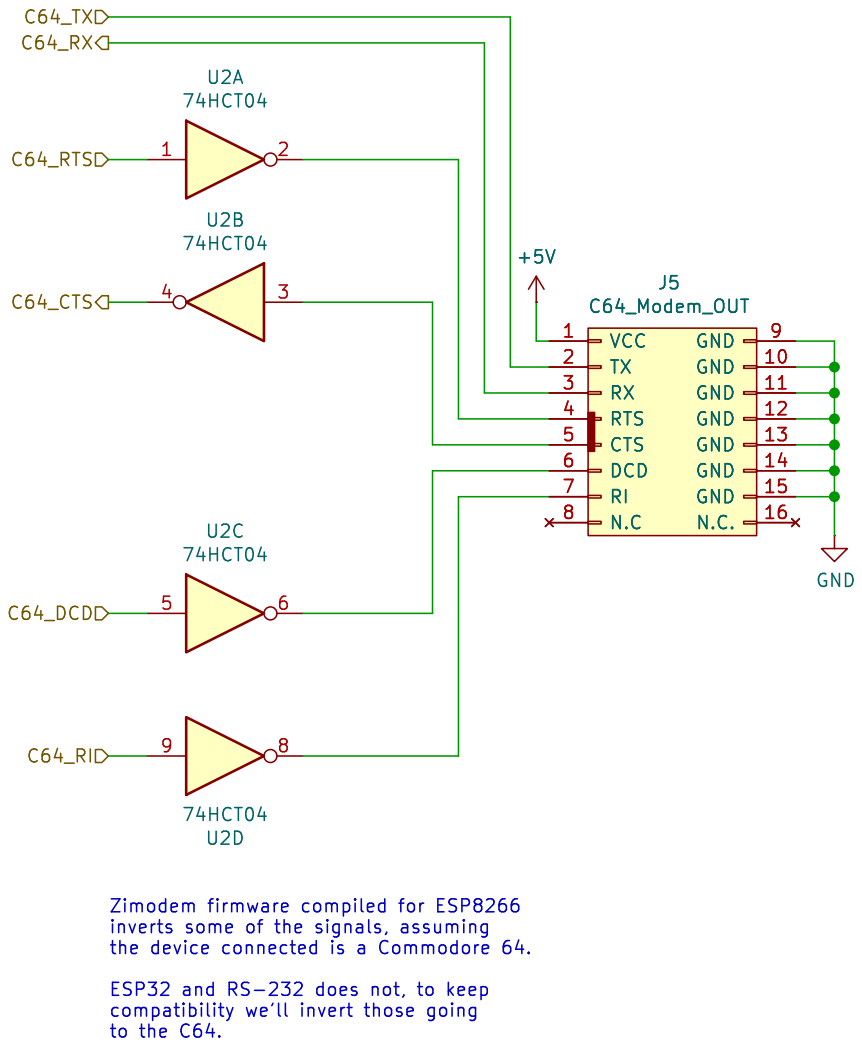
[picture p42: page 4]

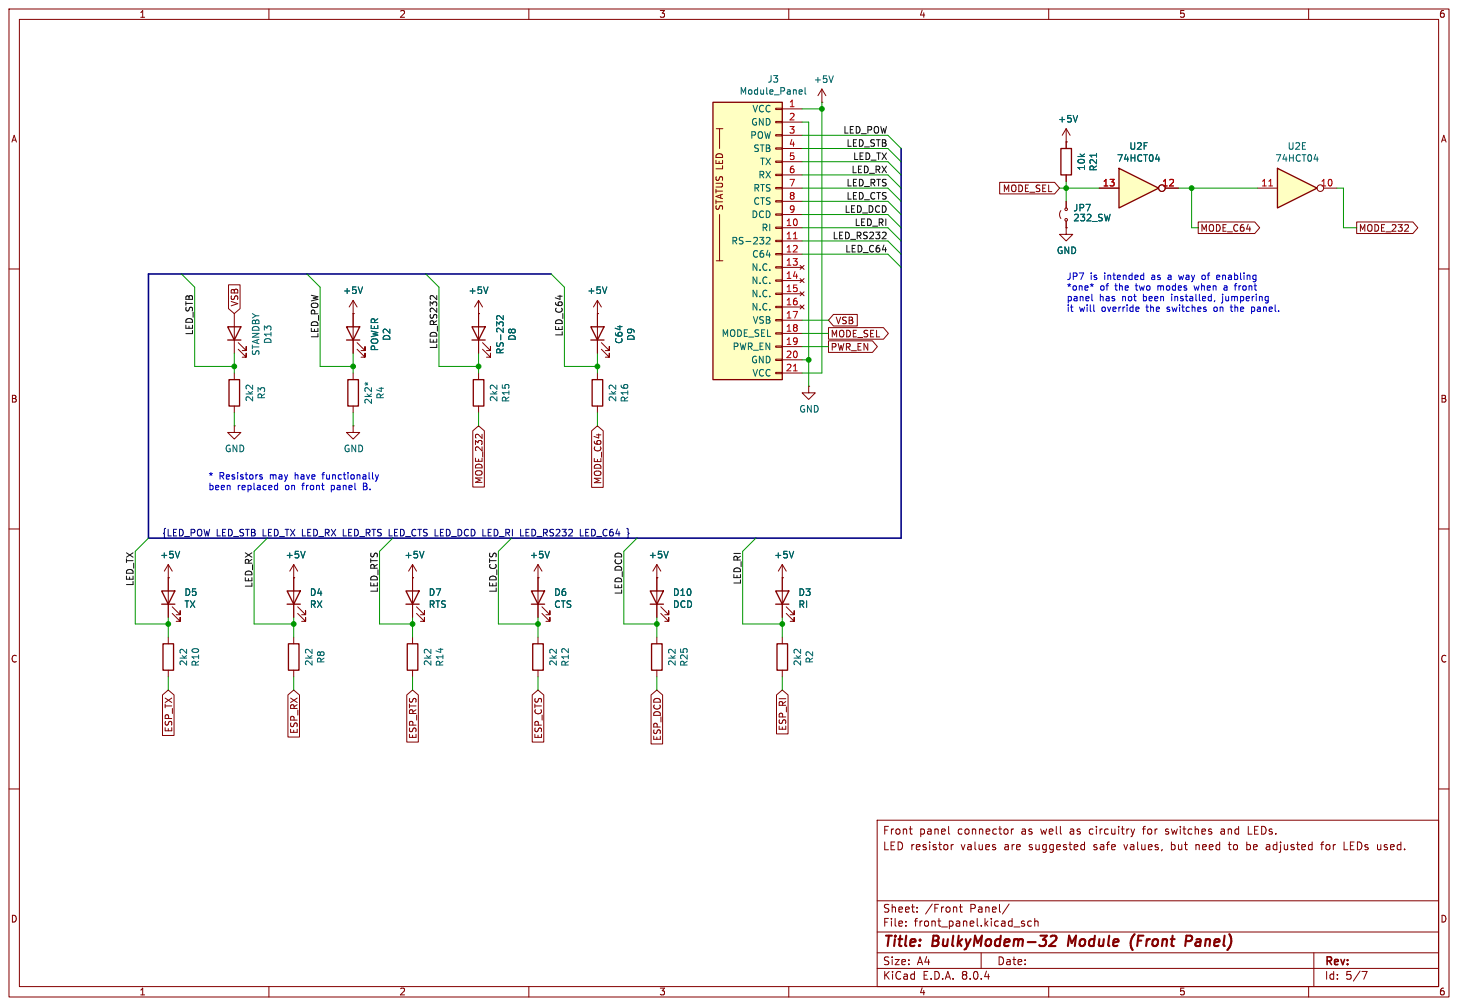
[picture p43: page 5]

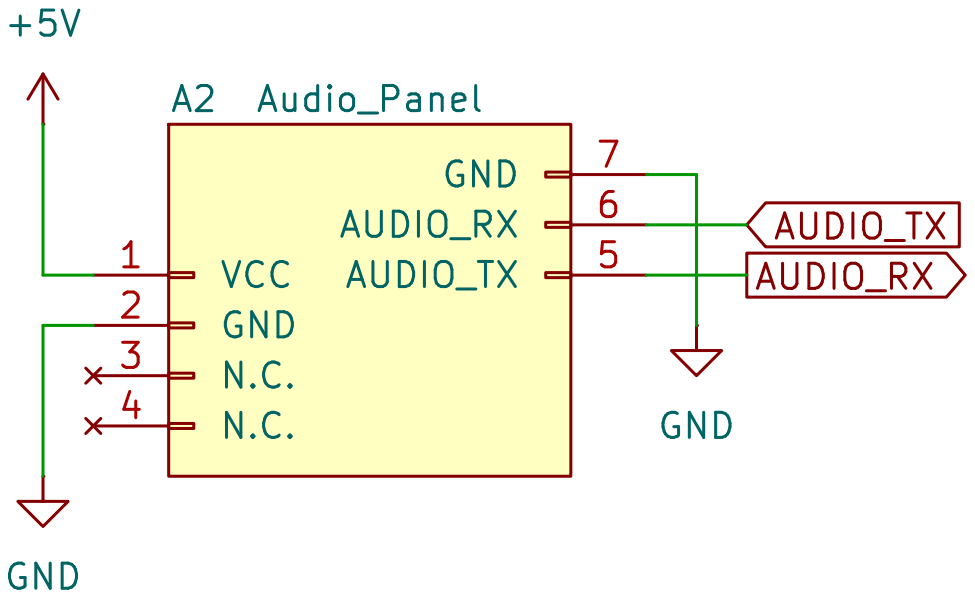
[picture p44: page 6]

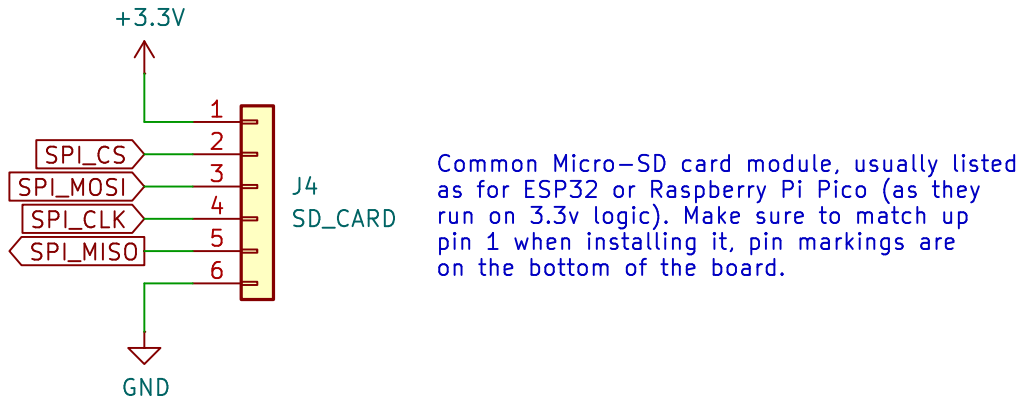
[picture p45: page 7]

as for ESP32 or Raspberry Pi Pico (as they
on the bottom of the board.

Id: 7/7 Title: File: spi.kicad_sch Sheet: /SPI/

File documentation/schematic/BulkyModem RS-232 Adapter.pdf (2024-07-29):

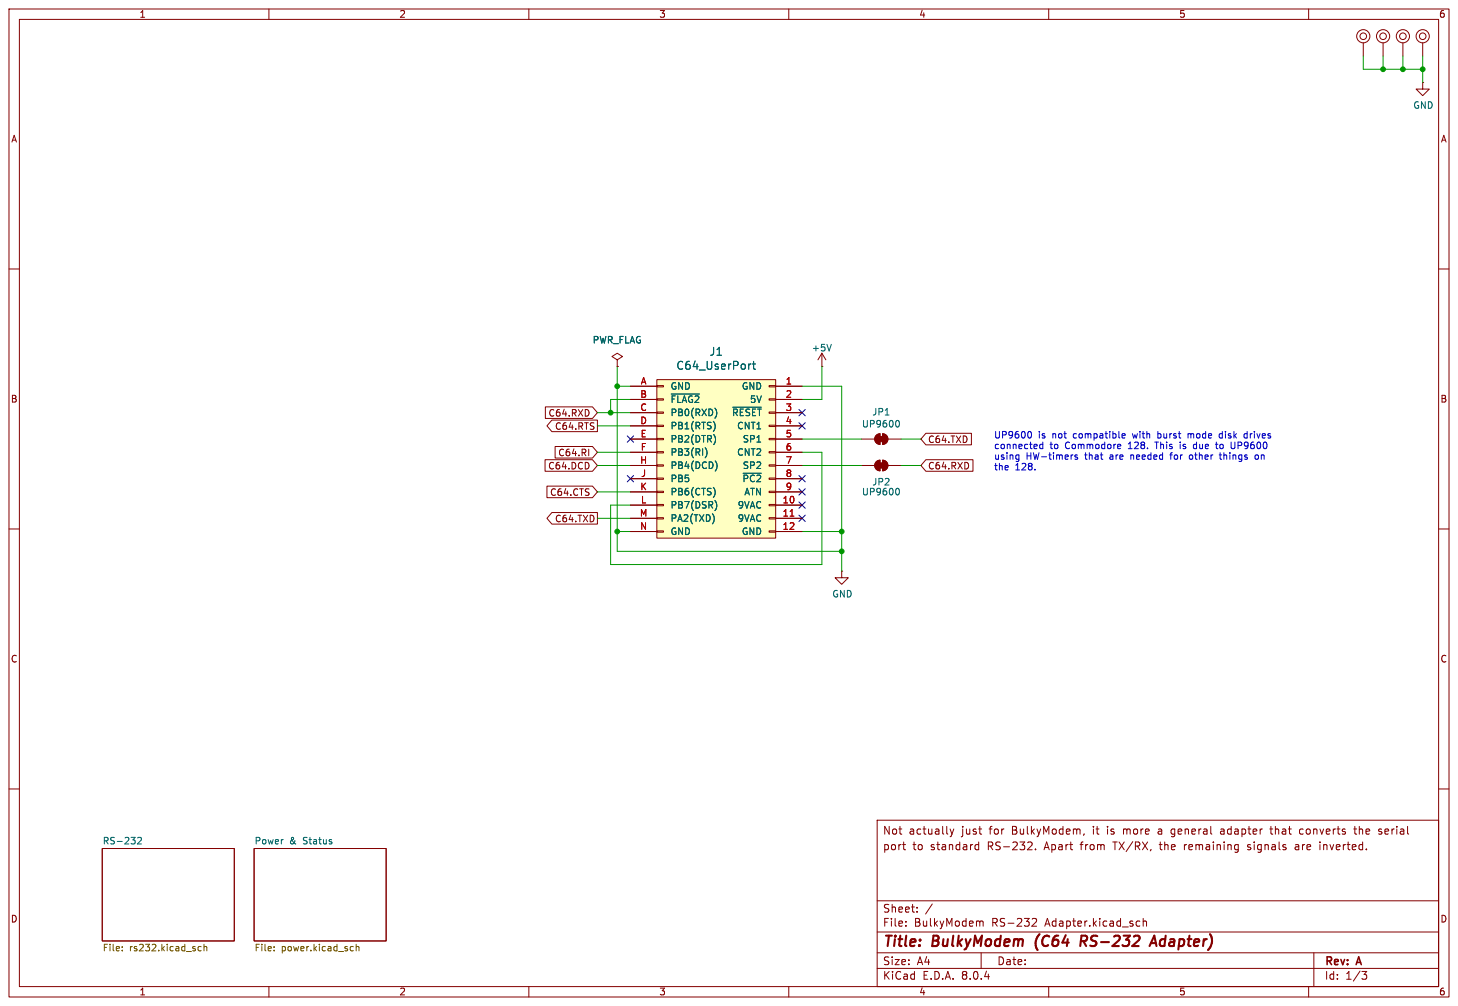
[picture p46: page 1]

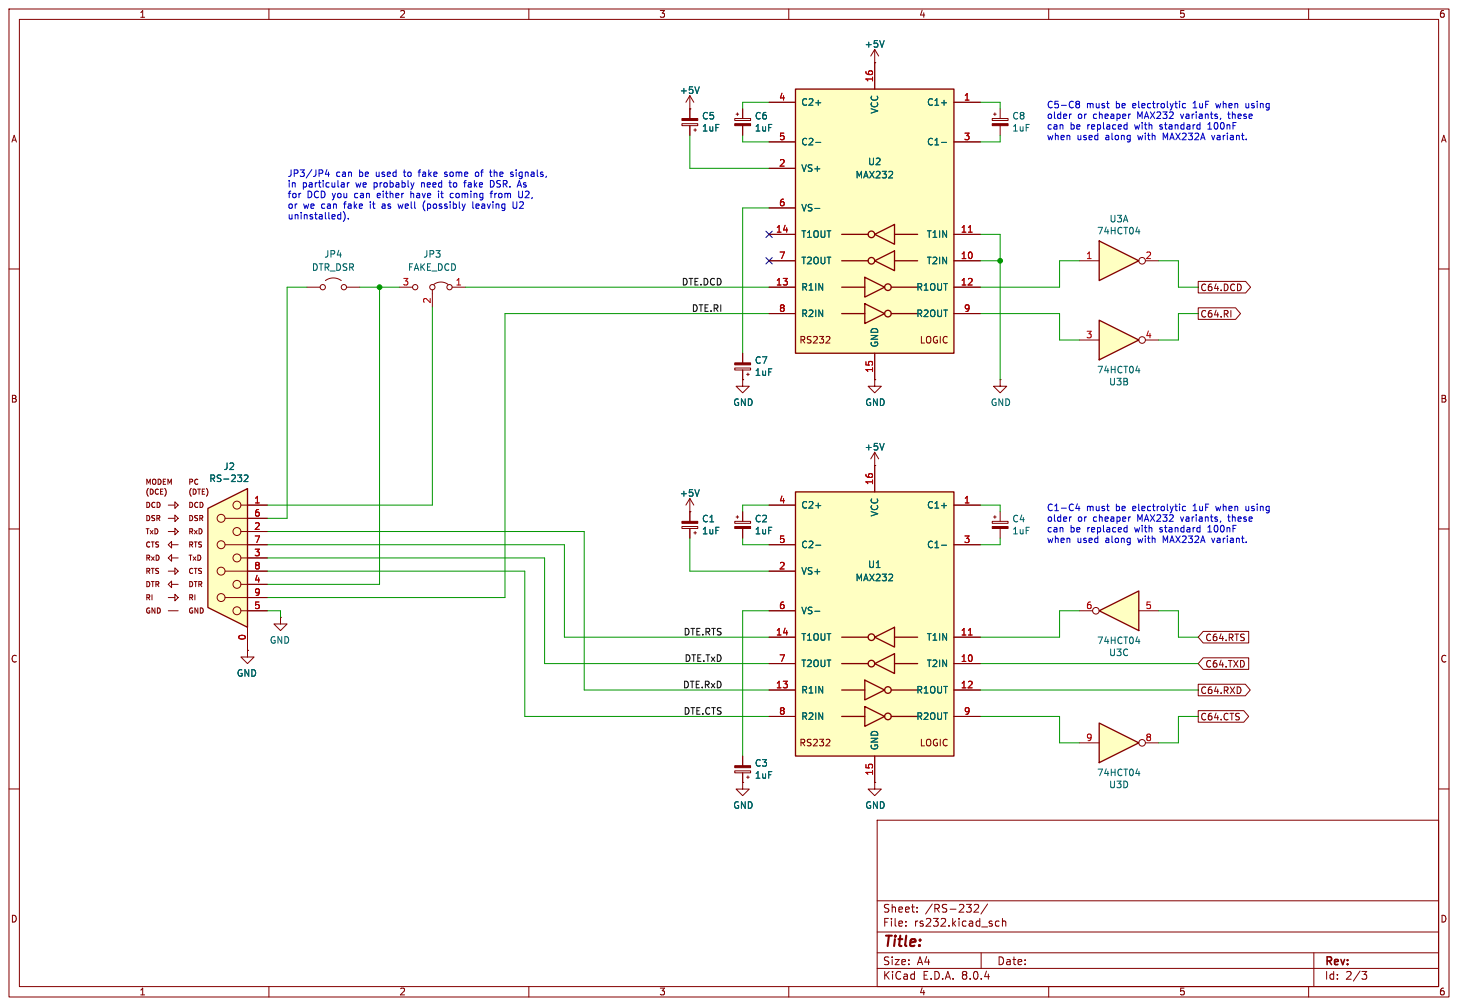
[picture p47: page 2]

DTE.DCD
DTE.RI DTE.CTS DTE.TxD

DTE.RTS DTE.RxD

Id: 2/3 Title: File: rs232.kicad_sch Sheet: /RS-232/

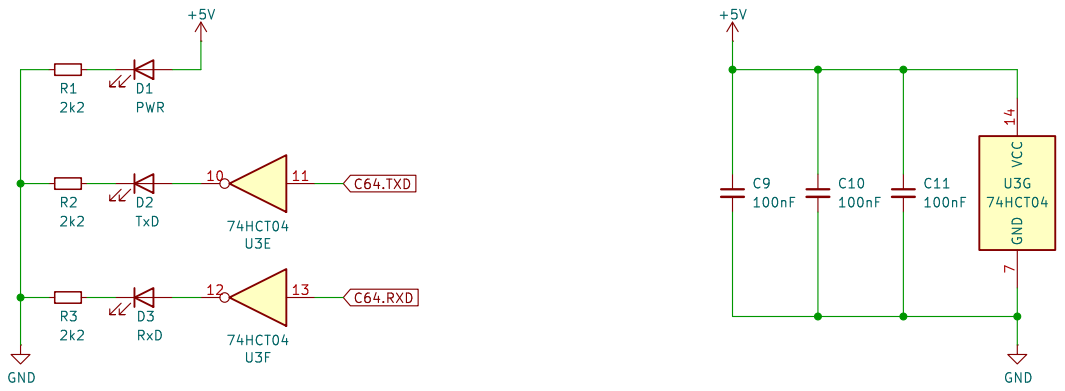
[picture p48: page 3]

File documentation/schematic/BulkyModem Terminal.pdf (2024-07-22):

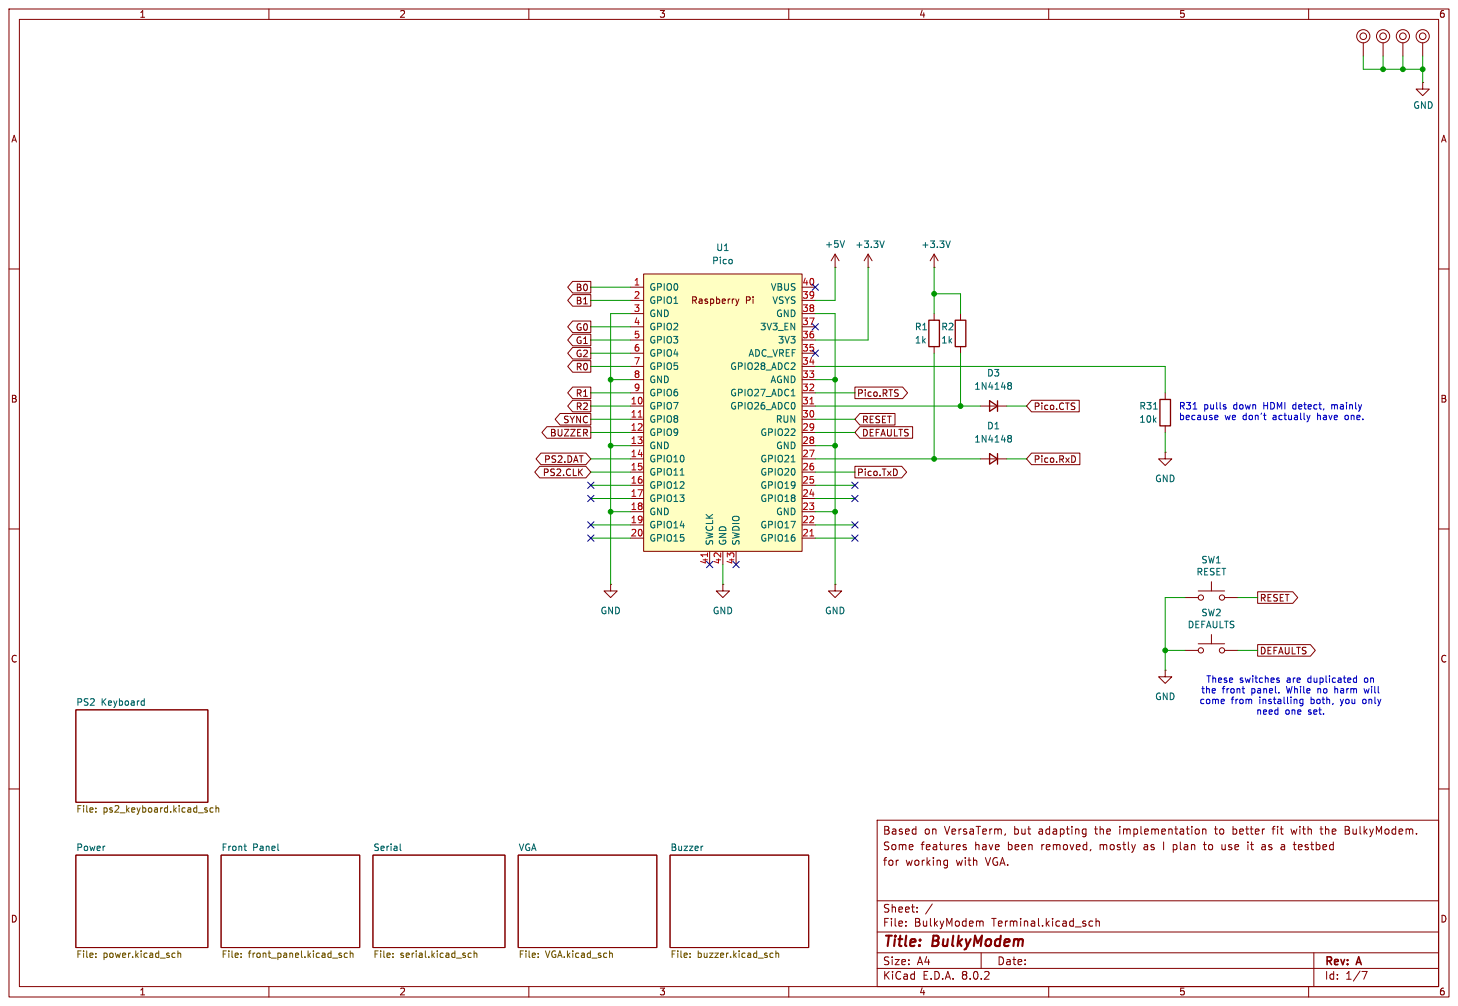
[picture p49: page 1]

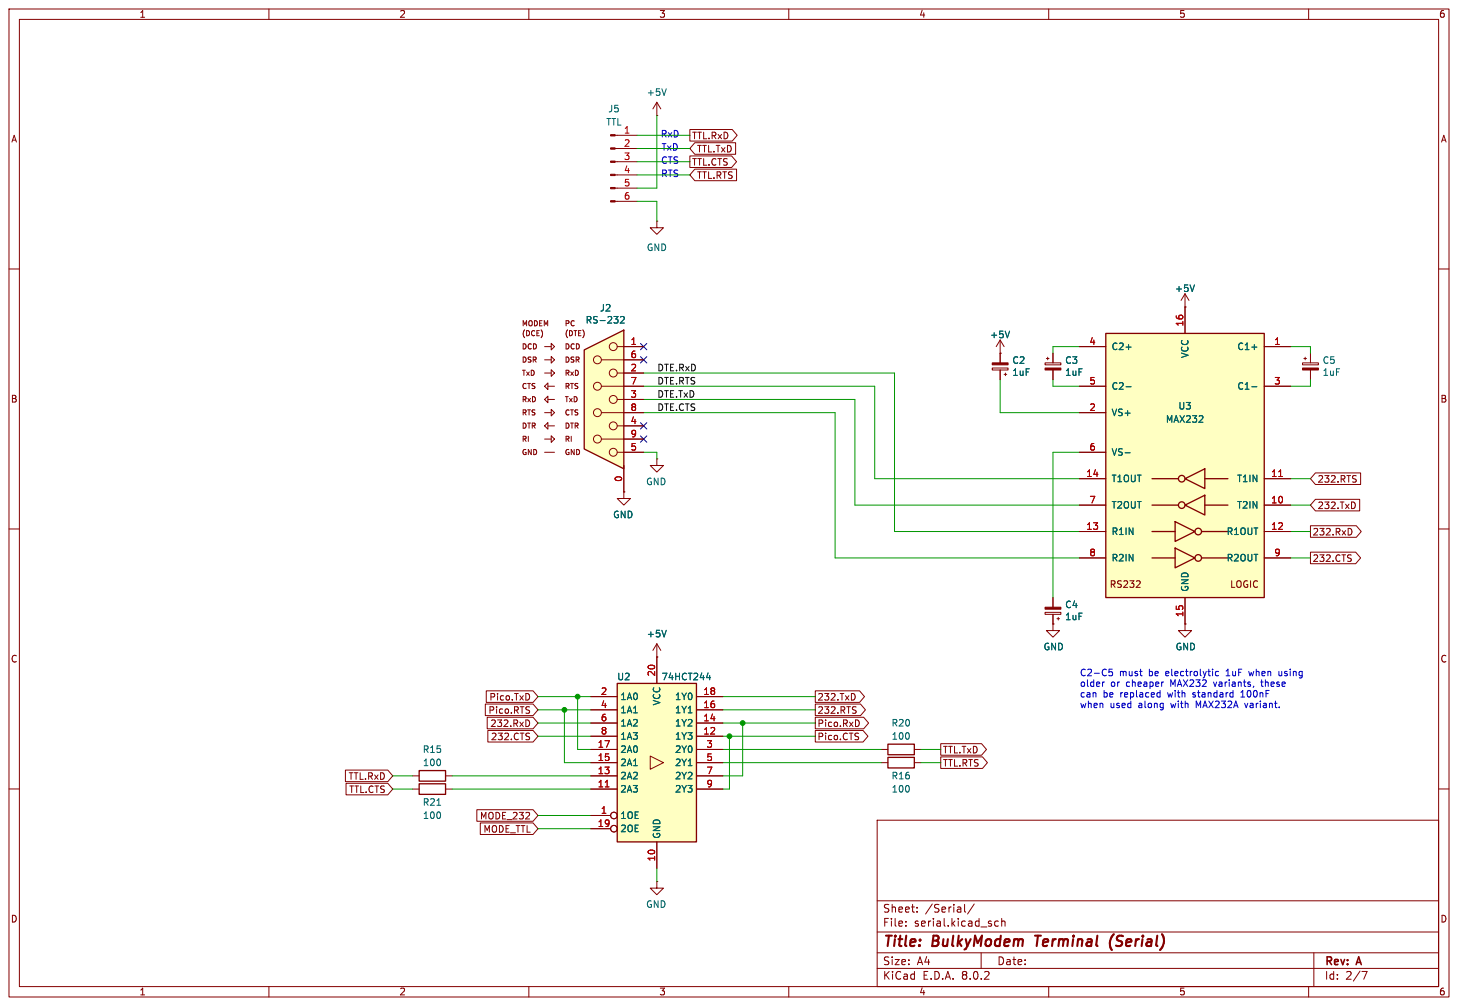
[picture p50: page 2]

DTE.RxD
1uF GND
DTE.CTS DTE.TxD


front panel. It's dumb. I know. Device is powered when either JP1 is linked, or power is instead

coming in via the power switch on
front panel. Note that 3.3v is

The second 5V LED (D10) is on the

Id: 3/7 Title: BulkyModem Module (Power) File: power.kicad_sch Sheet: /Power/


LED.POW

LED.CTS LED.TTL



Id: 6/7 Title: File: buzzer.kicad_sch Sheet: /Buzzer/


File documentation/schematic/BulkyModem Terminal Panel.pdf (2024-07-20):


LED.TX LED.CTS

LED{5V TTL 232 TX RX RTS CTS} LED.RTS

LED.TTL LED.TX

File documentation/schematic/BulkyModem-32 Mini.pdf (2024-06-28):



for obvious reasons. Some computers
require an active DCD to enable


9 U6C 74HCT32 The Mini boards are powered from USB, so there's not much interesting to


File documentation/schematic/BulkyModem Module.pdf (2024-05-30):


to set GPIO0 low after boot. This in
order to filter out data sent by ESP


Jumpers allow the pins to be swapped, this should

Id: 2/6 Title: BulkyModem Module (RS-232) File: rs232.kicad_sch Sheet: /RS-232/ C4
INV_CTS GND


Id: 3/6 Title: BulkyModem Module (Power) File: power.kicad_sch Sheet: /Power/ VCC 14 GND


Id: 4/6 Title: BulkyModem Module (C64 UserPort) File: c64_userport.kicad_sch Sheet: /C64 UserPort/



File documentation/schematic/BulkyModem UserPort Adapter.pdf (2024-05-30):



adapter is powered from at least one source
of power. We don't really care where the little
bit of current is coming from, just need enough

so that the current stored up in it has somewhere

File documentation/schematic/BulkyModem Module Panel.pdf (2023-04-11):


the idea is that when it is on
standby then the LED is dimmed.
Link JP1 and skip remaining to
skip this questionable "feature".
VSB

I don't know how reliable these are when used as power switches, so the load is distributed through

value when not properly engaged.

File: BulkyModem Module Panel.sch Sheet: / Front panel for mounting LEDs horizontally, designed for slotting into the main module.

Id: 1/1 Title: BulkyModem (Panel)





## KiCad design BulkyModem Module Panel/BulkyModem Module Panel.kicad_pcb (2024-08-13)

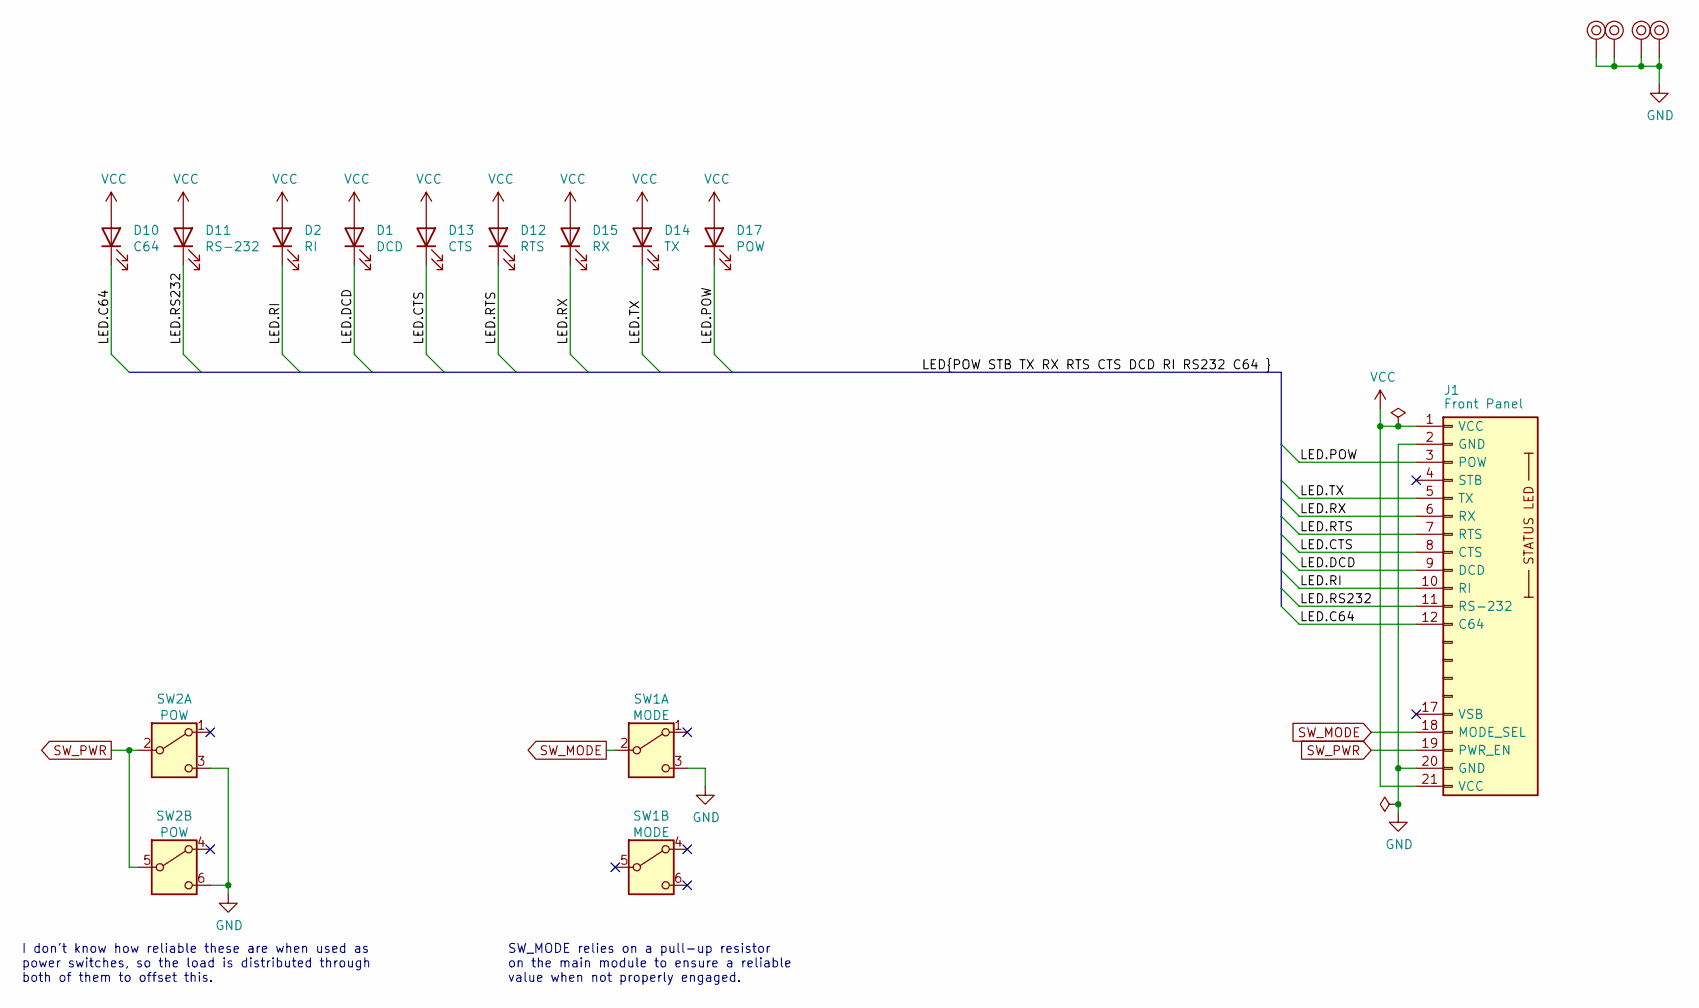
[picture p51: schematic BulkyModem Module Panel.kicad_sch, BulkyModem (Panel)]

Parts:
D1: DCD; LED_D5.0mm
D2: RI; LED_D5.0mm
D10: C64; LED_D5.0mm
D11: RS-232; LED_D5.0mm
D12: RTS; LED_D5.0mm
D13: CTS; LED_D5.0mm
D14: TX; LED_D5.0mm
D15: RX; LED_D5.0mm
D17: POW; LED_D5.0mm
J1: Front Panel; PinHeader_1x21_P2.54mm_Horizontal
M1, M2, M3, M4: Mounting_Pin; M3_pin
SW1: MODE; dpdt_switch_black
SW2: POW; dpdt_switch_black

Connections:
/LED.C64: D10.1 (K), J1.12 (C64)
/LED.CTS: D13.1 (K), J1.8 (CTS)
/LED.DCD: D1.1 (K), J1.9 (DCD)
/LED.POW: D17.1 (K), J1.3 (POW)
/LED.RI: D2.1 (K), J1.10 (RI)
/LED.RS232: D11.1 (K), J1.11 (RS-232)
/LED.RTS: D12.1 (K), J1.7 (RTS)
/LED.RX: D15.1 (K), J1.6 (RX)
/LED.TX: D14.1 (K), J1.5 (TX)
GND: J1.2 (GND), J1.20 (GND), M1.1, M2.1, M3.1, M4.1, SW1.3 (C), SW2.3 (C), SW2.6 (C)
SW_MODE: J1.18 (MODE_SEL), SW1.2 (B)
SW_PWR: J1.19 (PWR_EN), SW2.2 (B), SW2.5 (B)
VCC: D1.2 (A), D2.2 (A), D10.2 (A), D11.2 (A), D12.2 (A), D13.2 (A), D14.2 (A), D15.2 (A), D17.2 (A), J1.1 (VCC), J1.21 (VCC)

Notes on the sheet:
SW_MODE relies on a pull-up resistor on the main module to ensure a reliable value when not properly engaged.
I don't know how reliable these are when used as power switches, so the load is distributed through both of them to offset this.

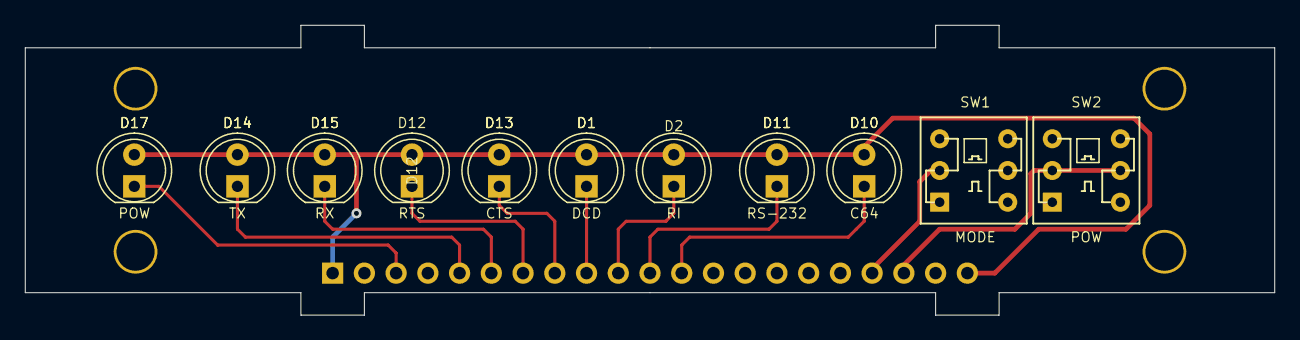
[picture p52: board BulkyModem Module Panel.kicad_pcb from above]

Board: 2 copper layers, 100.0 x 23.2 mm, 16 parts (1 on the bottom side), 13 nets.

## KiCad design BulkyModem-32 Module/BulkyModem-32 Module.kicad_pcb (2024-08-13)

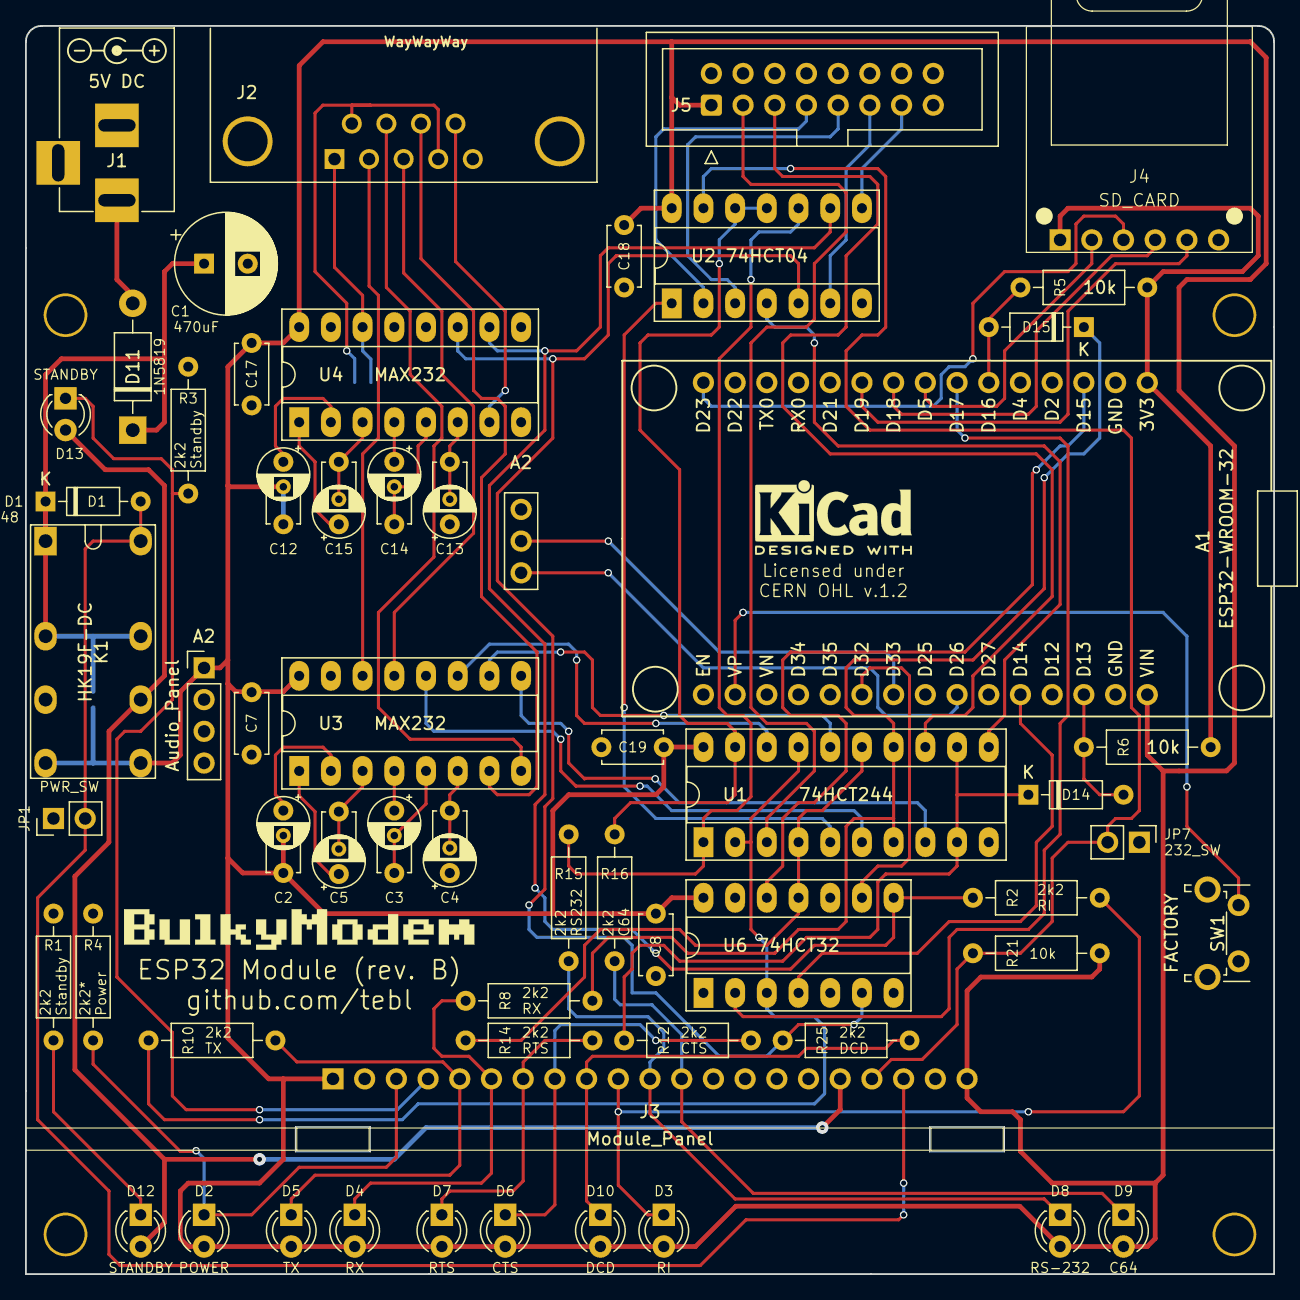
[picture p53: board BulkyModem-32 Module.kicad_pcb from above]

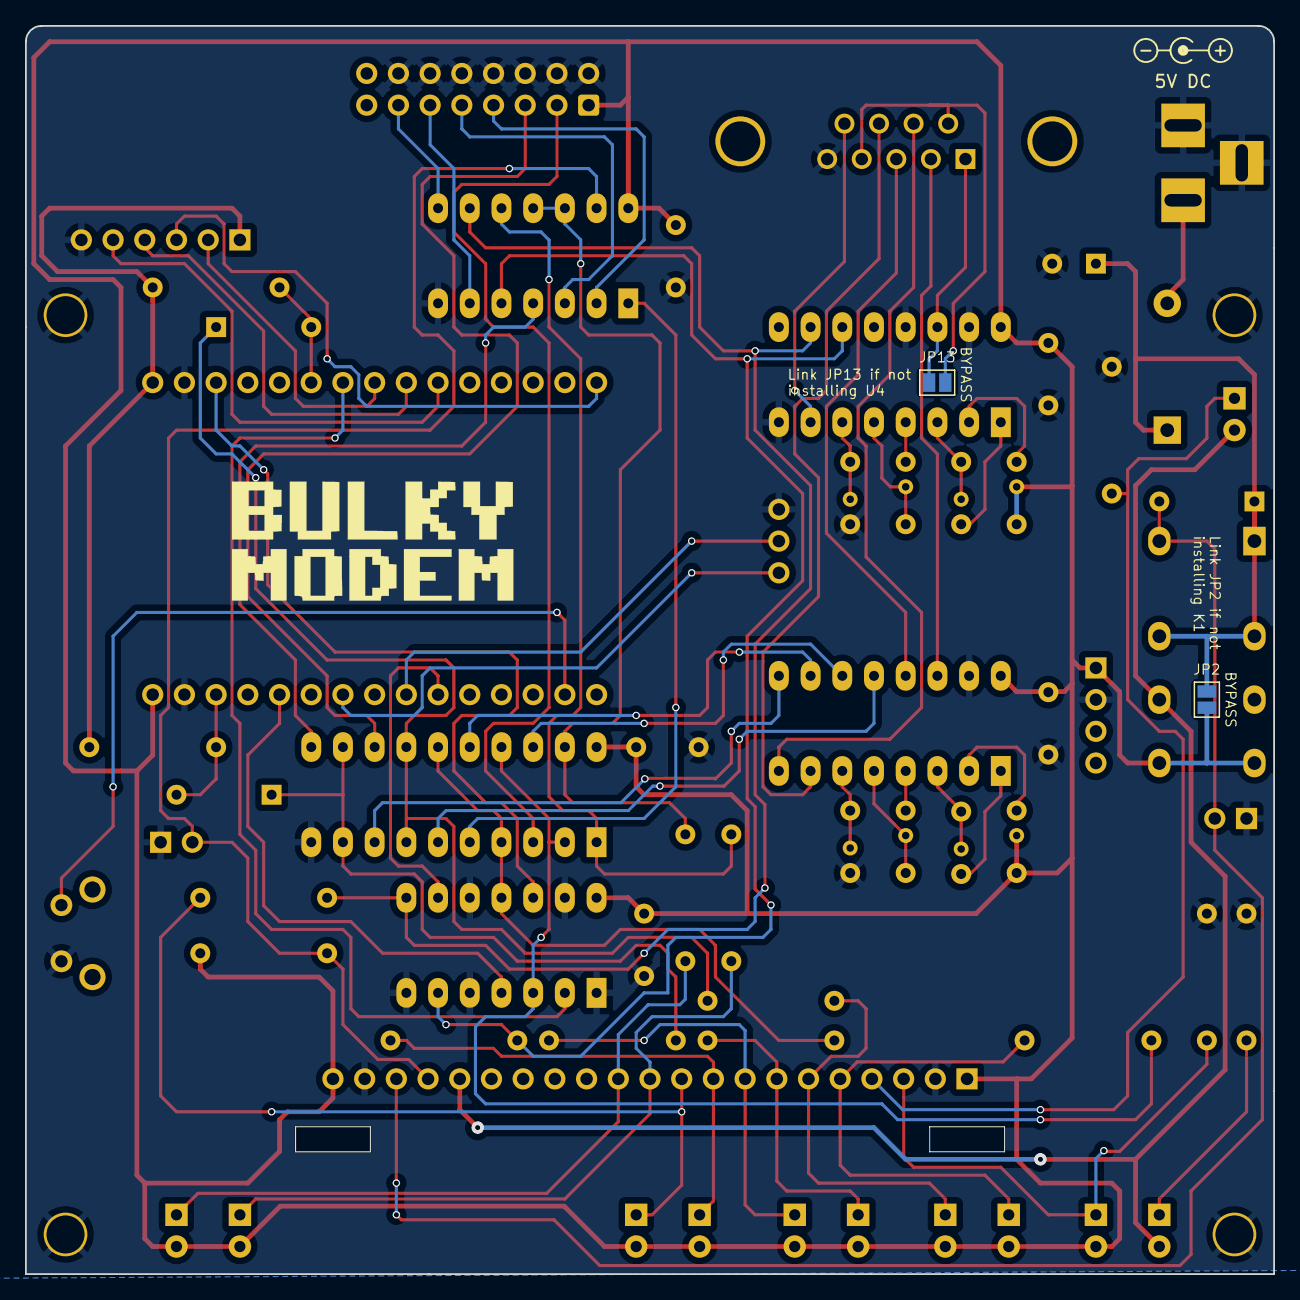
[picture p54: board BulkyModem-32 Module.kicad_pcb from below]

Board: 2 copper layers, 100.0 x 100.0 mm, 66 parts (2 on the bottom side), 61 nets.

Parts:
A1: ESP32-WROOM-32; ESP32-WROOM-32D_30
A2: Audio_Panel; AudioModule
C1: 470uF; CP_Radial_D8.0mm_P3.50mm
C2, C3, C4, C5, C12, C13, C14, C15: 1uF; CP_Radial_D4.0mm_P2.00mm_Custom
C7, C8, C17, C18, C19: 100nF; C_Disc_D4.7mm_W2.5mm_P5.00mm
D1, D14, D15: 1N4148; D_DO-35_SOD27_P7.62mm_Horizontal
D2: POWER; LED_D3.0mm
D3: RI; LED_D3.0mm
D4: RX; LED_D3.0mm
D5: TX; LED_D3.0mm
D6: CTS; LED_D3.0mm
D7: RTS; LED_D3.0mm
D8: RS-232; LED_D3.0mm
D9: C64; LED_D3.0mm
D10: DCD; LED_D3.0mm
D11: 1N5819; D_DO-41_SOD81_P10.16mm_Horizontal
D12, D13: STANDBY; LED_D3.0mm
J1: DC IN; BARREL_JACK
J2: DCE; DSUB-9_Female_Horizontal_P2.77x2.84mm_EdgePinOffset7.70mm_H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
J3: Module_Panel
J4: SD_CARD; ESP32_SD_Module
J5: C64_Modem_OUT; UserPort_Adapter_IDC
JP1: PWR_SW; PinHeader_1x02_P2.54mm_Vertical
JP2, JP13: BYPASS; SolderJumper-2_P1.3mm_Open_Pad1.0x1.5mm
JP7: 232_SW; PinHeader_1x02_P2.54mm_Vertical
K1: HK19F-DC
M1, M2, M3, M4: Mounting; M3_pin
R1, R2, R3, R8, R10, R12, R14, R15, R16, R25: 2k2; R_Axial_DIN0207_L6.3mm_D2.5mm_P10.16mm_Horizontal
R4: 2k2*; R_Axial_DIN0207_L6.3mm_D2.5mm_P10.16mm_Horizontal
R5, R6, R21: 10k; R_Axial_DIN0207_L6.3mm_D2.5mm_P10.16mm_Horizontal
SW1: FACTORY; SW_Tactile_SPST_Angled_PTS645Vx39-2LFS
SYM1: DC_5V; PWR_Specification
U1: 74HCT244; DIP-20_W7.62mm_Socket_LongPads
U2: 74HCT04; DIP-14_W7.62mm_Socket_LongPads
U3, U4: MAX232; DIP-16_W7.62mm_Socket_LongPads
U6: 74HCT32; DIP-14_W7.62mm_Socket_LongPads

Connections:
+3.3V: A1.16 (3.3V), J4.1, R5.1, R6.1
+5V: A1.15 (VIN), A2.1 (VCC), C2.2, C7.1, C8.1, C12.2, C17.1, C18.1, C19.1, D2.2 (A), D3.2 (A), D4.2 (A), D5.2 (A), D6.2 (A), D7.2 (A), D8.2 (A), D9.2 (A), D10.2 (A), J3.1 (VCC), J3.21 (VCC), J5.1 (VCC), JP2.2 (B), K1.8 (NO_1), K1.9 (NO_2), R21.2, U1.20 (VCC), U2.14 (VCC), U3.16 (VCC), U4.16 (VCC), U6.14 (VCC)
/232_CTS: U1.8 (1A3), U3.9 (R2OUT)
/232_RTS: U1.16 (1Y1), U3.10 (T2IN)
/232_RX: U1.6 (1A2), U3.12 (R1OUT)
/232_TX: U1.18 (1Y0), U3.11 (T1IN)
/C64_CTS: U1.11 (2A3), U2.4
/C64_RTS: U1.5 (2Y1), U2.1
/C64_RX: J5.3 (RX), U1.13 (2A2)
/C64_TX: J5.2 (TX), U1.3 (2Y0)
/Front Panel/LED_C64: D9.1 (K), J3.12 (C64), R16.2
/Front Panel/LED_CTS: D6.1 (K), J3.8 (CTS), R12.2
/Front Panel/LED_DCD: D10.1 (K), J3.9 (DCD), R25.2
/Front Panel/LED_POW: D2.1 (K), J3.3 (POW), R4.2
/Front Panel/LED_RI: D3.1 (K), J3.10 (RI), R2.2
/Front Panel/LED_RS232: D8.1 (K), J3.11 (RS-232), R15.2
/Front Panel/LED_RTS: D7.1 (K), J3.7 (RTS), R14.2
/Front Panel/LED_RX: D4.1 (K), J3.6 (RX), R8.2
/Front Panel/LED_STB: D13.1 (K), J3.4 (STB), R3.2
/Front Panel/LED_TX: D5.1 (K), J3.5 (TX), R10.2
/RS-232/SER_CTS: J2.7, U3.8 (R2IN)
/RS-232/SER_DCD: J2.1, JP13.1 (A), U4.14 (T1OUT)
/RS-232/SER_RI: J2.9, U4.7 (T2OUT)
/RS-232/SER_RTS: J2.8, U3.7 (T2OUT)
/RS-232/SER_RxD: J2.3, U3.13 (R1IN)
/RS-232/SER_TxD: J2.2, U3.14 (T1OUT)
AUDIO_RX: A1.9 (D26), A2.5 (AUDIO_TX)
AUDIO_TX: A1.7 (D33), A2.6 (AUDIO_RX)
ESP_CTS: D14.1 (K), R12.1, U1.9 (2Y3), U1.12 (1Y3)
ESP_DCD: R25.1, U2.5, U4.11 (T1IN), U6.6
ESP_RI: R2.1, U2.9, U4.10 (T2IN), U6.8
ESP_RTS: R14.1, U1.4 (1A1), U1.15 (2A1), U6.11
ESP_RX: D15.1 (K), R8.1, U1.7 (2Y2), U1.14 (1Y2)
ESP_TX: R10.1, U1.2 (1A0), U1.17 (2A0), U6.3
GND: A1.14 (GND), A1.17 (GND), A2.2 (GND), A2.7 (GND), C1.2, C4.1, C7.2, C8.2, C13.1, C17.2, C18.2, C19.2, J1.2, J1.3, J2.5, J3.2 (GND), J3.20 (GND), J4.6, J5.9 (GND), J5.10 (GND), J5.11 (GND), J5.12 (GND), J5.13 (GND), J5.14 (GND), J5.15 (GND), JP1.1 (A), JP7.1 (A), M1.1, M2.1, M3.1, M4.1, R1.1, R3.1, R4.1, SW1.2, U1.10 (GND), U2.7 (GND), U3.15 (GND), U4.8 (R2IN), U4.13 (R1IN), U4.15 (GND), U6.1, U6.5, U6.7 (GND), U6.10, U6.13
MODE_232: R15.1, U1.1 (1OE), U2.10
MODE_C64: R16.1, U1.19 (2OE), U2.11, U2.12
MODE_SEL: J3.18 (MODE_SEL), JP7.2 (B), R21.1, U2.13
unnamed: A1.13 (D13), D14.2 (A), R6.2
unnamed: A1.11 (D14), U6.4
unnamed: A1.18 (D15), U6.12
unnamed: A1.21 (D16), D15.2 (A), R5.2
unnamed: A1.22 (D17), U6.2
unnamed: A1.6 (D32), U6.9
unnamed: A1.2 (VP), SW1.1
unnamed: D11.2 (A), J1.1
unnamed: D12.1 (K), R1.2
unnamed: J5.5 (CTS), U2.3
unnamed: J5.6 (DCD), U2.6
unnamed: J5.7 (RI), U2.8
unnamed: J5.4 (RTS), U2.2
unnamed: J2.4, J2.6, JP13.2 (B)
unnamed: C12.1, U4.2 (VS+)
unnamed: C13.2, U4.6 (VS-)
PWR_EN: D1.2 (A), J3.19 (PWR_EN), JP1.2 (B), K1.16
SPI_CLK: A1.24 (D18), J4.4
SPI_CS: A1.23 (D5), J4.2
SPI_MISO: A1.25 (D19), J4.5
SPI_MOSI: A1.30 (D23), J4.3
VIN: C1.1, D1.1 (K), D11.1 (K), JP2.1 (A), K1.1, K1.4 (COM_1), K1.13 (COM_2)
VSB: D12.2 (A), D13.2 (A), J3.17 (VSB), K1.11 (NC_2)

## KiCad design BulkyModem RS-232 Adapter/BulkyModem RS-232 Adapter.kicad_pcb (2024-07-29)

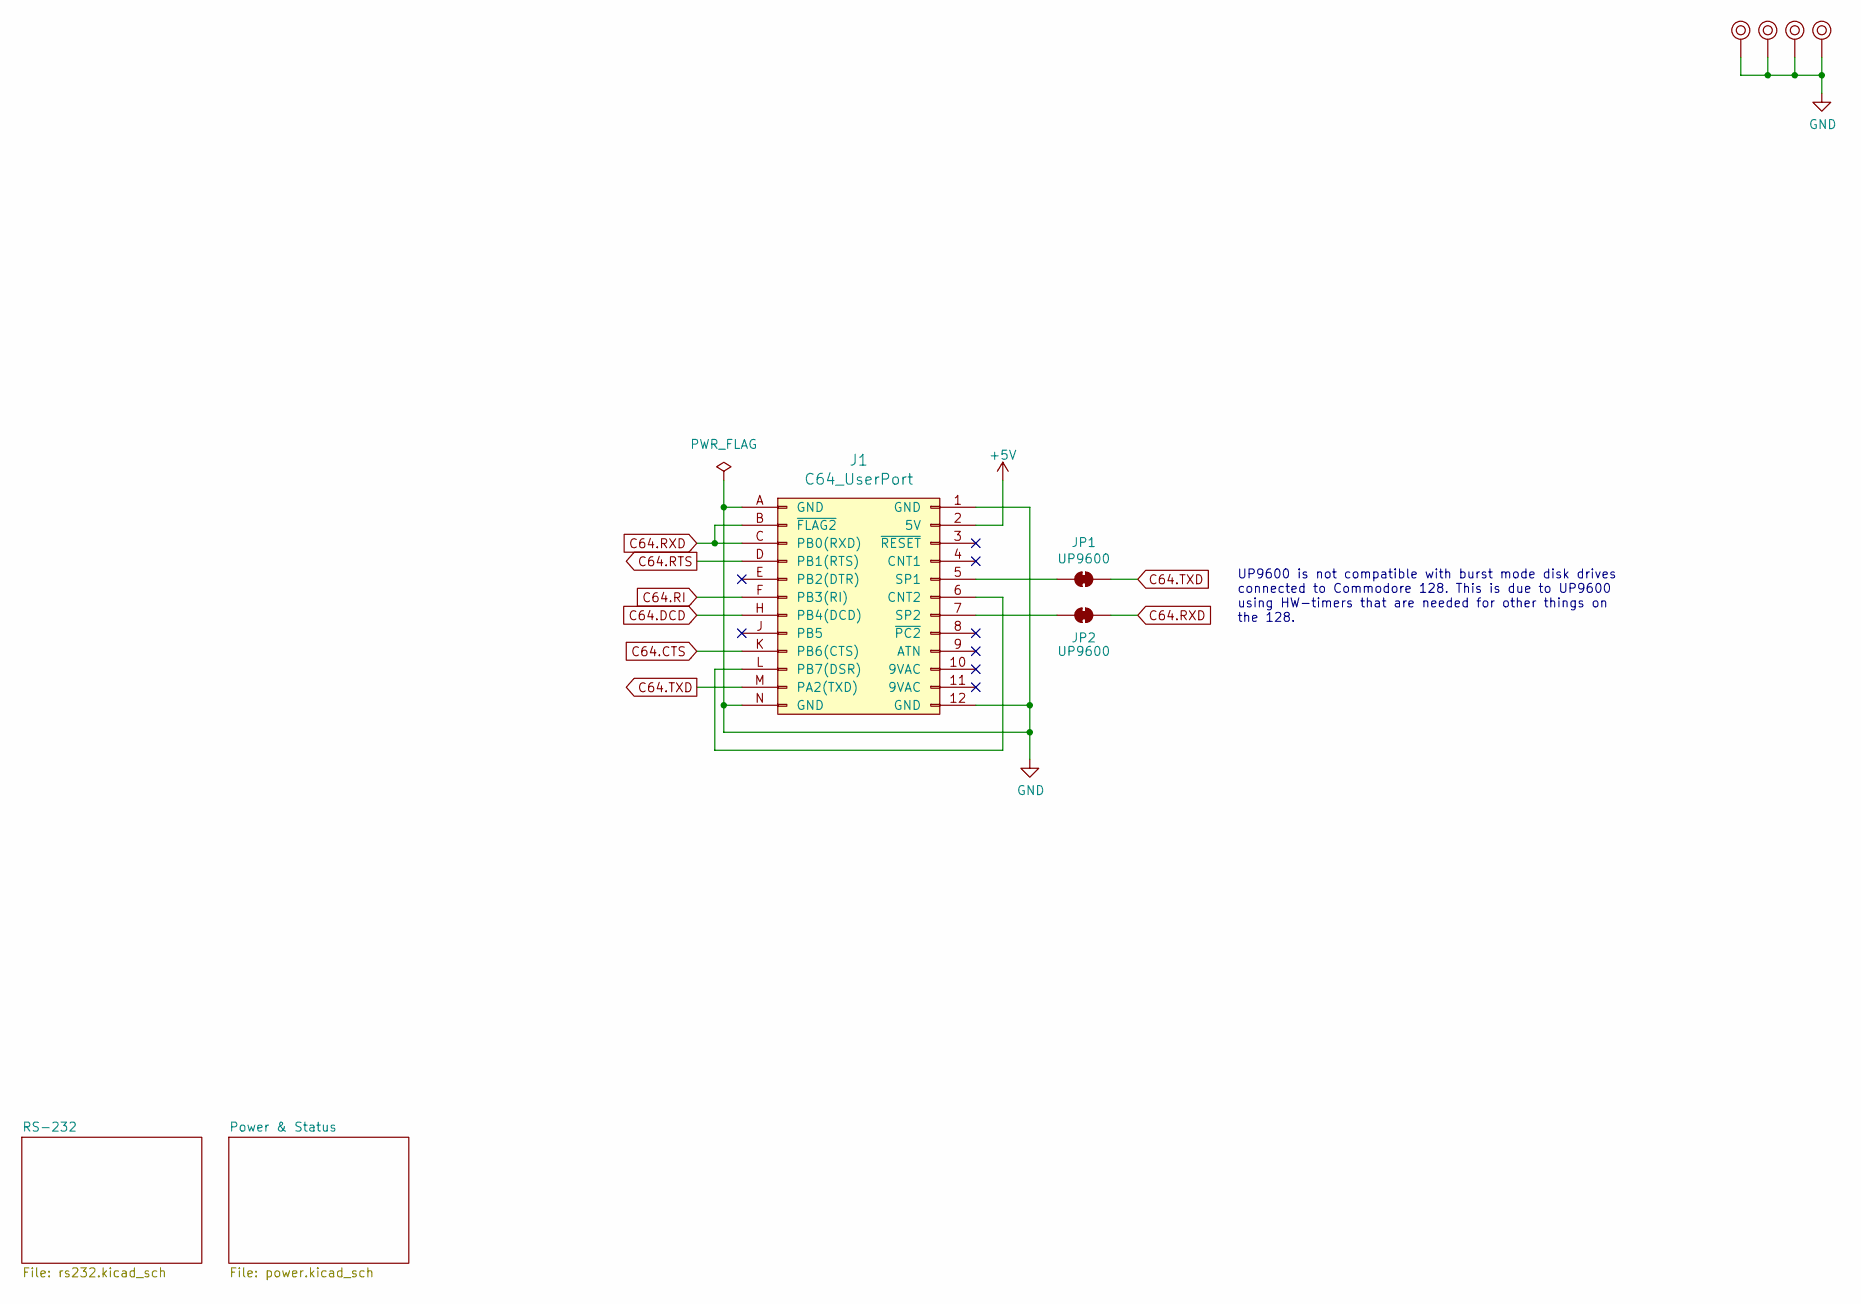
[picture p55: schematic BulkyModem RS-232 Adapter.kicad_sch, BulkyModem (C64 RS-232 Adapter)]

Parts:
J1: C64_UserPort; C64_User-Port
JP1, JP2: UP9600; PinHeader_1x02_P2.54mm_Vertical
M1, M2, M3, M4: Mounting; M3_pin

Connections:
+5V: J1.2 (5V); also elsewhere on the board
C64.CTS: J1.K (PB6(CTS)); also elsewhere on the board
C64.DCD: J1.H (PB4(DCD)); also elsewhere on the board
C64.RI: J1.F (PB3(RI)); also elsewhere on the board
C64.RTS: J1.D (PB1(RTS)); also elsewhere on the board
C64.RXD: J1.B (~FLAG2), J1.C (PB0(RXD)), JP2.2 (B); also elsewhere on the board
C64.TXD: J1.M (PA2(TXD)), JP1.2 (B); also elsewhere on the board
GND: J1.1 (GND), J1.12 (GND), J1.A (GND), J1.N (GND), M1.1, M2.1, M3.1, M4.1; also elsewhere on the board
unnamed: J1.6 (CNT2), J1.L (PB7(DSR))
unnamed: J1.5 (SP1), JP1.1 (A)
unnamed: J1.7 (SP2), JP2.1 (A)

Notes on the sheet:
UP9600 is not compatible with burst mode disk drives connected to Commodore 128. This is due to UP9600 using HW-timers that are needed for other things on the 128.

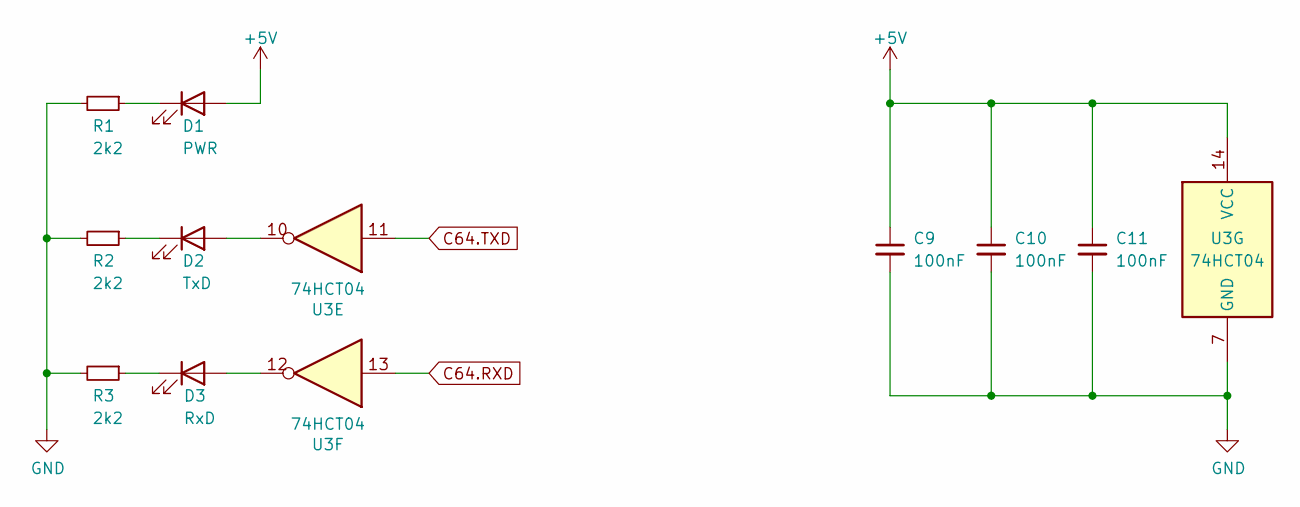
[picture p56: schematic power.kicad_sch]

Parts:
C9, C10, C11: 100nF; C_Disc_D4.7mm_W2.5mm_P5.00mm
D1: PWR; LED_D3.0mm
D2: TxD; LED_D3.0mm
D3: RxD; LED_D3.0mm
R1, R2, R3: 2k2; R_Axial_DIN0207_L6.3mm_D2.5mm_P10.16mm_Horizontal
U3: 74HCT04; DIP-14_W7.62mm_Socket_LongPads

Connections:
+5V: C9.1, C10.1, C11.1, D1.2 (A), U3.14 (VCC); also elsewhere on the board
C64.RXD: U3.13; also elsewhere on the board
C64.TXD: U3.11; also elsewhere on the board
GND: C9.2, C10.2, C11.2, R1.2, R2.2, R3.2, U3.7 (GND); also elsewhere on the board
unnamed: D1.1 (K), R1.1
unnamed: D2.2 (A), U3.10
unnamed: D2.1 (K), R2.1
unnamed: D3.2 (A), U3.12
unnamed: D3.1 (K), R3.1

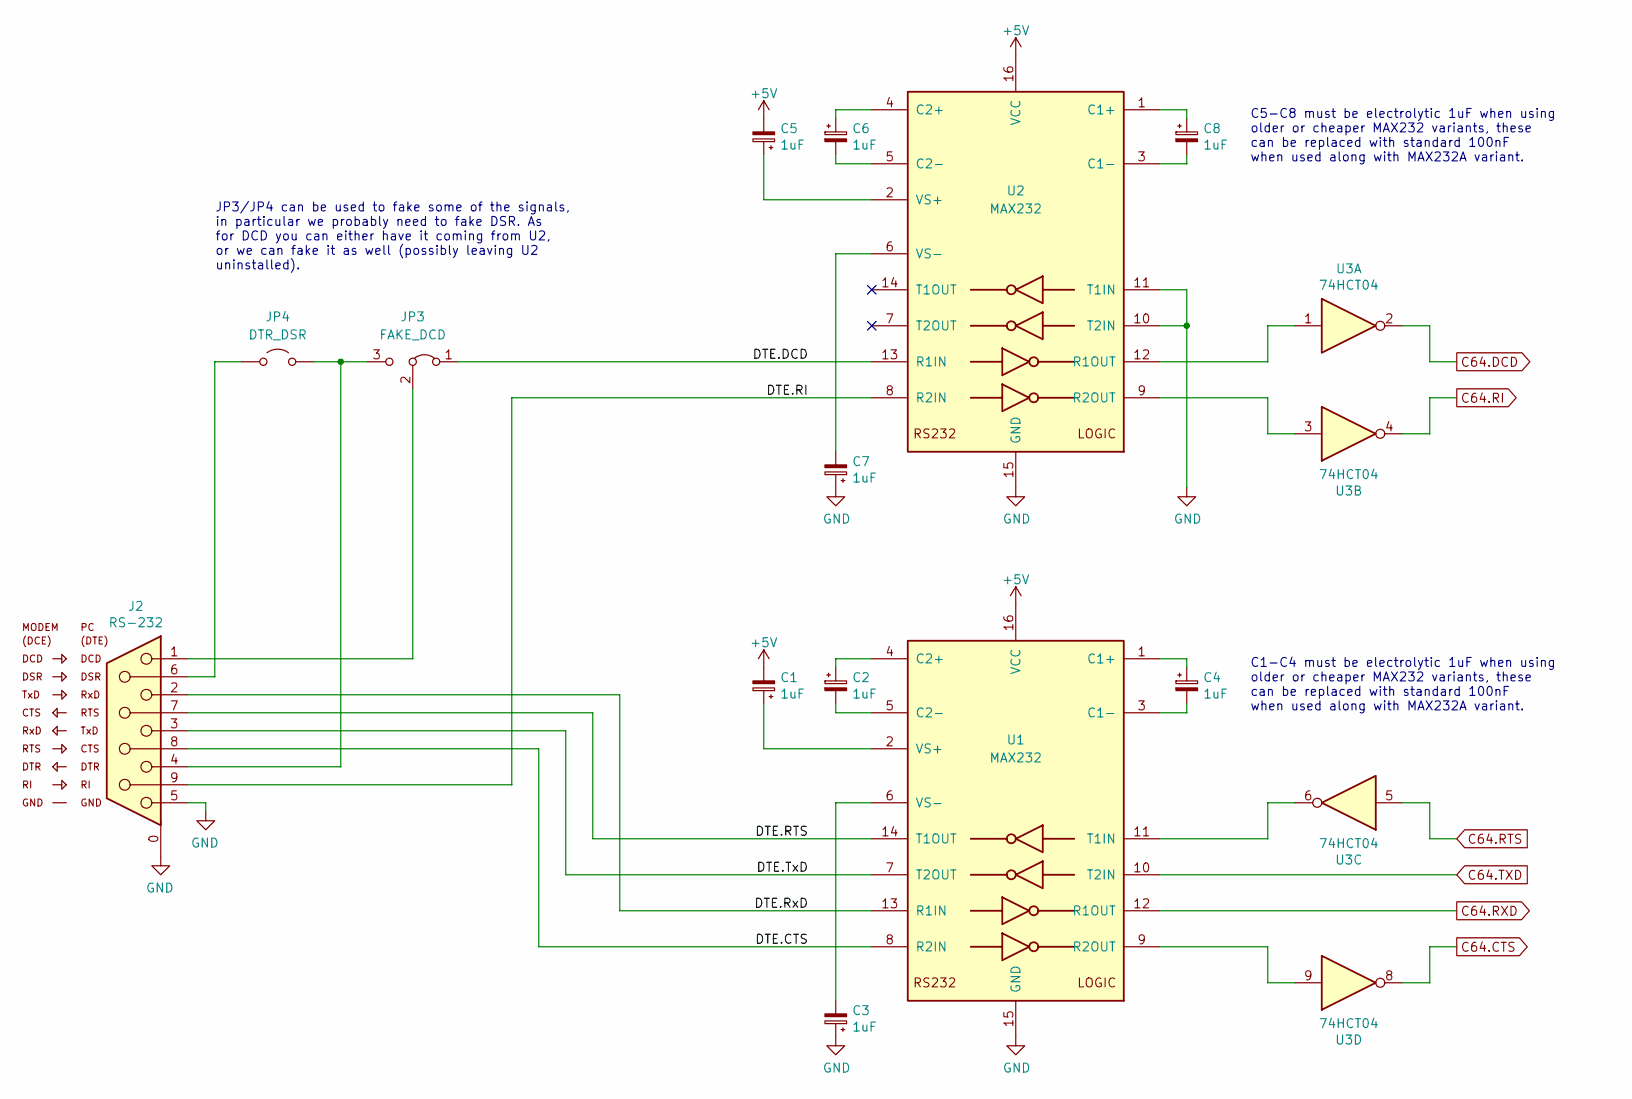
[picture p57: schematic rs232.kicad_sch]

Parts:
C1, C2, C3, C4, C5, C6, C7, C8: 1uF; CP_Radial_D4.0mm_P2.00mm_Custom
J2: RS-232; DSUB-9_Male_Horizontal_P2.77x2.84mm_EdgePinOffset7.70mm_Hou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
JP3: FAKE_DCD; PinHeader_1x03_P2.54mm_Vertical
JP4: DTR_DSR; PinHeader_1x02_P2.54mm_Vertical
U1, U2: MAX232; DIP-16_W7.62mm_Socket_LongPads
U3: 74HCT04; DIP-14_W7.62mm_Socket_LongPads

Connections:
+5V: C1.2, C5.2, U1.16 (VCC), U2.16 (VCC); also elsewhere on the board
/RS-232/DTE.CTS: J2.8, U1.8 (R2IN)
/RS-232/DTE.DCD: JP3.1 (A), U2.13 (R1IN)
/RS-232/DTE.RI: J2.9, U2.8 (R2IN)
/RS-232/DTE.RTS: J2.7, U1.14 (T1OUT)
/RS-232/DTE.RxD: J2.2, U1.13 (R1IN)
/RS-232/DTE.TxD: J2.3, U1.7 (T2OUT)
C64.CTS: U3.8; also elsewhere on the board
C64.DCD: U3.2; also elsewhere on the board
C64.RI: U3.4; also elsewhere on the board
C64.RTS: U3.5; also elsewhere on the board
C64.RXD: U1.12 (R1OUT); also elsewhere on the board
C64.TXD: U1.10 (T2IN); also elsewhere on the board
GND: C3.1, C7.1, J2.0 (S), J2.5, U1.15 (GND), U2.10 (T2IN), U2.11 (T1IN), U2.15 (GND); also elsewhere on the board
unnamed: J2.4, JP3.3 (B), JP4.2 (B)
unnamed: J2.1, JP3.2 (C)
unnamed: J2.6, JP4.1 (A)
unnamed: C4.1, U1.1 (C1+)
unnamed: C4.2, U1.3 (C1-)
unnamed: C2.1, U1.4 (C2+)
unnamed: C2.2, U1.5 (C2-)
unnamed: U1.9 (R2OUT), U3.9
unnamed: U1.11 (T1IN), U3.6
unnamed: C1.1, U1.2 (VS+)
unnamed: C3.2, U1.6 (VS-)
unnamed: C8.1, U2.1 (C1+)
unnamed: C8.2, U2.3 (C1-)
unnamed: C6.1, U2.4 (C2+)
unnamed: C6.2, U2.5 (C2-)
unnamed: U2.12 (R1OUT), U3.1
unnamed: U2.9 (R2OUT), U3.3
unnamed: C5.1, U2.2 (VS+)
unnamed: C7.2, U2.6 (VS-)

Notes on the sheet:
C1-C4 must be electrolytic 1uF when using older or cheaper MAX232 variants, these can be replaced with standard 100nF when used along with MAX232A variant.
C5-C8 must be electrolytic 1uF when using older or cheaper MAX232 variants, these can be replaced with standard 100nF when used along with MAX232A variant.
JP3/JP4 can be used to fake some of the signals, in particular we probably need to fake DSR. As for DCD you can either have it coming from U2, or we can fake it as well (possibly leaving U2 uninstalled).

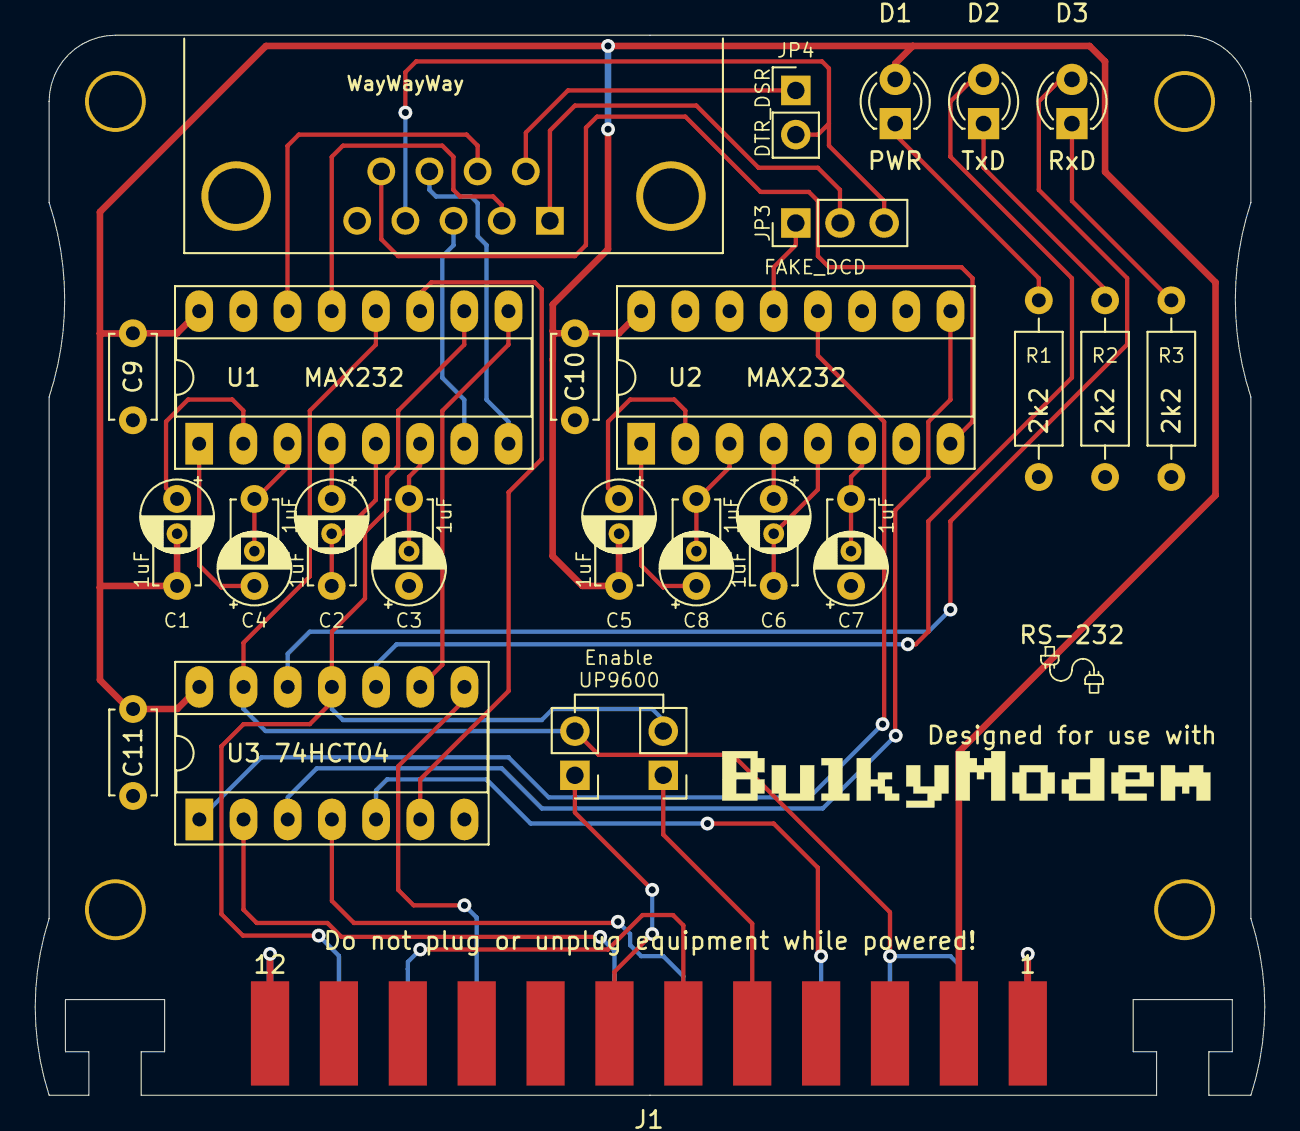
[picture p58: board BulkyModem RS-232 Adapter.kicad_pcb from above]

Board: 2 copper layers, 70.7 x 60.9 mm, 30 parts (0 on the bottom side), 41 nets.

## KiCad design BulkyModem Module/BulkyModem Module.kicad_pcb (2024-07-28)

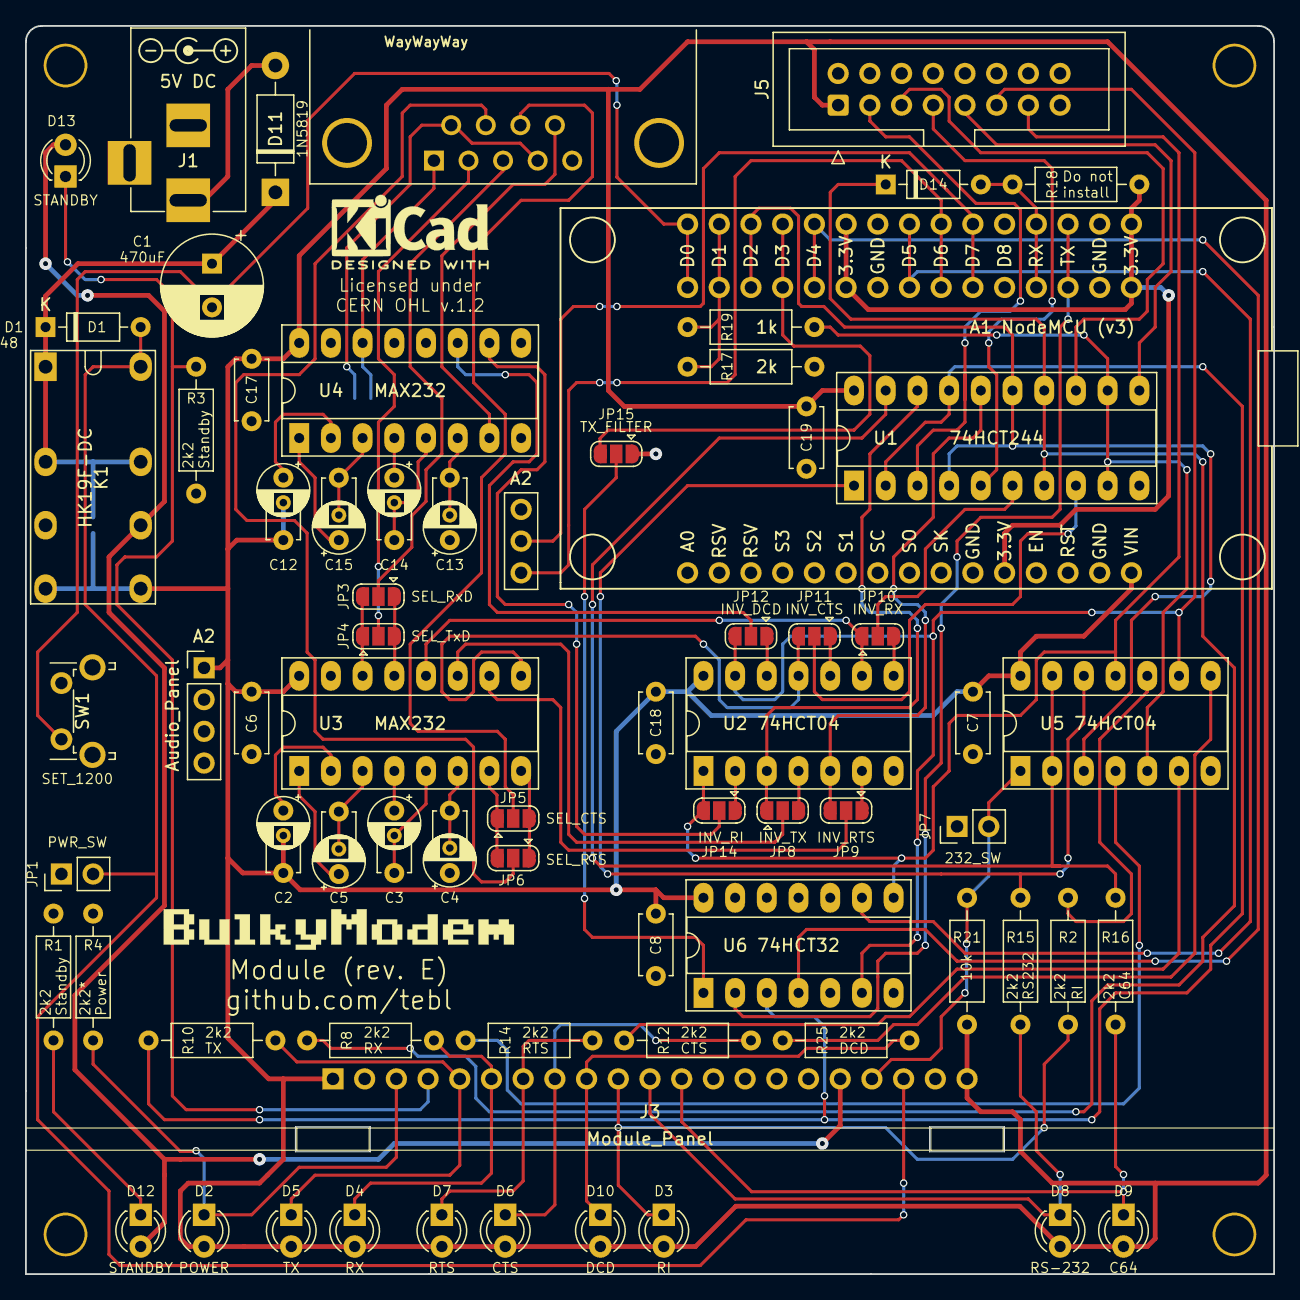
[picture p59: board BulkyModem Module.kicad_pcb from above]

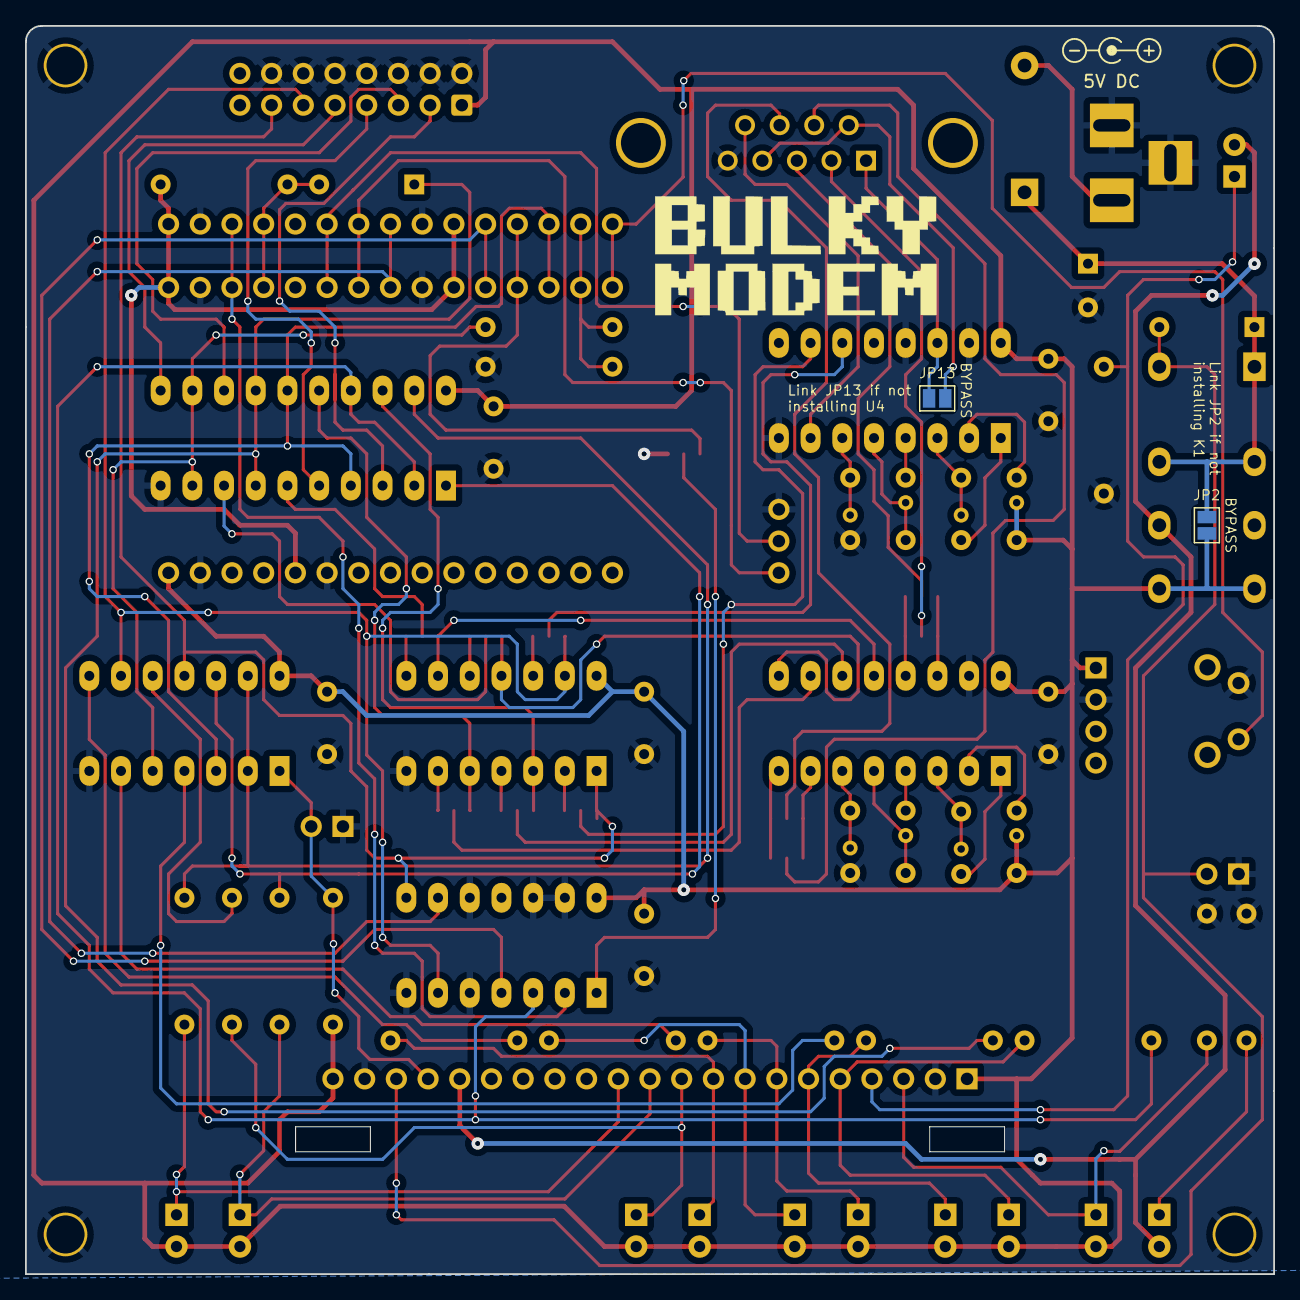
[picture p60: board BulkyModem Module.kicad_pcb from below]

Board: 2 copper layers, 100.0 x 100.0 mm, 78 parts (2 on the bottom side), 70 nets.

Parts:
A1: NodeMCU (v3); NodeMCU-LoLinV3
A2: Audio_Panel; AudioModule
C1: 470uF; CP_Radial_D8.0mm_P3.50mm
C2, C3, C4, C5, C12, C13, C14, C15: 1uF; CP_Radial_D4.0mm_P2.00mm_Custom
C6, C7, C8, C17, C18, C19: 100nF; C_Disc_D4.7mm_W2.5mm_P5.00mm
D1: 1n4148; D_DO-35_SOD27_P7.62mm_Horizontal
D2: POWER; LED_D3.0mm
D3: RI; LED_D3.0mm
D4: RX; LED_D3.0mm
D5: TX; LED_D3.0mm
D6: CTS; LED_D3.0mm
D7: RTS; LED_D3.0mm
D8: RS-232; LED_D3.0mm
D9: C64; LED_D3.0mm
D10: DCD; LED_D3.0mm
D11: 1N5819; D_DO-41_SOD81_P10.16mm_Horizontal
D12, D13: STANDBY; LED_D3.0mm
D14: 1N4148; D_DO-35_SOD27_P7.62mm_Horizontal
J1: DC IN; BARREL_JACK
J2: DCE; DSUB-9_Female_Horizontal_P2.77x2.84mm_EdgePinOffset7.70mm_H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
J3: Module_Panel
J5: C64_Modem_OUT; UserPort_Adapter_IDC
JP1: PWR_SW; PinHeader_1x02_P2.54mm_Vertical
JP2, JP13: BYPASS; SolderJumper-2_P1.3mm_Open_Pad1.0x1.5mm
JP3: SEL_RxD; SolderJumper-3_P1.3mm_Open_RoundedPad1.0x1.5mm
JP4: SEL_TxD; SolderJumper-3_P1.3mm_Open_RoundedPad1.0x1.5mm
JP5: SEL_CTS; SolderJumper-3_P1.3mm_Open_RoundedPad1.0x1.5mm
JP6: SEL_RTS; SolderJumper-3_P1.3mm_Open_RoundedPad1.0x1.5mm
JP7: 232_SW; PinHeader_1x02_P2.54mm_Vertical
JP8: INV_TX; SolderJumper-3_P1.3mm_Open_RoundedPad1.0x1.5mm
JP9: INV_RTS; SolderJumper-3_P1.3mm_Open_RoundedPad1.0x1.5mm
JP10: INV_RX; SolderJumper-3_P1.3mm_Open_RoundedPad1.0x1.5mm
JP11: INV_CTS; SolderJumper-3_P1.3mm_Open_RoundedPad1.0x1.5mm
JP12: INV_DCD; SolderJumper-3_P1.3mm_Open_RoundedPad1.0x1.5mm
JP14: INV_RI; SolderJumper-3_P1.3mm_Open_RoundedPad1.0x1.5mm
JP15: TX_FILTER; SolderJumper-3_P1.3mm_Open_RoundedPad1.0x1.5mm
K1: HK19F-DC
M1, M2, M3, M4: Mounting; M3_pin
R1, R2, R3, R8, R10, R12, R14, R15, R16, R25: 2k2; R_Axial_DIN0207_L6.3mm_D2.5mm_P10.16mm_Horizontal
R4: 2k2*; R_Axial_DIN0207_L6.3mm_D2.5mm_P10.16mm_Horizontal
R17: 2k; R_Axial_DIN0207_L6.3mm_D2.5mm_P10.16mm_Horizontal
R18: 10k*; R_Axial_DIN0207_L6.3mm_D2.5mm_P10.16mm_Horizontal
R19: 1k; R_Axial_DIN0207_L6.3mm_D2.5mm_P10.16mm_Horizontal
R21: 10k; R_Axial_DIN0207_L6.3mm_D2.5mm_P10.16mm_Horizontal
SW1: SET_1200; SW_Tactile_SPST_Angled_PTS645Vx39-2LFS
SYM1: DC_5V; PWR_Specification
U1: 74HCT244; DIP-20_W7.62mm_Socket_LongPads
U2, U5: 74HCT04; DIP-14_W7.62mm_Socket_LongPads
U3, U4: MAX232; DIP-16_W7.62mm_Socket_LongPads
U6: 74HCT32; DIP-14_W7.62mm_Socket_LongPads

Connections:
+3.3V: A1.11 (3.3V), A1.16 (3.3V), A1.25 (3.3V), R18.1
+5V: A1.15 (VIN), A2.1 (VCC), C2.2, C6.1, C7.1, C8.1, C12.2, C17.1, C18.1, C19.1, D2.2 (A), D3.2 (A), D4.2 (A), D5.2 (A), D6.2 (A), D7.2 (A), D8.2 (A), D9.2 (A), D10.2 (A), J3.1 (VCC), J3.21 (VCC), J5.1 (VCC), JP2.2 (B), K1.8 (NO_1), K1.9 (NO_2), R21.2, U1.20 (VCC), U2.14 (VCC), U3.16 (VCC), U4.16 (VCC), U5.14 (VCC), U6.14 (VCC)
/232_CTS: JP11.2 (C), U1.8 (1A3)
/232_RTS: JP9.3 (B), U1.16 (1Y1), U2.5
/232_RX: JP10.2 (C), U1.6 (1A2)
/232_TX: JP8.1 (A), U1.18 (1Y0), U2.3
/C64_CTS: J5.5 (CTS), U1.11 (2A3)
/C64_RTS: J5.4 (RTS), U1.5 (2Y1)
/C64_RX: J5.3 (RX), U1.13 (2A2)
/C64_TX: J5.2 (TX), U1.3 (2Y0)
/Front Panel/LED_C64: D9.1 (K), J3.12 (C64), R16.2
/Front Panel/LED_CTS: D6.1 (K), J3.8 (CTS), R12.2
/Front Panel/LED_DCD: D10.1 (K), J3.9 (DCD), R25.2
/Front Panel/LED_POW: D2.1 (K), J3.3 (POW), R4.2
/Front Panel/LED_RI: D3.1 (K), J3.10 (RI), R2.2
/Front Panel/LED_RS232: D8.1 (K), J3.11 (RS-232), R15.2
/Front Panel/LED_RTS: D7.1 (K), J3.7 (RTS), R14.2
/Front Panel/LED_RX: D4.1 (K), J3.6 (RX), R8.2
/Front Panel/LED_STB: D13.1 (K), J3.4 (STB), R3.2
/Front Panel/LED_TX: D5.1 (K), J3.5 (TX), R10.2
/RS-232/DCE_CTS: J2.7, JP5.2 (C)
/RS-232/DCE_RTS: J2.8, JP6.2 (C)
/RS-232/DCE_RxD: J2.3, JP3.2 (C)
/RS-232/DCE_TxD: J2.2, JP4.2 (C)
/RS-232/SER_CTS: JP5.1 (A), JP6.3 (B), U3.8 (R2IN)
/RS-232/SER_DCD: J2.1, JP13.1 (A), U4.14 (T1OUT)
/RS-232/SER_RI: J2.9, U4.7 (T2OUT)
/RS-232/SER_RTS: JP5.3 (B), JP6.1 (A), U3.7 (T2OUT)
/RS-232/SER_RxD: JP3.1 (A), JP4.3 (B), U3.13 (R1IN)
/RS-232/SER_TxD: JP3.3 (B), JP4.1 (A), U3.14 (T1OUT)
/TX_FILTER: A1.27 (D3), JP15.3 (B)
AUDIO_RX: A1.22 (D6), A2.5 (AUDIO_TX)
AUDIO_TX: A1.21 (D7), A2.6 (AUDIO_RX)
ESP_CTS: R19.1, U1.9 (2Y3), U1.12 (1Y3), U5.5
ESP_DCD: J5.6 (DCD), JP12.3 (B), U2.13, U5.9, U6.6
ESP_RI: J5.7 (RI), JP14.3 (B), U2.1, U5.11, U6.8
ESP_RTS: A1.28 (D2), U1.4 (1A1), U1.15 (2A1), U5.3
ESP_RX: D14.1 (K), R8.1, U1.7 (2Y2), U1.14 (1Y2)
ESP_TX: R10.1, U1.2 (1A0), U1.17 (2A0), U6.3
GND: A1.10 (GND), A1.14 (GND), A1.17 (GND), A1.24 (GND), A2.2 (GND), A2.7 (GND), C1.2, C4.1, C6.2, C7.2, C8.2, C13.1, C17.2, C18.2, C19.2, J1.2, J1.3, J2.5, J3.2 (GND), J3.20 (GND), J5.9 (GND), J5.10 (GND), J5.11 (GND), J5.12 (GND), J5.13 (GND), J5.14 (GND), J5.15 (GND), JP1.1 (A), JP7.1 (A), JP15.1 (A), M1.1, M2.1, M3.1, M4.1, R1.1, R3.1, R4.1, R17.1, SW1.2, U1.10 (GND), U2.7 (GND), U3.15 (GND), U4.8 (R2IN), U4.13 (R1IN), U4.15 (GND), U5.7 (GND), U6.5, U6.7 (GND), U6.10, U6.12, U6.13
MODE_232: R15.1, U1.1 (1OE), U5.12
MODE_C64: R16.1, U1.19 (2OE), U5.2, U5.13
MODE_SEL: J3.18 (MODE_SEL), JP7.2 (B), R21.1, U5.1
unnamed: A1.30 (D0), SW1.1
unnamed: A1.29 (D1), R17.2, R19.2
unnamed: A1.26 (D4), U6.4
unnamed: A1.23 (D5), U6.9
unnamed: A1.19 (RX), D14.2 (A), R18.2
unnamed: A1.18 (TX), U6.2
unnamed: D11.2 (A), J1.1
unnamed: D12.1 (K), R1.2
unnamed: JP8.3 (B), U2.4
unnamed: JP8.2 (C), U3.11 (T1IN)
unnamed: JP9.1 (A), U2.6
unnamed: JP9.2 (C), U3.10 (T2IN)
unnamed: JP10.1 (A), U2.9, U3.12 (R1OUT)
unnamed: JP10.3 (B), U2.8
unnamed: JP11.1 (A), U2.10
unnamed: JP11.3 (B), U2.11, U3.9 (R2OUT)
unnamed: JP12.1 (A), U2.12
unnamed: JP12.2 (C), U4.11 (T1IN)
unnamed: J2.4, J2.6, JP13.2 (B)
unnamed: JP14.1 (A), U2.2
unnamed: JP14.2 (C), U4.10 (T2IN)
unnamed: JP15.2 (C), U6.1
unnamed: C12.1, U4.2 (VS+)
unnamed: C13.2, U4.6 (VS-)
PWR_EN: D1.2 (A), J3.19 (PWR_EN), JP1.2 (B), K1.16
VIN: C1.1, D1.1 (K), D11.1 (K), JP2.1 (A), K1.1, K1.4 (COM_1), K1.13 (COM_2)
VSB: D12.2 (A), D13.2 (A), J3.17 (VSB), K1.11 (NC_2)

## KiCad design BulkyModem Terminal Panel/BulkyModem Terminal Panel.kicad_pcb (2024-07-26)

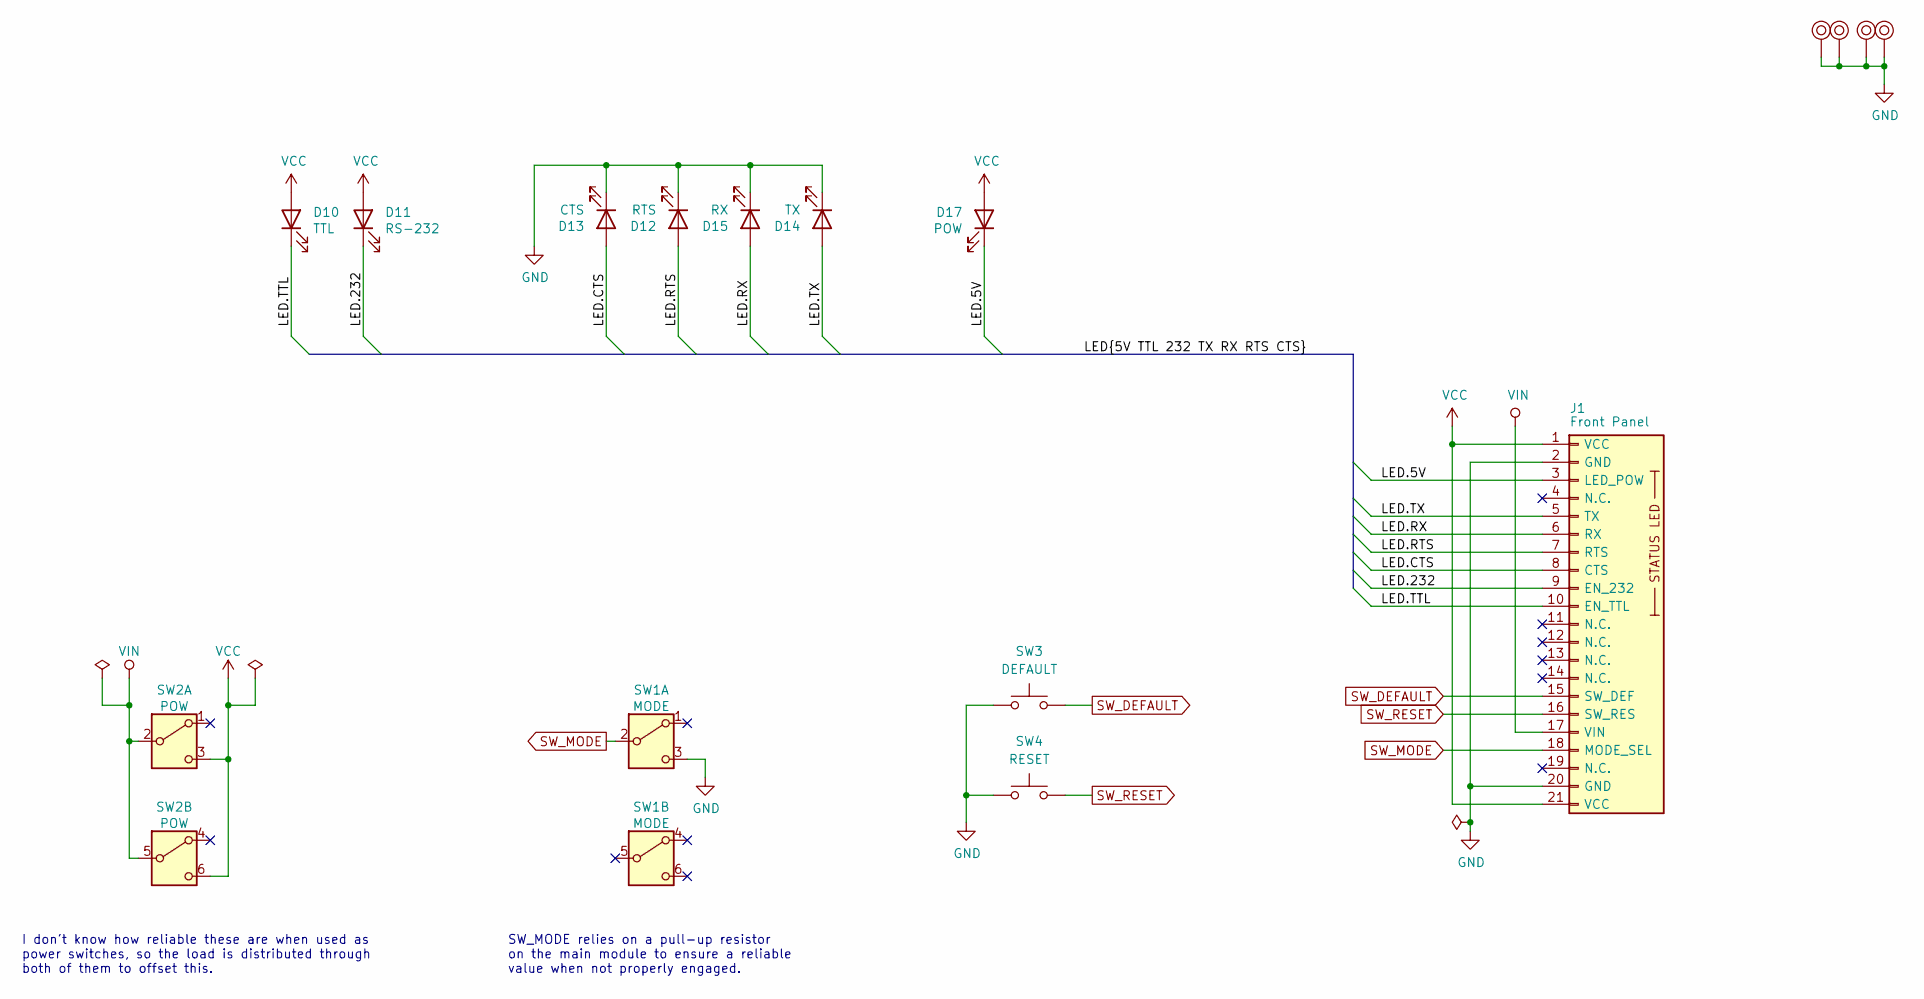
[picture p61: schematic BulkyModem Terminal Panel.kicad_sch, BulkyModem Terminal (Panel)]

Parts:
D10: TTL; LED_D5.0mm
D11: RS-232; LED_D5.0mm
D12: RTS; LED_D5.0mm
D13: CTS; LED_D5.0mm
D14: TX; LED_D5.0mm
D15: RX; LED_D5.0mm
D17: POW; LED_D5.0mm
J1: Front Panel; PinHeader_1x21_P2.54mm_Horizontal
M1, M2, M3, M4: Mounting_Pin; M3_pin
SW1: MODE; dpdt_switch_black
SW2: POW; dpdt_switch_black
SW3: DEFAULT; SW_PUSH_6mm
SW4: RESET; SW_PUSH_6mm

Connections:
/LED.5V: D17.1 (K), J1.3 (LED_POW)
/LED.232: D11.1 (K), J1.9 (EN_232)
/LED.CTS: D13.2 (A), J1.8 (CTS)
/LED.RTS: D12.2 (A), J1.7 (RTS)
/LED.RX: D15.2 (A), J1.6 (RX)
/LED.TTL: D10.1 (K), J1.10 (EN_TTL)
/LED.TX: D14.2 (A), J1.5 (TX)
GND: D12.1 (K), D13.1 (K), D14.1 (K), D15.1 (K), J1.2 (GND), J1.20 (GND), M1.1, M2.1, M3.1, M4.1, SW1.3 (C), SW3.1, SW4.1
SW_DEFAULT: J1.15 (SW_DEF), SW3.2
SW_MODE: J1.18 (MODE_SEL), SW1.2 (B)
SW_RESET: J1.16 (SW_RES), SW4.2
VCC: D10.2 (A), D11.2 (A), D17.2 (A), J1.1 (VCC), J1.21 (VCC), SW2.3 (C), SW2.6 (C)
VIN: J1.17 (VIN), SW2.2 (B), SW2.5 (B)

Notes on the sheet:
SW_MODE relies on a pull-up resistor on the main module to ensure a reliable value when not properly engaged.
I don't know how reliable these are when used as power switches, so the load is distributed through both of them to offset this.

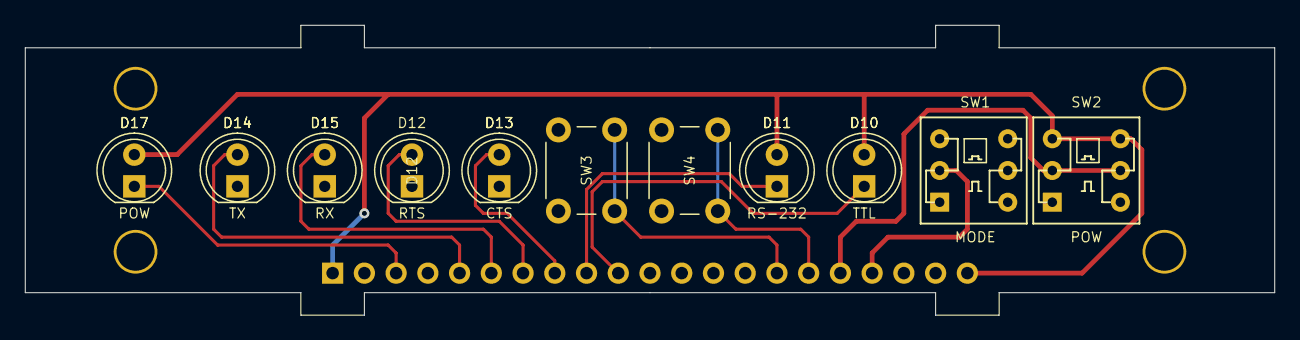
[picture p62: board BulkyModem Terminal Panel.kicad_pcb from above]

Board: 2 copper layers, 100.0 x 23.2 mm, 16 parts (1 on the bottom side), 13 nets.

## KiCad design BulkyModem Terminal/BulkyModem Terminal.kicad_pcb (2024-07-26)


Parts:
D1, D3: 1N4148; D_DO-35_SOD27_P7.62mm_Horizontal
M1, M2, M3, M4: Mounting; M3_pin
R1, R2: 1k; R_Axial_DIN0207_L6.3mm_D2.5mm_P10.16mm_Horizontal
R31: 10k; R_Axial_DIN0207_L6.3mm_D2.5mm_P10.16mm_Horizontal
SW1: RESET; SW_Tactile_SPST_Angled_PTS645Vx39-2LFS
SW2: DEFAULTS; SW_Tactile_SPST_Angled_PTS645Vx39-2LFS
U1: Pico; RPi_Pico_SMD_TH

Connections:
+3.3V: R1.1, R2.1, U1.36 (3V3); also elsewhere on the board
+5V: U1.39 (VSYS); also elsewhere on the board
B0: U1.1 (GPIO0); also elsewhere on the board
B1: U1.2 (GPIO1); also elsewhere on the board
BUZZER: U1.12 (GPIO9); also elsewhere on the board
DEFAULTS: SW2.2, U1.29 (GPIO22); also elsewhere on the board
G0: U1.4 (GPIO2); also elsewhere on the board
G1: U1.5 (GPIO3); also elsewhere on the board
G2: U1.6 (GPIO4); also elsewhere on the board
GND: M1.1, M2.1, M3.1, M4.1, R31.2, SW1.1, SW2.1, U1.3 (GND), U1.8 (GND), U1.13 (GND), U1.18 (GND), U1.23 (GND), U1.28 (GND), U1.33 (AGND), U1.38 (GND), U1.42 (GND); also elsewhere on the board
unnamed: D1.2 (A), R1.2, U1.27 (GPIO21)
unnamed: D3.2 (A), R2.2, U1.31 (GPIO26_ADC0)
unnamed: R31.1, U1.34 (GPIO28_ADC2)
PS2.CLK: U1.15 (GPIO11); also elsewhere on the board
PS2.DAT: U1.14 (GPIO10); also elsewhere on the board
Pico.CTS: D3.1 (K); also elsewhere on the board
Pico.RTS: U1.32 (GPIO27_ADC1); also elsewhere on the board
Pico.RxD: D1.1 (K); also elsewhere on the board
Pico.TxD: U1.26 (GPIO20); also elsewhere on the board
R0: U1.7 (GPIO5); also elsewhere on the board
R1: U1.9 (GPIO6); also elsewhere on the board
R2: U1.10 (GPIO7); also elsewhere on the board
RESET: SW1.2, U1.30 (RUN); also elsewhere on the board
SYNC: U1.11 (GPIO8); also elsewhere on the board

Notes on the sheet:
These switches are duplicated on the front panel. While no harm will come from installing both, you only need one set.
R31 pulls down HDMI detect, mainly because we don't actually have one.


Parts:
C2, C3, C4, C5: 1uF; CP_Radial_D4.0mm_P2.00mm_Custom
J2: RS-232; DSUB-9_Male_Horizontal_P2.77x2.84mm_EdgePinOffset7.70mm_Hou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
J5: TTL; PinHeader_1x06_P2.54mm_Horizontal
R15, R16, R20, R21: 100; R_Axial_DIN0207_L6.3mm_D2.5mm_P10.16mm_Horizontal
U2: 74HCT244; DIP-20_W7.62mm_Socket_LongPads
U3: MAX232; DIP-16_W7.62mm_Socket_LongPads

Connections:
232.CTS: U2.8 (1A3), U3.9 (R2OUT)
232.RTS: U2.16 (1Y1), U3.11 (T1IN)
232.RxD: U2.6 (1A2), U3.12 (R1OUT)
232.TxD: U2.18 (1Y0), U3.10 (T2IN)
+5V: C2.2, J5.5, U2.20 (VCC), U3.16 (VCC); also elsewhere on the board
/Serial/DTE.CTS: J2.8, U3.8 (R2IN)
/Serial/DTE.RTS: J2.7, U3.14 (T1OUT)
/Serial/DTE.RxD: J2.2, U3.13 (R1IN)
/Serial/DTE.TxD: J2.3, U3.7 (T2OUT)
GND: C4.1, J2.0 (S), J2.5, J5.6, U2.10 (GND), U3.15 (GND); also elsewhere on the board
MODE_232: U2.1 (1OE); also elsewhere on the board
MODE_TTL: U2.19 (2OE); also elsewhere on the board
unnamed: R15.1, U2.13 (2A2)
unnamed: R21.1, U2.11 (2A3)
unnamed: R20.2, U2.3 (2Y0)
unnamed: R16.2, U2.5 (2Y1)
unnamed: C5.1, U3.1 (C1+)
unnamed: C5.2, U3.3 (C1-)
unnamed: C3.1, U3.4 (C2+)
unnamed: C3.2, U3.5 (C2-)
unnamed: C2.1, U3.2 (VS+)
unnamed: C4.2, U3.6 (VS-)
Pico.CTS: U2.9 (2Y3), U2.12 (1Y3); also elsewhere on the board
Pico.RTS: U2.4 (1A1), U2.15 (2A1); also elsewhere on the board
Pico.RxD: U2.7 (2Y2), U2.14 (1Y2); also elsewhere on the board
Pico.TxD: U2.2 (1A0), U2.17 (2A0); also elsewhere on the board
TTL.CTS: J5.3, R21.2
TTL.RTS: J5.4, R16.1
TTL.RxD: J5.1, R15.2
TTL.TxD: J5.2, R20.1

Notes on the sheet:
C2-C5 must be electrolytic 1uF when using older or cheaper MAX232 variants, these can be replaced with standard 100nF when used along with MAX232A variant.
RTS
TxD
CTS
RxD


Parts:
D4: RX; LED_D3.0mm
D5: TX; LED_D3.0mm
D6: CTS; LED_D3.0mm
D7: RTS; LED_D3.0mm
D8: RS-232; LED_D3.0mm
D9: TTL; LED_D3.0mm
J3: Module_Panel; Terminal_Panel
JP2: 232_SW; PinHeader_1x02_P2.54mm_Vertical
R4, R8, R10, R12, R14, R23, R24: 2k2; R_Axial_DIN0207_L6.3mm_D2.5mm_P10.16mm_Horizontal
R22: 10k; R_Axial_DIN0207_L6.3mm_D2.5mm_P10.16mm_Horizontal
U5: 74HCT04; DIP-14_W7.62mm_Socket_LongPads

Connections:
+5V: D8.2 (A), D9.2 (A), J3.1 (VCC), J3.21 (VCC), R22.2; also elsewhere on the board
/Front Panel/LED.232: D8.1 (K), J3.9 (EN_232), R23.2
/Front Panel/LED.CTS: D6.2 (A), J3.8 (CTS), R12.2
/Front Panel/LED.POW: J3.3 (LED_POW), R4.2
/Front Panel/LED.RTS: D7.2 (A), J3.7 (RTS), R14.2
/Front Panel/LED.RX: D4.2 (A), J3.6 (RX), R8.2
/Front Panel/LED.TTL: D9.1 (K), J3.10 (EN_TTL), R24.2
/Front Panel/LED.TX: D5.2 (A), J3.5 (TX), R10.2
DEFAULTS: J3.15 (SW_DEF); also elsewhere on the board
GND: D4.1 (K), D5.1 (K), D6.1 (K), D7.1 (K), J3.2 (GND), J3.20 (GND), JP2.1 (A), R4.1; also elsewhere on the board
MODE_232: R23.1, U5.12; also elsewhere on the board
MODE_SEL: J3.18 (MODE_SEL), JP2.2 (B), R22.1, U5.1
MODE_TTL: R24.1, U5.2, U5.13; also elsewhere on the board
Pico.CTS: U5.5; also elsewhere on the board
Pico.RTS: U5.3; also elsewhere on the board
Pico.RxD: U5.11; also elsewhere on the board
Pico.TxD: U5.9; also elsewhere on the board
RESET: J3.16 (SW_RES); also elsewhere on the board
VIN: J3.17 (VIN); also elsewhere on the board

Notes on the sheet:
JP7 is intended as a way of enabling *one* of the two modes when a front panel has not been installed, jumpering it will override the switches on the panel.


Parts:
C1: 470uF; CP_Radial_D8.0mm_P3.50mm
C6, C7, C17, C19: 100nF; C_Disc_D4.7mm_W2.5mm_P5.00mm
D2: 5V; LED_D3.0mm
D10: 5V; LED_D3.0mm_Horizontal_O1.27mm_Z2.0mm
D11: 1N5819; D_DO-41_SOD81_P10.16mm_Horizontal
D13: 3V3; LED_D3.0mm
J1: DC IN; BARREL_JACK
JP1: PWR_SW; PinHeader_1x02_P2.54mm_Vertical
R3, R32, R33: 2k2; R_Axial_DIN0207_L6.3mm_D2.5mm_P10.16mm_Horizontal
SYM1: DC_5V; PWR_Specification
U5: 74HCT04; DIP-14_W7.62mm_Socket_LongPads

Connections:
+3.3V: C6.1, D13.2 (A); also elsewhere on the board
+5V: C1.1, C7.1, C17.1, C19.1, D2.2 (A), D10.2 (A), JP1.2 (B), U5.14 (VCC); also elsewhere on the board
GND: C1.2, C6.2, C7.2, C17.2, C19.2, J1.2, J1.3, R3.1, R32.1, R33.1, U5.7 (GND); also elsewhere on the board
unnamed: D2.1 (K), R3.2
unnamed: D10.1 (K), R33.2
unnamed: D11.2 (A), J1.1
unnamed: D13.1 (K), R32.2
VIN: D11.1 (K), JP1.1 (A); also elsewhere on the board

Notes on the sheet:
Device is powered when either JP1 is linked, or power is instead coming in via the power switch on front panel. Note that 3.3v is regulated by Pico.
The second 5V LED (D10) is on the underside, ideally lighting up the cutouts one the bottom of the front panel. It's dumb. I know.


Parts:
C9: 100uF; CP_Radial_D5.0mm_P2.50mm
LS1: Speaker; Buzzer_12x9.5RM7.6
Q1: 2N3904; TO-92_Inline_Wide
R25: 680; R_Axial_DIN0207_L6.3mm_D2.5mm_P10.16mm_Horizontal
R26: 220; R_Axial_DIN0207_L6.3mm_D2.5mm_P10.16mm_Horizontal

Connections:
+5V: R26.1; also elsewhere on the board
BUZZER: R25.2; also elsewhere on the board
GND: LS1.2, Q1.1 (E); also elsewhere on the board
unnamed: C9.2, LS1.1
unnamed: Q1.2 (B), R25.1
unnamed: C9.1, Q1.3 (C), R26.2

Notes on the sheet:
R25 value was pulled out of a hat, may need adjusting to something that won't set the transistor on fire.


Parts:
J6: PS/2_Connector; MINI-DIN-6-FULL-SHIELD
Q2, Q3: 2N7000; TO-92_Inline_Wide
R27, R28, R29, R30: 4k7; R_Axial_DIN0207_L6.3mm_D2.5mm_P10.16mm_Horizontal

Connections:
+3.3V: Q2.2 (G), Q3.2 (G), R29.1, R30.1; also elsewhere on the board
+5V: J6.4, R27.1, R28.1; also elsewhere on the board
GND: J6.3; also elsewhere on the board
unnamed: J6.1, Q2.3 (D), R27.2
unnamed: J6.5, Q3.3 (D), R28.2
PS2.CLK: Q3.1 (S), R29.2; also elsewhere on the board
PS2.DAT: Q2.1 (S), R30.2; also elsewhere on the board

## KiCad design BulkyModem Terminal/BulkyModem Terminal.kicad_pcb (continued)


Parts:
J4: VGA; DSUB-15
R5: 100; R_Axial_DIN0207_L6.3mm_D2.5mm_P10.16mm_Horizontal
R6, R13: 2k2; R_Axial_DIN0207_L6.3mm_D2.5mm_P10.16mm_Horizontal
R7, R11, R19: 1k; R_Axial_DIN0207_L6.3mm_D2.5mm_P10.16mm_Horizontal
R9, R17: 470; R_Axial_DIN0207_L6.3mm_D2.5mm_P10.16mm_Horizontal
R18: 390; R_Axial_DIN0207_L6.3mm_D2.5mm_P10.16mm_Horizontal

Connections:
/VGA/VGA.B: J4.3, R18.2, R19.2
/VGA/VGA.G: J4.2, R11.2, R13.2, R17.2
/VGA/VGA.R: J4.1, R6.2, R7.2, R9.2
B0: R19.1; also elsewhere on the board
B1: R18.1; also elsewhere on the board
G0: R13.1; also elsewhere on the board
G1: R11.1; also elsewhere on the board
G2: R17.1; also elsewhere on the board
GND: J4.0, J4.5, J4.6, J4.7, J4.8, J4.10; also elsewhere on the board
unnamed: J4.13, R5.1
R0: R6.1; also elsewhere on the board
R1: R7.1; also elsewhere on the board
R2: R9.1; also elsewhere on the board
SYNC: R5.2; also elsewhere on the board



Board: 2 copper layers, 100.0 x 100.0 mm, 78 parts (2 on the bottom side), 70 nets.

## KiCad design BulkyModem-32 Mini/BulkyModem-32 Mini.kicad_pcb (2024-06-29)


Board: 2 copper layers, 38.7 x 73.0 mm, 25 parts (0 on the bottom side), 27 nets.

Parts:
A1: ESP32-WROOM-32; ESP32-WROOM-32D_30_Alternate
C1, C8: 100nF; C_Disc_D4.7mm_W2.5mm_P5.00mm
C2, C3, C4, C5: 1uF; CP_Radial_D4.0mm_P2.00mm_Custom
D1: TX; LED_D3.0mm
D2: RX; LED_D3.0mm
D3: RTS; LED_D3.0mm
D4: CTS; LED_D3.0mm
D5: DCD; LED_D3.0mm
D14, D15: 1N4148; D_DO-35_SOD27_P7.62mm_Horizontal
J1: SD_CARD; PinHeader_1x06_P2.54mm_Vertical
J2: DCE; DSUB-9_Female_Horizontal_P2.77x2.84mm_EdgePinOffset7.70mm_H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
R1, R2, R3, R4, R6: 2k2; R_Axial_DIN0207_L6.3mm_D2.5mm_P10.16mm_Horizontal
R5, R18: 10k; R_Axial_DIN0207_L6.3mm_D2.5mm_P10.16mm_Horizontal
U3: MAX232; DIP-16_W7.62mm_Socket_LongPads
U6: 74HCT32; DIP-14_W7.62mm_Socket_LongPads

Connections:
+3.3V: A1.16 (3.3V), J1.1, R5.1, R18.1
+5V: A1.15 (VIN), C1.1, C2.2, C8.1, D1.2 (A), D2.2 (A), D3.2 (A), D4.2 (A), D5.2 (A), U3.16 (VCC), U6.14 (VCC)
/RS-232/SER_CTS: J2.7, U3.8 (R2IN)
/RS-232/SER_RTS: J2.8, U3.7 (T2OUT)
/RS-232/SER_RxD: J2.3, U3.13 (R1IN)
/RS-232/SER_TxD: J2.2, U3.14 (T1OUT)
ESP_CTS: D15.1 (K), R4.1, U3.9 (R2OUT)
ESP_DCD: R6.1, U6.6
ESP_RTS: R3.1, U3.10 (T2IN), U6.11
ESP_RX: D14.1 (K), R2.1, U3.12 (R1OUT)
ESP_TX: R1.1, U3.11 (T1IN), U6.3
GND: A1.14 (GND), A1.17 (GND), C1.2, C4.1, C8.2, J1.6, J2.5, U3.15 (GND), U6.1, U6.5, U6.7 (GND), U6.9, U6.10, U6.13
unnamed: A1.13 (D13), D15.2 (A), R5.2
unnamed: A1.11 (D14), U6.4
unnamed: A1.18 (D15), U6.12
unnamed: A1.21 (D16), D14.2 (A), R18.2
unnamed: A1.22 (D17), U6.2
unnamed: D1.1 (K), R1.2
unnamed: D2.1 (K), R2.2
unnamed: D3.1 (K), R3.2
unnamed: D4.1 (K), R4.2
unnamed: D5.1 (K), R6.2
unnamed: J2.1, J2.4, J2.6
SPI_CLK: A1.24 (D18), J1.4
SPI_CS: A1.23 (D5), J1.2
SPI_MISO: A1.25 (D19), J1.5
SPI_MOSI: A1.30 (D23), J1.3

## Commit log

2022-07-20 RS232 side mostly complete
    [BulkyModem Module.kicad_pcb, BulkyModem Module.sch, c64_userport.sch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]
2022-07-21 C64 UserPort adapter sketched out (preliminary layout)
    [BulkyModem Module.sch, BulkyModem UserPort Adapter.kicad_pcb, BulkyModem UserPort Adapter.sch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]
2022-07-22 Add MCU footprints
    [BulkyModem Module.sch]
2022-07-23 Front panel
    [BulkyModem Module Panel.kicad_pcb, BulkyModem Module Panel.sch]
2022-07-23 Double up power switch
    [BulkyModem Module Panel.kicad_pcb, BulkyModem Module Panel.sch]
2022-07-24 Add DCD
    [BulkyModem Module Panel.kicad_pcb, BulkyModem Module Panel.sch, BulkyModem Module.sch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]
2022-07-24 Initial layout
    [BulkyModem Module.kicad_pcb, BulkyModem Module.sch, c64_userport.sch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]
2022-07-24 Changed IDC pin count
    [BulkyModem UserPort Adapter.kicad_pcb, BulkyModem UserPort Adapter.sch]
2022-07-24 Add RI LED
    [BulkyModem Module Panel.kicad_pcb, BulkyModem Module Panel.sch]
2022-07-25 Silkscreen tweaks
    [BulkyModem Module.kicad_pcb]
2022-07-25 Buffer RI and DCD with spare gates
    [BulkyModem Module.kicad_pcb, BulkyModem Module.sch, power.sch]
2022-07-25 BulkyModem FA1
    [BulkyModem FA1.kicad_pcb, BulkyModem FA1.sch]
2022-07-26 BulkyModem FP1
    [BulkyModem FP1.kicad_pcb, BulkyModem FP1.sch]
2022-08-24 Slightly larger space for keycap
    [BulkyModem FP1.kicad_pcb]
2023-04-09 Changed C64 UserPort adapter schematic
    [BulkyModem UserPort Adapter.sch]
2023-04-09 Tweak schematic in order to fix LEDs and default jumper settings moved to working configuration
    [BulkyModem Module.kicad_pcb, BulkyModem Module.sch, front_panel.sch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]
2023-04-09 Improved faceplate FP2
    [BulkyModem FP1.sch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]
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2023-04-10 Layout updated
    [BulkyModem Module Panel.sch, BulkyModem Module.kicad_pcb, BulkyModem Module.sch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]
2023-04-11 Alternate panel designs
    [BulkyModem FA1.kicad_pcb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]
2023-04-11 Updated UserPort layout
    [BulkyModem Module.kicad_pcb, BulkyModem Module.sch, BulkyModem UserPort Adapter.kicad_pcb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]
2024-04-09 Revised version. Mainly buffering signals
    [BulkyModem FP1.kicad_pcb, BulkyModem FP2.kicad_pcb, BulkyModem Module.kicad_pcb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]
2024-04-09 Moved UP9600 jumpers
    [BulkyModem UserPort Adapter.kicad_pcb]
2024-04-12 Export files
    [BulkyModem UserPort Adapter.sch]
2024-05-06 Tweaks needed to make revision C actually work.
    [BulkyModem Module Panel B.kicad_pcb, BulkyModem Module Panel B.sch, BulkyModem Module.kicad_pcb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]
2024-05-06 Upgrade to KiCAD8
    [BulkyModem Module.kicad_pcb, BulkyModem Module.kicad_sch, c64_userport.kicad_sch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]
2024-05-07 Add mounting points for audio module
    [BulkyModem Module.kicad_pcb, BulkyModem Module.kicad_sch, audio_panel.kicad_sch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]
2024-05-09 New UserPort Adapter
    [BulkyModem UserPort Adapter.kicad_pcb, BulkyModem UserPort Adapter.kicad_sch, Power.kicad_sch]
2024-05-17 Change UserPort transmitter to only enable on both parties present
    [BulkyModem UserPort Adapter.kicad_pcb, BulkyModem UserPort Adapter.kicad_sch, Power.kicad_sch]
2024-05-28 Exported files
    [BulkyModem Module Audio-B_Cu.gbl, BulkyModem Module Audio-B_Mask.gbs, BulkyModem Module Audio-B_Paste.gbp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]
2024-05-28 Added new faceplate
    [BulkyModem FP3.kicad_pcb, BulkyModem FP3.kicad_sch, BulkyModem FP3.sch]
2024-05-30 Change some resistor values
    [BulkyModem Module Panel B.kicad_pcb, BulkyModem Module Panel B.kicad_sch, BulkyModem Module.kicad_pcb]
2024-05-30 Update project
    [BulkyModem Module Panel B.kicad_sch, BulkyModem UserPort Adapter.kicad_pcb, c64_userport.kicad_sch]
2024-05-30 Add labels to LEDs
    [BulkyModem Module.kicad_pcb, BulkyModem Module.kicad_sch, front_panel.kicad_sch]
2024-06-08 Terminal schematic (first draft)
    [BulkyModem Terminal.kicad_pcb, BulkyModem Terminal.kicad_sch, BulkyModem Terminal.sch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]
2024-06-10 Part of a layout
    [BulkyModem Terminal FP3.kicad_pcb, BulkyModem Terminal FP3.kicad_sch, BulkyModem Terminal FP3.sch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]
2024-06-11 Added remaining tracks
    [BulkyModem Terminal.kicad_pcb, front_panel.kicad_sch]
2024-06-11 TTL legend
    [BulkyModem FP2.kicad_pcb, BulkyModem Terminal FP3.kicad_pcb, BulkyModem Terminal.kicad_pcb]
2024-06-15 Change PS/2 circuit
    [BulkyModem Terminal.kicad_pcb, ps2_keyboard.kicad_sch, serial.kicad_sch]
2024-06-18 BulkyModem-32 Mini
    [BulkyModem-32 Mini.kicad_pcb, BulkyModem-32 Mini.kicad_sch, BulkyModem-32 Mini.sch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]
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2024-07-18 Fixed VGA footprint to match cheap parts
    [BulkyModem Terminal.kicad_pcb, VGA.kicad_sch]
2024-07-20 Missing a trace
    [BulkyModem Terminal Panel.kicad_pcb, BulkyModem Terminal Panel.kicad_sch]
2024-07-20 Flipped serial LEDs
    [BulkyModem Terminal Panel.kicad_pcb, BulkyModem Terminal Panel.kicad_sch, BulkyModem Terminal.kicad_pcb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]
2024-07-22 Move PS/2 port to the back with some caveats, basically needs a custom top panel
    [BulkyModem FA1.kicad_pcb, BulkyModem Terminal FA1.kicad_pcb, BulkyModem Terminal FA1.kicad_sch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]
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2024-07-29 BulkyModem-32, first layout and completed schematic
    [BulkyModem-32 Module-B_Cu.gbl, BulkyModem-32 Module-B_Mask.gbs, BulkyModem-32 Module-B_Paste.gbp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]
2024-07-29 BulkyModem-32 top and bottom
    [BulkyModem FB1.kicad_pcb, BulkyModem FB1.kicad_sch, BulkyModem FB1.sch]
2024-07-29 Simple RS-232 adapter for C64 UserPort
    [BulkyModem RS-232 Adapter.kicad_pcb, BulkyModem RS-232 Adapter.kicad_sch, BulkyModem RS-232 Adapter.sch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]
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2024-10-09 Accidentally lost top label
    [BulkyModem FP1.kicad_pcb, BulkyModem FP2.kicad_pcb]
2024-10-12 Changed FP1 labels to match FP2
    [BulkyModem FP1.kicad_pcb]
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

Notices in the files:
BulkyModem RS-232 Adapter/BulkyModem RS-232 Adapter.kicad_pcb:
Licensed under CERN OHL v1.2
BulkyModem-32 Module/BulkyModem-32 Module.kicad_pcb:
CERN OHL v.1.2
